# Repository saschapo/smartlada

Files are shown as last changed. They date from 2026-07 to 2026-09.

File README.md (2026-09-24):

# SmartLada — smart VAZ-2106 tail light

Firmware and custom hardware for a "smart" VAZ-2106 tail light: PWM dimming of the four
lamps (turn / brake / marker / reverse) with a local OLED menu, animation effects, and
**Zigbee control from a Yandex Station (Alice)**. Runs on a custom board that drops into
the light housing and is powered over **USB-C PD**.

Project page: **[smartlada.saschapo.me](https://smartlada.saschapo.me)** (source in [`site/`](site/)).

The current, primary firmware is **[`SmartLadaRevC/`](SmartLadaRevC/)** — it targets the
Rev C product board and is what the project ships. Everything else in the tree is either
the hardware design or earlier development stages (see [Lineage](#lineage)).

## Main firmware — SmartLadaRevC

ESP32-C6-WROOM-1 firmware for the Rev C board. Four PWM lamp channels (low-side MOSFET,
gamma + soft-start), an OLED menu with four buttons, pluggable effects, and a Zigbee end
device exposing five endpoints to Alice (four individual lamps + a "Fara" master/effects
device). Local control and Zigbee share one state (`config::s`, last-writer-wins).

Full details: **[`SmartLadaRevC/README.md`](SmartLadaRevC/README.md)**.

### Hardware (Rev C board)

<p align="center">
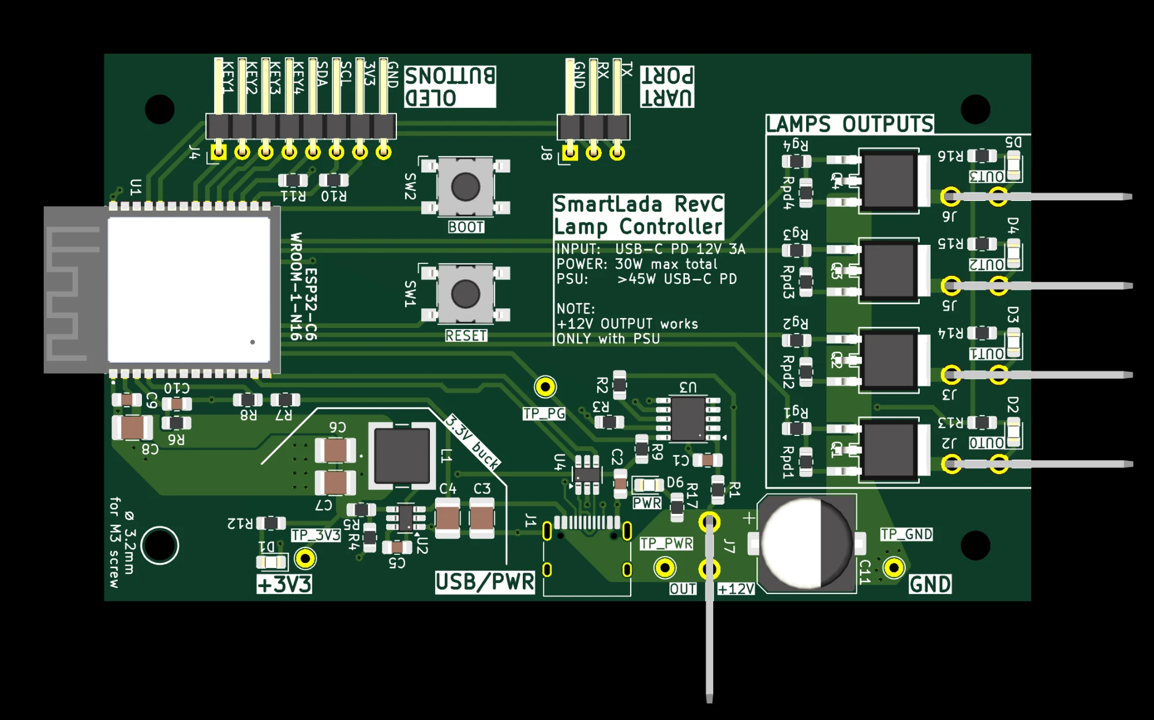
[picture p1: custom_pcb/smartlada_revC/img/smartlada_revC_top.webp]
SmartLada Rev C, top side
  
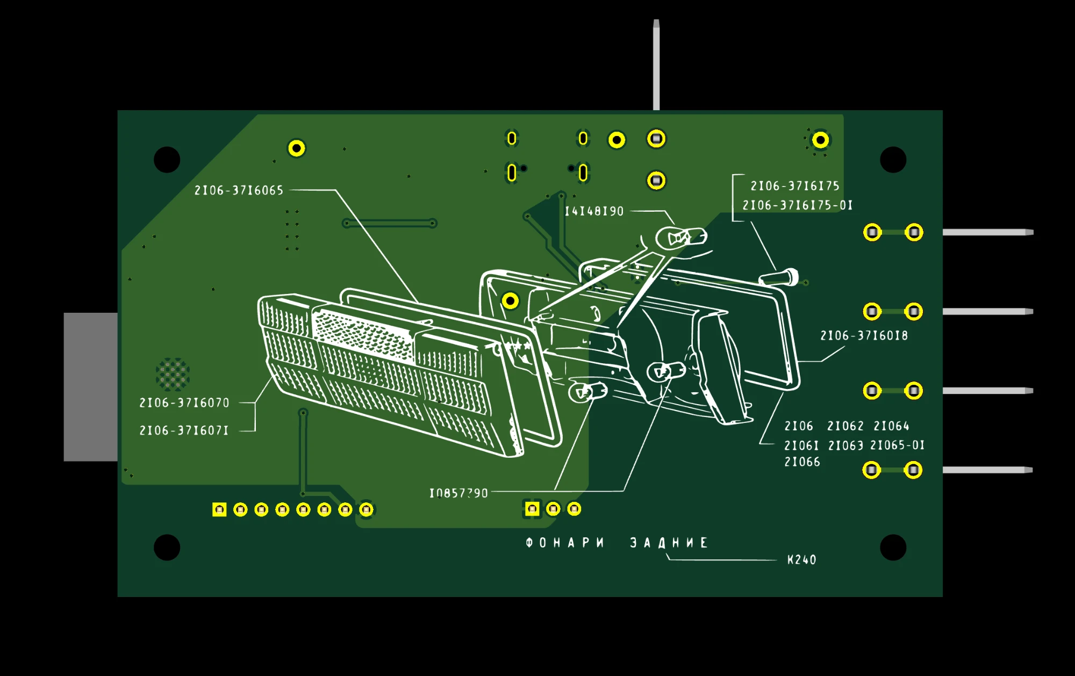
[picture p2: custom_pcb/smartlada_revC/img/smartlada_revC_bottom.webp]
SmartLada Rev C, bottom side
  
</p>
<p align="center"><sub>Rev C, KiCad render. Top: ESP32-C6 module, buck, PD trigger, four lamp MOSFETs with
Faston outputs. Bottom: the silkscreen carries the VAZ-2106 tail-light exploded view from the parts
catalogue ("ФОНАРИ ЗАДНИЕ").</sub></p>

- **MCU:** ESP32-C6-WROOM-1-N16 (integrated on the board).
- **Power in:** USB-C PD, **12 V / 3 A trigger** (CH224K). 12 V feeds the lamps directly;
  a **TPS54202 buck** makes 3.3 V for the MCU/OLED. No 12 V → holds 5 V (logic alive, lamps dark).
  Recommended PSU: **COMMO Core** (a model with a 12 V/3 A PDO).
- **Lamp switches:** 4× AOD4184 N-MOSFET (low-side, gate active-high), outputs on **6.3 mm
  Faston tabs** with a common +12 V. Lamps: 12 V incandescent (e.g. 10+10+10+5 W).
- **UI:** SSD1315 OLED (I²C) + 4 buttons on connector J4, cabled out of the housing.
- **Diagnostics:** 6× red 0805 LEDs (4 channels + 12 V + 3.3 V); PG (power-good) → GPIO.

Board design (KiCad, BOM, fabrication): **[`custom_pcb/smartlada_revC/`](custom_pcb/smartlada_revC/)**.

### Build & flash

Zigbee end-device build, Serial over native USB:

```sh
FQBN="esp32:esp32:esp32c6:ZigbeeMode=ed,PartitionScheme=zigbee_8MB,CDCOnBoot=cdc,FlashSize=16M"
arduino-cli compile -b "$FQBN" SmartLadaRevC
arduino-cli upload  -b "$FQBN" -p /dev/cu.usbmodemXXXX SmartLadaRevC
```

Bench variant with the 2.4" TFT + encoder module in place of the OLED + keys: build flag
`UI_TFT`, see [`SmartLadaRevC/README.md`](SmartLadaRevC/README.md#bench-variant-24-tft--encoder-ui_tft).

Plan and resume notes: [`SmartLadaRevC/DEV_PLAN.md`](SmartLadaRevC/DEV_PLAN.md),
[`SmartLadaRevC/SESSION_HANDOFF.md`](SmartLadaRevC/SESSION_HANDOFF.md).

## Lineage

The firmware grew through several stages; the earlier ones are kept for reference:

- [`sketches/SmartLada/`](sketches/SmartLada/) — first bring-up bench on an **ESP8266**
  (calibration, OLED). Its `channels/` and `config/` layers seeded the ESP32 port.
- [`SmartLadaC6/`](SmartLadaC6/) — **ESP32-C6 on a MuseLab nanoESP32-C6** dev board:
  LEDC PWM, Wi-Fi AP + web UI, test modes. First C6 firmware.
- [`SmartLadaRevB/`](SmartLadaRevB/) — display-based firmware (OLED menu + effects) on the
  Rev B board; direct **predecessor to Rev C** (Rev C forks its `src/` layers).
- **[`SmartLadaRevC/`](SmartLadaRevC/)** — current product firmware (this board + Zigbee).

Hardware history lives under [`custom_pcb/`](custom_pcb/) (Rev A → Rev B → Rev C);
research and architecture notes under [`research/`](research/); experimental sketches
under [`sketches/`](sketches/).

## Project context (Russian)

Historical planning/context documents, kept in Russian on purpose:

- [`PROJECT_2106_SMART_LIGHT.md`](PROJECT_2106_SMART_LIGHT.md) — decisions, hardware, architecture, plan.
- [`VAZ2106_Smart_Lamp_Context.md`](VAZ2106_Smart_Lamp_Context.md) — earlier context document.
- [`TASK_smartlada_bench_esp8266.md`](TASK_smartlada_bench_esp8266.md) — ESP8266 bench spec (done).
- [`schematic_2106_ESP32.md`](schematic_2106_ESP32.md) — early wiring schematic.

> Chat and `.md` documentation are in Russian; firmware code, comments, and identifiers are in English.

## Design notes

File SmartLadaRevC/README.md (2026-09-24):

# SmartLadaRevC

Firmware for the **SmartLada Rev C** board (ESP32-C6-WROOM-1) — the primary firmware of the
project. Controls four 12 V lamps of a VAZ-2106 tail light with PWM dimming, an OLED menu,
animation effects, and Zigbee control from a Yandex Station (Alice). Local (buttons/OLED)
and remote (Zigbee) control share one state, last-writer-wins.

Forked from `../SmartLadaRevB`; the `src/` layers are reused, plus a Zigbee layer.

## Features

- **4 PWM lamp channels** — LEDC, per-channel gamma + min/max window + soft-start slew.
- **OLED menu** (SSD1315, I²C) driven by 4 buttons: mode, brightness (per-channel + master),
  effect timings, lamp calibration (gamma/soft-start/levels/PWM freq), display, factory reset.
- **Effects**: Breathe, Turn (turn-signal-only blink, 1.5 Hz), Chase, Fade, Drive (a random
  but logical driving-scenario FSM: cruise/brake/stop/turn/reverse/hazard/parked).
  **Chase** runs on a trigger clock: every `Step` a lamp is lit and runs its own
  `Fade In -> On -> Fade Out` envelope, which may outlive later triggers — that overlap is
  what makes lamps dissolve into each other. `Random` picks the next lamp instead of walking
  in order (never the one just lit), turning the same envelope into scattered flicker.
- **Zigbee end device** — five endpoints to Alice:
  - `EP10..13` — the four lamps by function: **Turn / Marker / Reverse / Stop** (`ZigbeeDimmableLight`).
  - `EP14` "Fara" (`ZigbeeColorDimmableLight`) — the **effect layer and nothing else**:
    **color = effect selector**, **level = effect brightness**; **off and white both mean
    "no effect"**. EP14 never touches per-lamp levels.
- **Radio is a choice, not a pair.** The C6 has one 2.4 GHz radio. The libraries are built
  with software coexistence and both stacks do link together, but in practice a phone could
  not join the access point while the Zigbee stack was up. So exactly one protocol owns the
  band per boot, the choice is persisted, and switching reboots (Settings -> WiFi or
  Settings -> Zigbee on the device; one-way from the web page).
- **Wi-Fi + web UI** (Zigbee is the default): access-point first, because a car has no network
  to join -- the lamp hosts `fara_NNNN` (password `smartlada`, both editable from the page),
  with a join QR on the OLED that swaps to the address QR once a phone has associated. Station
  credentials are still honoured if stored, for bench use. The page is served from flash, so a
  firmware update carries it along and there is no filesystem image to upload. The browser is
  just another writer of the same state as the menu and Zigbee, and mirrors every setting.
- **Event log on flash** (`/log`, `/log.1`, `/clearlog`) and **firmware upload over Wi-Fi**
  (`POST /firmware`), so a bench session needs neither a cable nor a serial monitor.
- Settings + effect timings persisted in NVS, and **restored on power-on**: any change —
  local or remote — is written once it has stopped moving for 4 s.

## Architecture

Thin `.ino` wiring; logic in `src/*` layers. **`config::s` is the single source of truth**;
the menu and the Zigbee callbacks both write it (last-writer-wins), and the loop composits it:

```
setup(): channels::begin -> display -> config::load -> fx::loadParams
         -> setFreq/Calib/SoftMs -> buttons -> menu -> zb::begin (non-blocking join)
loop():  buttons::poll -> menu::update -> zb::update -> [zb::consumeDirty -> menu redraw]
         fx::compute(mode, now, master, lampOn, staticBri, out[4])           // compositor
         channels::write(now, out)                                            // slew -> gamma -> LEDC
         menu::render()                                                       // redraws only on change
```

| Layer | Role |
|---|---|
| `src/channels` | LEDC PWM (10-bit), soft-start slew on duty, gamma + min/max remap |
| `src/fx` | effects + the compositor (`compute`) |
| `src/input` | 4 buttons, debounce + accelerating repeat (EC11 encoder with `UI_TFT`) |
| `src/display`  | SSD1315 over Adafruit_SSD1306 (ST7789 TFT with `UI_TFT`) |
| `src/ui` | OLED menu state machine |
| `src/config` | NVS-backed `Settings` (`config::s`) |
| `src/net` | Zigbee endpoints + callbacks -> `config::s` |

### Compositor / control model

The `mode` alone picks the layer; EP14 (Fara) is the effect layer, EP10-13 (lamps/group) the
static picture:

- **Effect (mode ≠ 0)** → animation frame × `master` (effect brightness), across all 4 channels.
  Min Level remaps the **master**, not each frame value: `duty = frame^γ × remap(master)`, so at
  master 1% the effect peaks at Min Level and keeps its shape (Breathe still dips to dark).
- **Brightness remap** (Lamp Setup Min/Max Level + gamma): 0% = off, 1% = Min Level,
  100% = Max Level. In static every lit lamp at master > 0 stays at or above Min Level.
- **Static (mode 0)** → per-channel `staticBri`, gated by `lampOn`, then scaled by `master`.
  The master is a **ceiling**, in the spirit of Lamp Setup's Max Level: at 100% nothing is held
  back, and lowering it pulls the whole picture down while the lamps keep their relative
  balance. It is the same master that sets effect brightness, so one fader means one thing in
  both layers. Alice's group dimmer writes `staticBri`, so group and master do compound --
  which is what a ceiling is for.
- **EP14 (Fara)**: off **and** white → no effect (mode 0); color → effect (hue selects it).
  Its level is **always** the effect brightness and never fans out to `staticBri`. Fara never
  turns lamps off. A second group dimmer used to live here (white fanned its level out to
  every lamp); it duplicated EP10-13, flattened per-channel levels on every color change and
  read as a half-finished effect, so it was removed. Group brightness and "set the turn signal
  to 50%" both belong to EP10-13, which already handle group fan-out and per-lamp addressing.
- **Timing**: one time constant shapes everything — Lamp Setup's soft start (`softMs`) is the
  channel slew for both static dimming and effect edges, which is what gives Turn its ramp.
  The slew runs on the output duty (after the remap), so a fade to 0 drops through Min Level
  in ~tau instead of parking there. Effect brightness **from Zigbee** additionally eases on its
  own constant (`MASTER_SMOOTH_MS` in the .ino), because the app delivers level in bursts of
  ~10 commands and then holds for about a second. Local edits (buttons, web) and any target of
  0 bypass that easing, so the OLED DOWN 1% -> 0% takes exactly the soft start.
- **EP10-13 (lamps/group)**: on/off → `lampOn`, level → `staticBri`. Lamp commands never change
  the mode (a level does not force the lamp on, so an Alice group dim leaves off lamps dark).
- The local menu writes `mode` / `staticBri` directly, so it is authoritative (last-writer-wins).

### Yandex color preset compatibility

EP14 receives hue/saturation unchanged, but suppresses automatic reports of those two
attributes before processing color commands. It continues to report brightness/on-off;
EP10–13 reporting is unaffected. Local effect changes do not update the app's color selector.
This is a compatibility workaround, not a correction to the color values.

Hardware investigation on 2026-09-06 (Arduino-ESP32 **3.3.10**) found that even a single
combined H/S report, identical to the received command, could replace a Yandex preset with
an unnamed color. With color reports disabled, white/color transitions, reopening the
device card and changing brightness preserved the preset. Sending one unchanged white
report reproduced the replacement. The precise station/app conversion causing this remains
unknown; no saturation scaling or preset-specific offsets are applied.

Implementation: `onApsIndication()` in `src/net/zigbee.cpp`, chained to Arduino's existing
APS handler so binding-list processing continues. Incoming color attributes remain readable.

Known limits, all still open:

- The hook chains `zb_apsde_data_indication_handler()`, an **internal symbol of Arduino-ESP32
  3.3.10** — not public API. A rename breaks the build loudly; a change in *when* the core
  calls the APS handler would break the workaround silently. Recheck after any core upgrade.
- Installation can fail quietly: if the Zigbee lock is not acquired at start-up the firmware
  logs one line and runs **without** the workaround.
- Reporting is stopped on an incoming Color Control command, so a `Configure Reporting` from
  the coordinator (re-pairing, re-initialisation) re-arms it until the next such command.
- Re-pairing and other controllers are unvalidated. A cross-check on zigbee2mqtt or ZHA would
  say whether this is Yandex-specific interpretation or genuine attribute incoherence
  (`ColorMode` 0x0008 vs `EnhancedColorMode` 0x4001 vs the unmaintained `CurrentX/Y`).

## Pin map (ground truth, from the PCB netlist)

```
Lamp channels:  turn=IO0  marker=IO1  reverse=IO2  stop=IO3   (low-side AOD4184, gate active-HIGH)
                (ch index = function; those GPIOs land on Fastons OUT1/OUT0/OUT2/OUT3)
Buttons (J4):   KEY1=IO23 KEY2=IO22 KEY3=IO21 KEY4=IO20  (active-LOW, INPUT_PULLUP)
I2C (OLED):     SCL=IO18  SDA=IO19   addr 0x3C
Native USB:     D-=IO12   D+=IO13    (CDCOnBoot=cdc)
UART debug J8:  TX=IO16   RX=IO17
PD power-good:  IO10  (open-drain, active-LOW: LOW = 12 V present)
VBUS sense:     IO4   (ADC; divider R7=100k/R8=33k)
Strapping:      BOOT=IO9 (SW2)   RESET=EN (SW1)
```

Note: each MOSFET gate has a **100 k pulldown** (Rpd1..4) + 100 R series (Rg1..4) in
hardware; `channels::begin()` also runs first in `setup()` to force the outputs low at boot.
The USB-C **VBUS pins are the +12 V net** — it feeds both the buck (→3.3 V for the ESP) and
the lamp common (J7) + indicator LEDs, so a cold-boot lamp inrush can brown out the ESP.

## Build & flash

```sh
FQBN="esp32:esp32:esp32c6:ZigbeeMode=ed,PartitionScheme=zigbee_8MB,CDCOnBoot=cdc,FlashSize=16M"
arduino-cli compile -b "$FQBN" SmartLadaRevC          # always compile before uploading
arduino-cli upload  -b "$FQBN" -p /dev/cu.usbmodemXXXX SmartLadaRevC
```

- **`ZigbeeMode=ed` + the `zigbee_8MB` partition are required** (the firmware includes the
  Zigbee stack). `CDCOnBoot=cdc` routes `Serial` to native USB.
- **LEDC on the C6 clocks from 40 MHz**, so `RES_BITS = 10` (max PWM ≈ 40e6/2^10 ≈ 39 kHz;
  the 20 kHz default and the whole menu range fit). Higher resolution would cap below 20 kHz.
- Zigbee bonding lives in the `zb_storage` partition and survives reflash — **no need to
  re-pair**. Bumping `config::MAGIC` resets settings once on the next boot.
- Zigbee-stack logs go to **UART0 (J8)**, not USB-CDC; on USB you only see the firmware's own
  `Serial.printf` (`ZB Fara/lamp ...`). Headless capture: `stdbuf -oL cat /dev/cu.usbmodemXXXX > log`.
- **Opening the USB serial port resets the board** (it shows up as `rst USB` on the next boot
  line), even with DTR/RTS cleared beforehand. So starting a capture reboots the device, and
  the serial log cannot be watched during a BLE session at all -- the port open would kick the
  board out of OTA mode.

### Firmware over BLE

No USB needed: **Settings -> System -> Update Over BLE -> Yes** reboots into a dedicated OTA
mode (Zigbee is not started, so the radio is free) and advertises as `SmartLada`. Then

```sh
uv run --with bleak python3 tools/ble_ota.py path/to/SmartLadaRevC.ino.bin
```

- **Run this with the board on PD 12 V.** Powered from USB 5 V the transfer degrades to
  ~6.5 KB/s and stalls partway through (`stalled (no ack)` -- the link stays up but the board
  stops acknowledging blocks). On 12 V the same image goes through at 19-23 KB/s.
- Any button leaves OTA mode. The exit only arms once every key has been released, so the
  button held from the confirm screen does not immediately cancel.
- A link lost *after* `FINISH` does not cancel the update: the image is complete by then and
  only an explicit ABORT stops the commit. `--drop-after-finish` exercises exactly that.

## Bench variant: 2.4" TFT + encoder (`UI_TFT`)

A build flag swaps the OLED + 4 keys for the 2.4" ST7789 (240x320) + EC11 module from
[`sketches/Ec11Tft24Test`](../sketches/Ec11Tft24Test/README.md). Default builds are unchanged.

```sh
arduino-cli compile -b "$FQBN" --build-property "compiler.cpp.extra_flags=-DUI_TFT=1" SmartLadaRevC
```

```
header        module      GPIO        header        module   GPIO
J4-8          GND         -           J4-3          A        IO21
J4-7          VCC (3V3)   -           J4-2          B        IO22
J4-6 (SCL)    SCL = SCLK  IO18        J4-1          PUSH     IO23
J4-5 (SDA)    SDA = MOSI  IO19        J8-2 (RX)     CS       IO17
J4-4          DC          IO20        J8-3 (TX)     RES      IO16
BLK, K0: not connected
```

- The panel needs real CS and RES, and J4 has only six signals, so both come from the J8 debug
  UART. **This build has no UART0 console**, including the Zigbee-stack logs that normally go there.
- The menu code is untouched: it still draws into the 128x64 SSD1306 buffer, which `display()`
  shows pixel-exact at the largest integer scale that fits (portrait, 240 wide: x1, centred;
  a landscape rotation would give x2) and streams only the rectangle that changed since the last
  frame, at 40 MHz. The module has no TE line, so full-screen motion (the menu carousel) can
  still tear.
- Encoder: CW = UP, so values rise; `menu::update` swaps its list navigation under `UI_TFT` so
  CW also steps lists forward. Short PUSH (on release) = SEL, hold 0.6 s = BACK. A detent within
  250 ms of the previous one counts as "held", so step acceleration ramps and the deferred NVS
  save waits until the knob stops.
- BLK is not driven, so the display-brightness setting does nothing; only the dim-on-timeout
  state greys the picture (~25%).
- Bring-up tools: [`sketches/RevCTftEnc`](../sketches/RevCTftEnc/RevCTftEnc.ino) (panel +
  encoder, soft-reset check) and [`sketches/RevCTftDiag`](../sketches/RevCTftDiag/RevCTftDiag.ino)
  (colour cycle, IO_MUX / GPIO-matrix dump, pad drive A/B).
- CS->GND + RES->3V3 (to stay on J4 alone) left the panel white, but that test ran on a board
  with a badly soldered U1, so it proves nothing either way. It would be fragile regardless:
  with CS tied low one spurious SCLK edge misaligns the stream until a power cycle.

## Screen capture (`SCREEN_DUMP`)

Menu screenshots come straight from the firmware's frame buffer, so they cannot drift from the
code. A capture build (either display variant) prints every changed frame on USB serial as
`SCR <millis> <2048 hex>` (the raw 128x64 page buffer) and takes keys as single chars
(`U`/`D`/`S`/`B`, `+` = hello with the UI variant). [`tools/screens.py`](../tools/screens.py)
walks the menu and renders the result:

```sh
arduino-cli compile -b "$FQBN" --build-property "compiler.cpp.extra_flags=-DUI_TFT=1 -DSCREEN_DUMP=1" SmartLadaRevC
uv run tools/screens.py capture --force-out     # -> site/screens/ (frames.json, png/, anim/, contact.png)
uv run tools/screens.py render --scale 6 --fg f2f2f2   # re-render the saved frames, no board
```

- Opening the port resets the board, so every capture starts from a fresh boot (splash, idle,
  all cursors at 0). The walk only enters and leaves screens: no `ok` inside Zigbee / WiFi,
  confirm screens are left while they say No, and it stops if a key gets no reaction.
- `--force-out` enables Force Out after boot (it is RAM-only), so idle shows the main screen on
  USB power instead of "NO 12V". It drives the lamp FETs from USB 5 V: **disconnect the lamps.**
- Dumping is on from boot so the splash is caught. With the port open but unread the serial
  writes can stall the loop, so flash a normal build afterwards.
- `uv run tools/screens.py shell` drives the menu by hand and saves screens by name (e.g. an
  effect's Timings page, which the default walk only sees in Static mode).

## Status & roadmap

Hardware fully brought up; Zigbee integrated and paired to a Yandex Station (5 devices,
effects by color, local menu in parallel). Open items (see [`DEV_PLAN.md`](DEV_PLAN.md) and
[`SESSION_HANDOFF.md`](SESSION_HANDOFF.md)):

1. **Report-back board→Alice** — reflect state changes (mode/brightness) back to the app.
2. **PD-gating** on PG (IO10) + a debug bypass to drive outputs at 5 V without lamps.
3. Effect set curation for the hue→effect map.
4. **Wi-Fi / web UI** (cineink-style: QR provisioning, `smartlada.local`) with a Wi-Fi↔Zigbee toggle.

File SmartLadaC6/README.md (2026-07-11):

# SmartLada C6 — PWM bring-up bench (ESP32-C6)

Port of the [SmartLada (ESP8266)](../sketches/SmartLada/) bench to the ESP32-C6 N16. The goal of
this stage is to verify 4 channels on **hardware PWM (LEDC)** without a Zigbee
coordinator. Control is temporarily via Wi-Fi AP + web UI (the same as on ESP8266). The
final target is Zigbee on the C6.

> **Status: fw 0.7.0-c6, flashed and working (2026-07-11).** Verified on live lamps:
> 4 channels, master, 5 dynamics test modes + DRIVE (driving-simulation state machine),
> NeoPixel indication, BOOT button (mode switching + smooth master-brightness dimmer),
> web-editable mode timings. Calibration baked into defaults. Next — Zigbee.

## What was ported, what was rewritten

| Layer | Status on C6 |
|---|---|
| `src/channels/` | ported **unchanged** (pure C++: gamma, min/max, cap, soft-start) |
| `src/config/` | ported; GPIO 0..3, defaults = captured calibration, PWM range 10–30000 Hz |
| `src/platform_pwm/` | **rewritten** from ESP8266 `analogWrite` to **LEDC** (10 bit, `ledcAttach/ledcWrite`) |
| `src/anim/` | **new** — mode engine: 4 PWM tests with web timings (CHASE/SEQ/PULSE/ALT) + TURN + DRIVE (driving-simulation state machine) |
| `src/web/` | `WebServer`/`WiFi` (arduino-esp32); UI rewritten (dark theme, master, modes, version) |
| `src/status/` | **new** — NeoPixel: network status in MANUAL, active-mode color in animations |
| `src/button/` | **new** — BOOT button: mode switch + master-brightness dimmer |
| `src/version.h` | `FW_VERSION` — Serial at startup, `/status`, UI header |

## Channel map (ESP32-C6)

| Idx | Key | Name | Power  | GPIO |
|-----|---|---|---|---|
| CH0 | `stop` | Stop | 10 W | GPIO0  |
| CH1 | `reverse` | Reverse | 10 W | GPIO1  |
| CH2 | `turn` | Turn | 10 W | GPIO2  |
| CH3 | `marker`  | Marker  | 10 W | GPIO3  |

Lamps — **R10W 12V BA15S** on all channels. 40 W / 3.33 A total at 12 V.

**Why these pins.** The C6 strapping pins — `GPIO4, 5, 8, 9, 15` — are off-limits for
channels. Also taken: `GPIO8` = onboard NeoPixel, `GPIO12/13` = native USB, `GPIO24..30`
= SPI flash. `GPIO0..3` — not strapping, ADC1, can do LEDC; at boot they are inputs with
no pull, so the D4184 module's gate pulldown holds the low-side channel off. Pins are set
in `src/config/config.cpp` (`CHANNEL_DEFS`); the `gpio` field from imported JSON is
ignored (live re-pinning on a power bench is dangerous).

Board and full GPIO map (strapping, USB, flash) — [docs/board_nanoESP32-C6.md](docs/board_nanoESP32-C6.md).

## Indication (onboard NeoPixel, GPIO8)

`neopixelWrite` is built into the arduino-esp32 core (RMT), no external library needed.

In **MANUAL** — network status; in animations — the mode's signature color.

| State | Color |
|---|---|
| MANUAL, AP client present | steady green |
| MANUAL, AP with no clients | slow blue "breathing" |
| TURN | amber, blinking |
| CHASE | cyan, blinking |
| SEQ | green, blinking |
| PULSE | violet, "breathing" |
| ALT | red, blinking |
| DRIVE | in sync with the lamp: turn→yellow, reverse→white, stop→red, driving with marker→steady dim white |

## Build and flash (arduino-cli)

Core `esp32:esp32` 3.3.x. Everything is in the stock core (LEDC, WebServer, NeoPixel) —
no extra libraries.

```sh
FQBN="esp32:esp32:esp32c6:FlashSize=16M,CDCOnBoot=cdc,PartitionScheme=app3M_fat9M_16MB"
arduino-cli compile -b "$FQBN" SmartLadaC6
arduino-cli upload  -b "$FQBN" -p /dev/cu.usbmodemXXXX SmartLadaC6
arduino-cli monitor -p /dev/cu.usbmodemXXXX -c baudrate=115200
```

`CDCOnBoot=cdc` routes `Serial` to the native USB (monitor on the same port).

## Usage

1. After startup all 4 channels = 0% (cap removed by default: `max_duty_cap = 100%`).
2. Connect to the Wi-Fi AP **SmartLada** (password `smartlada`), open **http://192.168.4.1**.
3. **MASTER** — a shared slider + ON 100%/OFF for all channels.
4. **MODE** — MANUAL + 5 PWM dynamics test modes (CHASE/SEQ/PULSE/ALT timings are
   editable in the "MODE TIMINGS" section, 100–10000 ms) + **DRIVE** (driving-simulation
   scenario, see [docs/TZ_drive_mode.md](docs/TZ_drive_mode.md)). Switching is instant;
   manual sliders are locked during an animation.
5. **CHANNELS** — per-channel sliders.
6. **GLOBAL** — `pwm_freq_hz` (10–30000), `soft_start_ms` (0–5000), cap,
   mode timings. **CONFIG JSON** — Export/Import.

### BOOT button (local control, GPIO9)

The onboard BOOT button acts as a local remote (`src/button/` layer):

| Gesture | Action |
|---|---|
| Short press | next mode, wrapping (MANUAL → … → DRIVE → MANUAL) |
| Hold (≥0.5 s) | smooth master-brightness dimmer, 0↔100% over 5 s |

**Master brightness** is a global multiplier on the final duty (`channels::setMasterPct`),
active **in all modes** including animations: holding during an animation smoothly
dims/brightens the whole scene. In **MANUAL** all lamps turn on at 100% base, so the
master dims them together (MANUAL is fully part of the mode ring). The dimmer direction
**alternates** from hold to hold; at a limit (0/100%) it is forced back into range.
Startup level is 100% (so animations are visible immediately), the first hold goes down.
Off/on is just dimming down to 0 / up from 0.

The level is visualized on the onboard NeoPixel: **0% — bright red**, **100% — full
green**, in between — white with **gamma correction** (b ∝ level^2.2), so brightness
changes evenly to the eye across the whole range (a linear scale was barely
distinguishable in the top third).

> GPIO9 is strapping only at boot (do not hold the button while powering up — it enters
> download mode); at runtime it is read as a regular input.

HTTP API: `GET /`, `GET /config.json`, `POST /config`, `POST /set?ch=N&pct=P`,
`POST /all?pct=P` (master), `POST /mode?id=N` (0=MANUAL..6=DRIVE), `GET /status`
(fw, ssid, clients, heap, freq, cap, mode, pct[]).

Animation modes (`src/anim/`): any manual action (`/set`, `/all`) resets the mode to
MANUAL. Brightness mapping (logic in `channels/`, shared with ESP8266):
`slider% → gamma → [min_duty..max_duty] → min(duty, cap) → soft-start ramp → LEDC`.

## ⚠️ When connecting power hardware

Power switch schematic (D4184, low-side) — [docs/mosfet_switch_D4184.md](docs/mosfet_switch_D4184.md).

Lamp source — **Ecola B2L080ESB**: regulated DC 12 V, 80 W, max 6.6 A, short-circuit /
overload protection. It is a DC block (not an electronic transformer), so low-side PWM on
the D4184 is correct. The 40 W / 3.33 A load is ~50% of the PSU, fine even with the cap
removed.

- **Common ground** C6 ↔ PSU GND is mandatory (PWM reference).
- **Fuse** on the 12 V output — **T4A slow-blow** (rated 3.33 A, below the PSU's 6.6 A
  ceiling, tolerates the soft-started inrush). The former T6.3–8 A was for 68 W — too much now.
- **Inrush.** A cold R10W filament is ≈ 1–1.5 Ω → ~8–10 A/lamp inrush. Absorbed by the
  soft-start ramp; **do not set `soft_start_ms=0` with these lamps**, especially when
  channels turn on simultaneously, or the PSU may trip (hiccup).
- The gate pulldown on each D4184 is mandatory; pins `GPIO0..3` are boot-safe, but that
  does not replace it. On first power-up verify "duty 0 = lamp off".

## Next stage

Zigbee firmware on the C6 (`ZigbeeDimmableLight`, 4 dimmable endpoints). The core already
has `PartitionScheme=zigbee*` options. The `channels/` layer and the calibration numbers
carry over unchanged; `web/` and `status/` (the AP part) are replaced by Zigbee logic.

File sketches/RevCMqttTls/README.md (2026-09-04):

# RevCMqttTls — Фаза 2.1: ESP32-C6 фонарь по MQTT/mTLS

Устройство-половина облачного пути: коннектится к mosquitto (`mqtt.saschapo.me:8883`) по
**клиентскому сертификату (mTLS)**, рулит 4 каналами из `cmd`, публикует применённое состояние
(retained) в `state`. Без Zigbee — чистый Wi-Fi + TLS.

Гейт 2.1: ESP32 подключается по cert, получает `cmd`, двигает канал, публикует `state`.
(Go-backend тут ещё не нужен — «бэкенд» имитируем `mosquitto_pub/sub` с сервера.)

Стенд: RevA плата + nanoESP32-C6, пины каналов Rev C `{1,0,2,3}`, NeoPixel GPIO8.
Контракт топиков — [`../../smarthome_backend/deploy/mqtt/README.md`](../../smarthome_backend/deploy/mqtt/README.md).

## 1. secrets.h (не коммитится)
```bash
cd "/Users/saschapo/Documents/Claude/Projects/VAZ smart light/sketches/RevCMqttTls" && cp secrets.example.h secrets.h
```
Открой `secrets.h`, впиши Wi-Fi SSID/пароль и вставь три PEM из `smarthome_backend/deploy/mqtt/out/`:
- `CA_CERT` ← `out/ca.crt`
- `CLIENT_CERT` ← `out/esp32-smartlada-01.crt`
- `CLIENT_KEY` ← `out/esp32-smartlada-01.key`

Распечатать содержимое для копипаста:
```bash
for f in ca.crt esp32-smartlada-01.crt esp32-smartlada-01.key; do echo "===== $f ====="; cat "../../smarthome_backend/deploy/mqtt/out/$f"; done
```
Сохраняй строки `-----BEGIN...`/`-----END...` целиком (raw-литерал `R"EOF(...)EOF"` держит переводы строк).

## 2. Сборка и заливка
```bash
arduino-cli compile -b "esp32:esp32:esp32c6:CDCOnBoot=cdc,FlashSize=16M,PartitionScheme=huge_app" sketches/RevCMqttTls
```
```bash
arduino-cli upload -b "esp32:esp32:esp32c6:CDCOnBoot=cdc,FlashSize=16M,PartitionScheme=huge_app" -p /dev/cu.usbmodem2101 sketches/RevCMqttTls
```
`huge_app` — с запасом по флешу (TLS+WiFi+MQTT тяжёлые; на дефолтном разделе ~84%). Монитор:
```bash
arduino-cli monitor -p /dev/cu.usbmodem2101 -c baudrate=115200
```

## 3. Проверка (гейт 2.1) — «бэкенд» имитируем вручную

После заливки в мониторе увидишь: `WiFi ok` → `MQTT connected` → `pub state seq=1` (NeoPixel зелёный).

**A. Смотрим публикуемое состояние** (как backend, на сервере; подставь пароль backend):
```bash
ssh -t root@178.217.99.181 "mosquitto_sub -h 127.0.0.1 -p 1883 -u backend -P 'ПАРОЛЬ_BACKEND' -t smartlada/smartlada-01/state -v"
```
Должно сразу прийти retained-состояние (ESP32 публикует его при подключении).

**B. Шлём команду** (как backend), лампа turn -> ON 50%:
```bash
ssh -t root@178.217.99.181 "mosquitto_pub -h 127.0.0.1 -p 1883 -u backend -P 'ПАРОЛЬ_BACKEND' -t smartlada/smartlada-01/cmd -m '{\"command_id\":\"t1\",\"set\":{\"turn\":{\"on\":true,\"brightness\":50}}}'"
```
✅ В мониторе ESP32: `cmd on ...` → `ch0 turn ON bri=50 -> duty=...` → `pub state ... command_id t1`.
В окне A прилетит новое состояние с `"command_id":"t1"`. Если к OUT0 подключена лампа — загорится ~50%.

**C. Выключение / другой канал:**
```bash
ssh -t root@178.217.99.181 "mosquitto_pub -h 127.0.0.1 -p 1883 -u backend -P 'ПАРОЛЬ_BACKEND' -t smartlada/smartlada-01/cmd -m '{\"command_id\":\"t2\",\"set\":{\"brake\":{\"on\":true,\"brightness\":100},\"turn\":{\"on\":false,\"brightness\":50}}}'"
```
Проверь, что оба канала отработали и в state оба обновились.

**D. Тест офлайна (LWT):** выдерни питание ESP32 → через ~keepalive backend-подписка в окне A
получит retained `{"online":false}` (LWT). Это то, по чему Фаза 2.2 отдаст Яндексу `DEVICE_UNREACHABLE`.

## Что дальше (Фаза 2.2)
Go-backend: `store.go` mock -> MQTT-клиент. `action` шлёт `cmd` с `command_id`, ждёт совпадающий
`state` (<=1.5с) -> `DONE`/`DEVICE_UNREACHABLE`; `query` читает кэш последнего `state`; LWT
`online:false` -> `DEVICE_UNREACHABLE`. Один mutex/seq на фонарь против гонок при групповых командах.

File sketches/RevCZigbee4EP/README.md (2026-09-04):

# RevCZigbee4EP — 4× DimmableLight на одном ESP32-C6 node

**Цель (gating-эксперимент).** Проверить, покажет ли «Дом с Алисой» **один** ESP32-C6 node
с **четырьмя** стандартными endpoint DimmableLight (EP10..13) как **четыре** независимые
лампы — каждая со своим вкл/выкл и своим диммером. Это вариант A против варианта B из
[`research/smartlada_alice_zigbee_multi_endpoint_summary.md`](../../research/smartlada_alice_zigbee_multi_endpoint_summary.md).
От результата зависит, жизнеспособен ли прямой Zigbee-путь до переноса в продуктовую
прошивку `SmartLadaRevC`.

Результаты фиксируем в живом чеклисте:
[`research/zigbee_alice_test_results.md`](../../research/zigbee_alice_test_results.md).

## Стенд

Плата **RevA** + девборда **MuseLab nanoESP32-C6** (wuxx, N16 = 16 МБ флеш).
Пины каналов взяты по **Rev C** — чтобы маппинг совпадал с продуктом.

| Что | Пин | Примечание |
|-----|-----|---|
| Канал OUT0 | GPIO1 | EP10, low-side D4184, active-high (больше duty = ярче) |
| Канал OUT1 | GPIO0 | EP11 (OUT0/OUT1 перекрещены относительно Rev A) |
| Канал OUT2 | GPIO2 | EP12 |
| Канал OUT3 | GPIO3 | EP13 |
| NeoPixel-статус | GPIO8 | onboard WS2812 девборды |
| Кнопка BOOT | GPIO9 | active-low; удержание 3 c = factory reset + rejoin |
| USB | GPIO12/13 | native USB-Serial-JTAG, лог 115200, `CDCOnBoot=cdc` |

Индикация NeoPixel: **синий мигает** — ищет сеть; **зелёный** — присоединился;
**белый мигает** — identify («Алиса ищет устройство»); **красный** — factory reset.

Маппинг endpoint → лампа (назначается проводкой + именем в приложении):
`EP10 поворотник · EP11 стоп · EP12 габарит · EP13 задний ход`.

> **[CRITICAL]** С подключёнными лампами и 12 В: общая земля плата ↔ БП, предохранитель
> на месте. Каналы принудительно OUTPUT+LOW до любой инициализации.

## Сборка и заливка

Девборда N16, поэтому `FlashSize=16M`; готового `zigbee_16MB` в ядре нет — используем
`zigbee_8MB` (app-раздел 3.4 МБ, скетч занимает ~18 %).

Компиляция (проверено, собирается чисто):

```bash
arduino-cli compile -b "esp32:esp32:esp32c6:ZigbeeMode=ed,PartitionScheme=zigbee_8MB,CDCOnBoot=cdc,FlashSize=16M" sketches/RevCZigbee4EP
```

Заливка (порт из `arduino-cli board list`, обычно `/dev/cu.usbmodemXXXX`):

```bash
arduino-cli upload -b "esp32:esp32:esp32c6:ZigbeeMode=ed,PartitionScheme=zigbee_8MB,CDCOnBoot=cdc,FlashSize=16M" -p /dev/cu.usbmodemXXXX sketches/RevCZigbee4EP
```

Лог:

```bash
arduino-cli monitor -p /dev/cu.usbmodemXXXX -c baudrate=115200
```

В Arduino IDE эквивалент: Tools → Zigbee mode = **Zigbee ED (end device)**,
Partition Scheme = **Zigbee 8MB with spiffs**, USB CDC On Boot = **Enabled**,
Flash Size = **16MB**.

## Порядок спаривания

1. Залить скетч, открыть монитор порта — увидеть `Joining network...` (синее мигание).
2. «Дом с Алисой» → добавить устройство → Зигби-устройство (открыть сопряжение на Midi).
3. NeoPixel станет зелёным, в логе — `Joined Zigbee network`.
4. Пройти чеклист T1.1..T1.7 из
   [`research/zigbee_alice_test_results.md`](../../research/zigbee_alice_test_results.md):
   сколько появилось карточек, независимые ли имена / on-off / яркость, что понимает голос,
   переживает ли reboot/rejoin.

## Логи: что мы вытаскиваем (reverse engineering)

Опросить NLP Алисы по Zigbee нельзя. Но можно логировать **всё, что Алиса шлёт нам** —
и по этому восстановить, как она мапит фразы на ZCL. Два уровня:

**Уровень 1 — декодированный ZCL (всегда включён).** На каждую команду хаба две строки:

```text
[12345] EP11 SET Level(0x0008) attr=0x0000 type=0x20 size=1 val=76 raw=4c
[12345] EP11 ch1 APPLY ON level=76 -> duty=...
```

- `[12345]` — millis()-таймстамп, чтобы **соотнести с произнесённой фразой** (говоришь —
  смотришь время в логе).
- `EP11` — на какой endpoint пришло (ключ к вопросу multi-endpoint: адресует ли Алиса
  каналы раздельно).
- `SET Level(0x0008) attr=0x0000` — кластер и атрибут (тут — CurrentLevel).
- `type/size/val/raw` — ZCL-тип, размер, декодированное значение и сырые байты.

Так видно: какой шкалой Алиса шлёт яркость (0..254 vs 0..100), в каком порядке идут
On/Off и Level, шлёт ли transition, что делает при «включи» без яркости и т.п. Логируются
и кластеры, которые обычная лампа игнорит (Groups/Scenes/Identify) — полезно для группы «Фара».

**Уровень 2 — сырой APSDE-фаерхоз (по требованию, отдельная сборка).** `setDebugMode(true)`
уже в коде, но APSDE-логи (пофреймовые src/dst endpoint, cluster, profile, LQI) печатаются
только при сборке с core-debug. Собрать «capture»-версию:

```bash
arduino-cli compile -b "esp32:esp32:esp32c6:ZigbeeMode=ed,PartitionScheme=zigbee_8MB,CDCOnBoot=cdc,FlashSize=16M,DebugLevel=verbose" sketches/RevCZigbee4EP
```

Даёт полный стек-трейс Zigbee (каждый фрейм, ZDO-сигналы, bind/unbind). Шумно —
включать только на сессию захвата непонятного поведения.

### Что прислать мне

Скинь из Arduino IDE лог со **штатной сборки** (Уровень 1), и рядом припиши **что говорил и
когда** («сказал „яркость поворотника 30“ на ~12.3s»). По таймстампам сопоставлю фразы с ZCL.
Если что-то ведёт себя странно (не адресует endpoint, игнорит команду) — тогда сними
Уровень 2 (verbose) на этот сценарий.

При старте после join печатается контекст сети:

```text
[..] NET short=0x1a2b pan=0x1234 channel=15
[NET] ieee (little-endian) = ...
```

## Переменная теста: DISTINCT_MODEL

Если Алиса **схлопнула** четыре endpoint в одну карточку (вариант B), это может быть из-за
одинакового `ModelIdentifier`. В `RevCZigbee4EP.ino` поставить `#define DISTINCT_MODEL 1`
(даст каждому endpoint своё имя модели `RevC-Lamp10..13`), перезалить, сделать factory
reset (BOOT 3 c) и спарить заново. Результат обеих попыток занести в чеклист (T1.1).

## Честные оговорки

- Zigbee-хаб Яндекса исторически придирчив к нестандартным устройствам. Профиль
  DimmableLight стандартный, шанс хороший, но multi-endpoint → отдельные entities —
  **эмпирический** вопрос, ровно ради него этот тест.
- Если не присоединяется вовсе — снять лог с `ZigbeeMode=ed_debug` + `DebugLevel=verbose`.
- Следующая фаза (цвет = селектор эффекта, ColorControl/HSV) — отдельным скетчем после
  того, как закрыт вопрос multi-endpoint.

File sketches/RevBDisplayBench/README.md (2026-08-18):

# RevBDisplayBench

Стенд для сравнения настроек обновления OLED (SmartLada Rev B). Несколько
пресетов «частота кадра панели (0xD5) + скорость шины I2C», живые метрики и
двигающийся квадрат для оценки плавности — по глазу и на камеру.

## Управление

| Кнопка | Действие |
|---|---|
| K1 (^) | следующий пресет (по кругу) |
| K2 (v) | режим заливки FULL ↔ PARTIAL |
| K3 (#) | скорость квадрата − |
| K4 (*) | скорость квадрата + |

Квадрат 15×15, движется влево-вправо бесконечно. Скорость 0…10: `0` — стоп,
`10` — полный цикл (туда-обратно) за 5 с.

## FULL vs PARTIAL (tearing)

У SSD1306/SSD1315 по I2C нет линии TE (frame-sync), поэтому настоящий vsync
невозможен: панель сканирует память на стекло асинхронно с нашей заливкой, и
движущийся квадрат «срезает» на 1–2 px (tearing). Рычаги — только уменьшать окно
заливки:

- **FULL** — заливается весь кадр (1 КБ, ~14–28 мс). Окно tearing большое.
- **PARTIAL** — заливаются только 2 страницы полосы квадрата в диапазоне столбцов
  старого+нового положения (~40 байт, <1 мс). Окно tearing схлопывается почти в
  ноль. В этом режиме экранная статистика замирает (обновляется по нажатию),
  живые `flush`/`fps` идут в Serial, чтобы не добавлять периодический полный
  перелив.

Сравнивай FULL/PARTIAL на камеру на одной скорости — разница по tearing должна
быть наглядной. Дополнительно 800k-пресеты (P3/P4) укорачивают окно и в FULL.

## Пресеты

| # | Имя | 0xD5 | I2C |
|---|-----|---|-----|
| 1 | DEFAULT | 0x80 | 400k |
| 2 | FASTCLK | 0xF0 (макс. частота кадра) | 400k |
| 3 | I2C 800 | 0x80 | 800k |
| 4 | MAXBOTH | 0xF0 | 800k |
| 5 | SLOWCLK | 0x00 (мин. частота кадра) | 400k |

На экране: индекс/имя пресета, `d5`, частота I2C, `flush` (время заливки кадра,
мкс) и `fps` (реальная частота перерисовки). Цикл перерисовывается максимально
быстро, поэтому `fps ~= 1 / flush`, и эффект скорости шины виден напрямую.

`0xD5`: старший ниблл — частота осциллятора (кадр панели), младший — делитель.
Выше частота → мельче/незаметнее полосы rolling shutter и меньше мерцание, ценой
чуть большего тока. `0x00` намеренно даёт низкую частоту кадра для сравнения.

## Сборка/заливка

```
arduino-cli compile --fqbn esp32:esp32:esp32c6:CDCOnBoot=cdc sketches/RevBDisplayBench
arduino-cli upload  --fqbn esp32:esp32:esp32c6:CDCOnBoot=cdc -p <PORT> sketches/RevBDisplayBench
```

Библиотеки: `Adafruit SSD1306`, `Adafruit GFX`.

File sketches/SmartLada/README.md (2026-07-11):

# SmartLada — PWM calibration bench (ESP8266)

Hardware bring-up for the smart light built from a VAZ-2106 tail light: 4× 12 V
incandescent lamps through 4 D4184 modules (N-MOSFET, low-side PWM). **This is NOT the
final firmware** — it's a bench for capturing calibration numbers while the ESP32-C6 is
in transit. The final target is Zigbee on the C6.

> **Status: prototype working (2026-07-06).** The wiring below is verified on real tail
> light lamps: 4 channels dim independently, no flicker.
> The captured calibration is in [calibration/](calibration/).

## ⚠️ Power bench — read before powering up

- **[CRITICAL] Common signal ground.** The ESP8266 GND (USB-powered) and the 12 V PSU
  GND must be tied together — otherwise PWM has no reference and switching is
  unpredictable. Note: "common ground" applies to the ESP and PSU, but NOT to the lamp
  negatives — the switched lamp terminals must be separate (see the schematic).
- **[CRITICAL] Fuse.** Slow-blow **T6.3–8 A** at the 12 V PSU output. 68 W total plus
  the cold-filament inrush — this is not a desktop toy.
- **[CRITICAL] The tail-light board is live.** In the verified wiring the common
  tail-light board is the +12 V bus (always "hot"). Do not let it touch anything tied to
  GND: the fuse will catch a short, but better without surprises.
- **D4184 polarity.** On first power-up, verify duty 0 = lamp OFF (no inversion). After a
  flash/reboot all lamps must be off.

## Wiring (verified on hardware)

A quirk of the 2106 tail light: the socket board structurally ties together the
"negatives" of all lamps (in the car the positive is switched, the negative is the
body). For low-side switching the switched terminals must be separate, so the wiring is
**re-polarized** — an incandescent lamp doesn't care about polarity. Only the side we do
NOT switch can be common:

```
12 V PSU (+) ──[fuse T6.3–8 A]──┬── common tail-light board (common POSITIVE of all lamps)
                                │        │ each lamp's filament
                                │   individual socket contact CHx
                                │        │
                                │   OUT− of its D4184 module (drain) — SEPARATE
                                │
                                └── VIN+ of the D4184 modules
12 V PSU GND ── VIN− of the D4184 modules ── ESP8266 GND   (common signal ground)
ESP8266 GPIO4/5/15/13 ── PWM inputs of the D4184 modules
ESP8266 power — separate, via USB
```

If the lamp negatives are joined before the switches (as they are stock in the tail
light), any open switch shorts the loop of all lamps at once — they all light and dim
together. Verified.

## Channel map: section → GPIO

| Idx | Key | Name | Power  | GPIO | Board label |
|-----|---|---|---|---|---|
| CH0 | `stop` | Stop | 21 W | GPIO4  | D2 |
| CH1 | `reverse` | Reverse | 21 W | GPIO5  | D1 |
| CH2 | `turn` | Turn | 21 W | GPIO15 | D8 |
| CH3 | `marker`  | Marker  | 5 W | GPIO13 | D7 |

Bench board — **HW-364A** (ESP8266 + onboard OLED). GPIO12/GPIO14 are taken by the
display's I2C, so CH2 sits on GPIO15 (D8) rather than GPIO12 from the spec.

**GPIO15 catch:** it is a strapping pin that must be LOW at boot (the board already has a
pulldown) — which is a plus for a low-side switch: the channel is guaranteed off at
startup. But nothing external must pull GPIO15 high at power-up, or the ESP won't boot.
The D4184 module's gate pulldown satisfies this; don't add external pullups on that line.

Selection criteria for the other pins: not strapping (GPIO0/2), not GPIO16 (no PWM);
channel off at boot (module gate pulldown, or add an external one). Pins are set in
`src/config/config.cpp` (`CHANNEL_DEFS`); on JSON import the `gpio` field is ignored —
live re-pinning on a power bench is dangerous.

## OLED display and FLASH button (HW-364A board)

Onboard SSD1306 128x64, I2C `0x3C`: **SDA = GPIO14 (D6), SCL = GPIO12 (D5)** — pinout
verified against [peff74/esp8266_OLED_HW-364A](https://github.com/peff74/esp8266_OLED_HW-364A).
The **FLASH = GPIO0** button switches pages (don't hold it on reset — that enters the
bootloader). Screen refresh — 2×/s; ASCII font, channel labels in Latin.

| Page | Contents |
|---|---|
| 1/3 Status | IP, MAC, AP clients, heap, PWM frequency, cap state, loop/s |
| 2/3 Channels | per channel: GPIO, % slider, current duty (soft-start visible) |
| 3/3 Calibration | per channel: gamma, min..max duty, soft_start_ms |

`loop/s` — the main-loop rate: dips show up during HTTP requests and display redraws,
useful for judging softPWM jitter. If the display is not found, the bench runs without
indication (`OLED not found` in Serial).

## Build and flash

Arduino IDE + ESP8266 core. Libraries: **Adafruit SSD1306** (+ Adafruit GFX, Adafruit
BusIO deps) — for the OLED only; PWM and web use the stock core. Open `SmartLada.ino`,
board NodeMCU 1.0 (HW-364A compatible), flash.

## Usage

1. After startup all 4 channels = 0%, cap `max_duty_cap = 60%` active.
2. Connect to the Wi-Fi AP **SmartLada** (password `smartlada`), open **http://192.168.4.1**.
   The page is fully self-contained (no internet/CDN).
3. 4 sliders — independent channel brightness; 0% = guaranteed physical off.
4. Per-channel calibration fields: `gamma` (1.8–2.6), `min_duty`/`max_duty` (0–1023),
   `soft_start_ms` (0–1000) — the "Apply" button.
5. Global: `pwm_freq_hz` (100–1000, default 150 — to find the softPWM ceiling) and the cap.
   "Remove cap" — a separate button with confirmation; the transition to full brightness
   goes through soft-start.
6. **Export JSON** — capture the current config for porting to the ESP32-C6.
   **Import JSON** — paste and apply a saved config.

Brightness mapping (order fixed):
`slider% → gamma → [min_duty..max_duty] → min(duty, cap) → soft-start ramp → PWM`.

**Config is not saved to flash** (intentional: force-safe start with defaults).
Save captured calibration numbers via Export JSON.

## Note on softPWM jitter

PWM on the ESP8266 is software-based. With active HTTP requests (slider movement, status
polling) brightness jitter is possible — that was an expected thing to check.

**Run result (2026-07-06):** no jitter observed by eye; the difference between 100 and
1000 Hz is indistinguishable — the thermal inertia of the filaments smooths everything.
100 Hz was chosen. Side observation: the switching PSU "sings" at the PWM frequency
(magnetostriction under pulsed load) — normal; higher frequency = higher and quieter tone.

## Architecture (layers)

```
SmartLada.ino        thin glue: force-safe start, setup/loop
src/channels/        [PORTED to C6]  pure duty math: gamma, min/max, cap, soft-start.
                     No Arduino/ESP8266/Wi-Fi includes at all.
src/config/          [PORTED to C6]  settings struct + JSON (pure C++).
src/platform_pwm/    [DISCARDED]     ESP8266 analogWrite*; on C6 → LEDC.
src/web/             [DISCARDED]     AP + HTTP + UI; on C6 → Zigbee.
src/display/         [DISCARDED]     OLED SSD1306 + FLASH button (HW-364A).
```

HTTP API: `GET /` (UI), `GET /config.json`, `POST /config` (same JSON),
`POST /set?ch=N&pct=P`, `GET /status` (MAC, heap, frequency, cap, percents).

## Next stage (outside this bench)

Zigbee firmware on the ESP32-C6 (`ZigbeeDimmableLight` / `HA_dimmable_light`),
4 dimmable endpoints, paired with a Yandex Station Midi. The `channels` layer and the
numbers from `config.json` carry over unchanged.

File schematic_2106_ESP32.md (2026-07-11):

# Схема: фонарь ВАЗ-2106 + ESP32-C6 (версия на лампах накаливания)

> **Вариант проекта:** аутентичный, на штатных лампах накаливания. Выбран осознанно;
> тепловой риск закрытого пластикового корпуса принят и решается мерами из раздела
> «Управление теплом». Альтернатива на LED описана в `PROJECT_2106_SMART_LIGHT.md`.

## Проект

Светильник на базе оригинального заднего фонаря ВАЗ-2106. Четыре штатные лампы
управляются через **ESP32-C6** и **4× MOSFET-модуля D4184** (по одному на лампу).
Яркость каждой лампы регулируется независимо через PWM.

Радио: **Zigbee**, ESP32-C6 как end-device, привязка напрямую к **Яндекс Станции Миди**.
Каждая лампа — отдельный **dimmable-light** эндпоинт (вкл/выкл + яркость голосом).

---

## Нагрузка

| Лампа | Мощность | Ток @12 В |
|---|---|---|
| Стоп | 21 Вт | ~1.75 А |
| Задний ход | 21 Вт | ~1.75 А |
| Поворот | 21 Вт | ~1.75 А |
| Габарит | 5 Вт | ~0.42 А |
| **Итого** | **68 Вт** | **~5.7 А** |

**Пусковой ток:** холодная спираль имеет сопротивление в ~10–15 раз ниже горячей →
бросок при включении кратковременно (единицы мс) превышает номинал в 8–12 раз.
Это влияет на выбор предохранителя, ключей и делает soft-start обязательным.

---

## Источник питания

- Вход: **220 В AC**
- Выход: **12 В DC**
- Мощность: **100–120 Вт** (запас на пусковой бросок сверх 68 Вт)
- Ток: **≥10 А**
- Тип: закрытый промышленный БП (напр. MeanWell LRS-100-12 / LRS-150-12).

**Предохранитель:**
- Тип **slow-blow (T)**, номинал **6.3–8 А**, максимально близко к выходу БП.
- Обоснование: номинал нагрузки 5.7 А, поэтому 10 А почти не защищает проводку;
  6.3–8 А защищает трассу, а slow-blow переживает пусковой бросок без ложных
  срабатываний. При реализованном soft-start можно брать нижнюю границу (T6.3 А).
- Защищает **проводку между БП и платами** от КЗ (собственная защита БП — не замена).

---

## ESP32-C6

- Питается **отдельно** (временно — через USB-C; в финале — 12→5 В buck от общего БП).
- Силовая линия ламп полностью отделена от питания C6.
- **Объединение только по земле (звезда, см. ниже).**

### GPIO (ESP32-C6, боот-безопасные)

Нельзя использовать под PWM (заняты / strapping / влияют на загрузку):
- **Strapping:** GPIO4, GPIO5, GPIO8, GPIO9, GPIO15
- **USB-JTAG:** GPIO12, GPIO13
- **SPI-flash:** GPIO24–GPIO30
- На DevKitC-1: **GPIO8** = встроенный RGB-LED; **GPIO16/17** = UART0 (порт программирования).

Безопасные под 4 канала PWM (LEDC): **GPIO0, 1, 2, 3, 14, 20, 21, 22, 23.**

| Лампа | GPIO (реком.) |
|---|---|
| 1 — Стоп | GPIO2 |
| 2 — Задний ход | GPIO3 |
| 3 — Поворот | GPIO22 |
| 4 — Габарит | GPIO23 |

Условие: у платы D4184 должен быть pulldown на затворе, чтобы при высокоимпедансном
состоянии GPIO во время boot лампа была ВЫКЛючена (иначе 21-ваттная нить может
моргнуть при включении). Выбранные пины не strapping → при загрузке не уходят в HIGH.

---

## MOSFET (4× D4184, по одному на лампу)

D4184 (AOD4184) — N-канальный logic-level MOSFET (~40 В, открывается от 3.3 В GPIO),
запас по току для 1.75 А огромный. Коммутация **низкой стороны** (по «минусу» лампы).

Подключение каждого модуля:
- `+ Power` → +12 В
- `− Power` → общая земля
- `PWM` → GPIO ESP32-C6
- `GND` → общая земля (GND ESP32)
- `LOAD+` / `LOAD−` → к своей лампе

Частота PWM платы — до ~30 кГц, но вести **~200–1000 Гц** (для накаливания оптимум,
тепловая инерция нити сглаживает импульсы; выше частота бессмысленна и лишь нагружает
раскачку затвора).

---

## PWM и soft-start

- Частота: **200–1000 Гц** (реком. ~500 Гц).
- **Soft-start обязателен** (не «желательно»): плавный рост duty за **200–500 мс** при
  включении. Снижает пусковой бросок → бережёт ключ, предохранитель и БП.
- В Zigbee-модели яркость приходит через кластер Level Control → маппится в duty LEDC
  с **гамма-коррекцией (~2.2)**. Плавный ramp яркости одновременно служит soft-start’ом.

---

## Общая земля (ЗВЕЗДА — не через корпус!)

Корпус фонаря 2106 **пластиковый и НЕ является проводником** — использовать его как
GND-шину нельзя. Все земли сводятся **проводом в одну общую точку** (звезда):

- GND БП 12 В
- GND ESP32-C6 (и его отдельного питания)
- `− Power` и `GND` всех 4 плат D4184

Общая земля обязательна: без единой опоры PWM-сигнал C6 не откроет ключи корректно.

---

## Лампы: изоляция от корпуса

Каждая лампа подключается **только к своему MOSFET**, шелл/возврат каждого патрона
**изолирован** от корпуса и от других ламп (не общая масса через отражатель).

Схема одной лампы (low-side):
```
+12 В ──► контакт лампы (+)
          лампа (нить)
          контакт лампы (−) ──► LOAD+
                                D4184
                                LOAD− ──► − Power / GND (общая земля)
```

Преимущества: независимость от штатной массы фонаря, нет паразитных токов через
корпус, простая диагностика, вся силовая коммутация — внутри MOSFET.

**Патроны:** для накаливания штатные патроны фонаря **сохраняются** (металл, рассчитаны
на жар ламп). Изолировать нужно только их «массовый» контакт от корпуса, разведя каждый
на свой MOSFET.

---

## Управление теплом (ключевой раздел для накальной версии)

Три-четыре лампы накаливания в закрытом пластиковом корпусе — источник тепла
100–250 °C на колбе; PETG размягчается ~80 °C, PLA ~55–60 °C. Меры:

1. **Термопредохранитель (thermal cutoff), 90–100 °C** в разрыв линии +12 В, закреплён
   у самой горячей внутренней точки. Единственный надёжный аварийный обрыв при перегреве.
   Дёшево и обязательно для закрытого накального корпуса.
2. **Зазор колба ↔ пластик:** нить/колба не касаются рассеивателя и стенок; воздушный
   промежуток. Все стойки/держатели рядом с лампами — **металл**, не пластик.
3. **Вентиляция:** отверстия снизу и сверху (конвекция, эффект дымохода). Компромисс с
   пылью — для светильника допустимо.
4. **NTC-термистор на ADC-пин C6:** прошивка мониторит температуру и снижает/срезает
   яркость при перегреве (используем то, что MCU уже внутри). Программный тепловой предел.
5. **Снижение тепловой нагрузки:** держать лампы преимущественно на пониженной яркости
   (PWM), либо рассмотреть лампы меньшей мощности (5–10 Вт) там, где не нужен полный накал.
6. **Отражатель** оставить металлическим — помогает распределять/излучать тепло.
7. **НЕ герметизировать** корпус полностью — оставить конвекционный путь.

---

## Конденсаторы (рекомендуется, не опционально для накала)

Пусковые броски и просадки на включении вероятны, поэтому:
- **1000 мкФ / 25 В** электролит на линии +12 В у кластера плат (ближе к БП/трассе).
- **100 нФ** керамика по месту (шунт ВЧ-шума).
- Небольшой конденсатор по питанию C6 (стабильность при переключении нагрузки).

Симптомы, если мало ёмкости: перезагрузки C6, шумы, нестабильность БП на старте.

---

## Итоговая схема (звезда по земле)

```
220 В AC
   │
┌──────────────────┐
│ БП 12 В / ≥10 А   │
└──────────────────┘
   │ +12V            │ GND
   ├── [T6.3–8A] ── [thermal cutoff 90–100°C] ──► шина +12 В
   │                                              │
   │                          ┌──────┬──────┬──────┴──────┐
   │                       Лампа1  Лампа2  Лампа3      Лампа4
   │                          │      │      │            │
   │                       LOAD+  LOAD+  LOAD+        LOAD+
   │                       D4184  D4184  D4184        D4184
   │                       LOAD−  LOAD−  LOAD−        LOAD−
   │                          │      │      │            │
   └──────────────────────────┴──────┴──────┴────────────┴──► ЗВЕЗДА GND ◄─┐
                                                                            │
   ESP32-C6:  PWM→GPIO2/3/22/23,  GND ──────────────────────────────────────┘
   (питание C6 — отдельно, USB-C временно / 12→5В buck в финале; GND в ту же звезду)

Общая точка «звезда GND»: GND БП + GND всех D4184 + GND C6 + GND его питания.
Корпус фонаря НЕ участвует в цепи земли (пластик).
```

---

## Практические рекомендации

- Провода питания: трасса +12 В и общая земля — **≥0.75–1.0 мм² (18–17 AWG)** (5.7 А);
  ветка на лампу — **≥0.5 мм² (20 AWG)** (1.75 А).
- Силовые соединения — обжим или пайка; предохранитель — у выхода БП.
- После сборки: **проверить температуру всех контактов и внутренних точек после
  10–15 мин на максимальной яркости**; убедиться, что термопредохранитель и NTC работают.
- Реализовать soft-start (200–500 мс) — обязательно при одновременном включении ламп.

---

## План следующего этапа

1. Bring-up на макетке: C6 + 1× D4184 + 1 лампа + БП 12 В (земли в звезду).
2. Поднять Zigbee dimmable-light, привязать к Станции Миди, проверить управление
   яркостью из Алисы (главный непроверенный риск).
3. Финализировать распиновку GPIO под конкретную плату C6.
4. Развести питание/землю по физике размещения внутри фонаря + тепловые меры.
5. Принципиальная + монтажная схема, сборка.
```

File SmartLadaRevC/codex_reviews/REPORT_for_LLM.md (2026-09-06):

# SmartLadaRevC — compact review handoff

Reviewed 2026-09-06: **1.0.6-revC**, working tree including uncommitted changes; Arduino-ESP32 **3.3.10**. Findings are review evidence, not instructions to implement every suggestion. Original scope: report only; no firmware edits or flashing. Follow the user's current task. Revalidate affected code before editing; line numbers describe this snapshot. Read targeted functions first; historical docs contain obsolete requirements.

**Evidence:** HOST = reproduced using actual project C++ with simulated hardware/time/Preferences; STATIC = source/library analysis, not device reproduction. No hardware/radio/electrical tests performed. P1 = prioritize; P2 = functional/reliability issue; P3 = minor. Hardware consequences remain unmeasured.

**Paths:** relative to `SmartLadaRevC/` (parent of this review directory). `INO=SmartLadaRevC.ino`, `M=src/ui/menu.cpp`, `Z=src/net/zigbee.cpp`, `B=src/net/bleota.cpp`, `C=src/channels/channels.cpp`, `F=src/fx/effects.cpp`, `K=src/input/buttons.cpp`, `CFG=src/config/config.cpp`.

## Preserve this control model

- Indoor decorative lamp, not automotive safety firmware. ESP32-C6-WROOM-1-N16, USB-C PD 12 V, incandescent loads and MCU buck share VBUS. Prior cold-start brownouts documented.
- Channels/GPIO: turn=0, marker=1, reverse=2, stop=3. PCB Fastons OUT0/OUT1 cross GPIO1/GPIO0; do not revert the function-based GPIO map.
- `config::s`: shared mutable state; menu runs in loop, Zigbee callbacks in another task. Intended last-writer-wins is not sufficient synchronization.
- `mode`: 0 Static; 1 Breathe; 2 Turn; 3 Chase; 4 Fade; 5 Drive.
- Static: `out[i] = lampOn[i] ? staticBri[i] : 0`; **no master multiplier**. Effects render all channels using `master`, intentionally ignoring static `lampOn/staticBri`.
- EP10–13 change static levels/on-mask, never mode; Level alone must not enable an off channel.
- EP14 Fara: off → Static; on+white (`sat<40`) → Static + level fan-out; on+color → hue-selected effect + effect brightness. Fara off does not turn all lamps off. Local static master enables all lamps and fans out brightness.
- Output: exponential smoothing → shared gamma/min/max LUT → 10-bit LEDC. `softMs` is τ, not ramp completion time. Static uses configured τ; effects use 20 ms; boot uses 1500 ms temporarily.
- Power gate: ADC GPIO4, divider 100k/33k, hysteresis off<7 V/on>8 V; PG GPIO10 diagnostic. Force Out bypass resets on reboot.
- BLE starts only in dedicated OTA boot mode; Zigbee does not start there. RTC request flag selects mode. Two OTA app partitions exist.

## Findings / acceptance targets

### R1 — P1 / HOST: remote effect change invalidates Timings editor

`M:650–668 SC_TIMINGS; M:822 notifyExternalChange`.
Repro: Chase → Timings → edit Fade (`cursor=1, editing=true`); change mode remotely to Drive or Turn. Redraw notification preserves editor state. Drive has `params=nullptr`; Turn has one param but `cursor=1` passes `cursor<nItems` because nItems includes Reset. `e.params[cursor]` reads invalid memory even before the next adjustment; adjustment can write it.
HOST: Drive → UBSan null reference + SEGV; Turn → ASan global-buffer-overflow.
Target: end/revalidate editing when mode changes; coherent mode snapshot; enforce `params!=nullptr && cursor<nparams` at access. Test remote changes during editing, including effects with zero/fewer params. Reset row is never a Param.

### R2 — P1 / HOST: boot smoothing includes pre-ramp initialization time

`C:40–69 begin/write; INO:65–86 setup`.
`s_lastMs` is set in channels::begin, before OLED/NVS/Zigbee initialization. Setting boot τ does not reset this clock. First write uses the entire initialization delay. Zigbee.begin can wait for stack startup; network joining later continues in background.
HOST counterexample: 2000 ms delay, target=255, τ=1500, default calibration → first write logical=187.78, PWM=578/1023 (56.5%), from previously zero output. **2 s is injected, not measured startup latency.** Brownout recurrence is a risk, not reproduced.
Target: initialize ramp time/state at actual ramp start; verify first PWM after short/long initialization. Also test 12 V arriving after setup: boot ramp is not restarted then. Document τ correctly: one τ reaches ~63% of logical target, not 100%.

### R3 — P2 / HOST: power inhibit is smoothed rather than immediate

`INO:115–118; C:64–69`.
Power gate zeroes target only; s_actual retains output. HOST: starting at full output with allowed τ=3000 ms, one second after inhibit PWM=549/1023 (53.7%). This is duty, not lamp power at the changed voltage.
Target: inhibit immediately zeroes PWM and smoothing state, independent of user τ; define safe ramp on power restoration. Test loss/return of supply and disabling Force Out while supply is low.

### R4 — P2 / HOST: held confirmation key exits OTA after reboot

`M:774–780; K:22–40; INO:94–101`.
Confirm OTA Yes and hold SEL through reboot. buttons::begin assumes released keys; held SEL becomes a fresh pressed edge after debounce. OTA loop interprets it as exit/reboot. HOST confirms edge at 26 ms after first held sample. **Possible explanation of handoff's failed menu entry, not proven cause of that incident.**
Target: arm OTA exit only after all keys are released; subsequently require a new press. Test held SEL through entry and ordinary exit afterward.

### R5 — P2 / STATIC: global echo guard discards genuine Zigbee commands

`Z:75–76 onFaraHsv; Z:132–157 doReport`.
Interleaving: loop sets s_reporting=true, waits for SDK lock in a setter; Zigbee task handles a remote command, calls onFaraHsv, which returns because of that same flag. Endpoint internal state changes but config::s does not. Device occurrence rate unknown.
Target: distinguish local setter callbacks from inbound commands; serialize application state updates or queue commands to one owner. Avoid lock-order deadlocks. `volatile`/atomic byte loads do not make multi-field updates or lampOn read-modify-write safe. **SDK setClusterAttribute already acquires Zigbee lock**; do not report all setters as unlocked. Test inbound commands during reporting.

### R6 — P2 / STATIC: OTA cancellation/restart races flash writer

`B:45–64 writerTask; B:76–81 disconnect; B:91–111 START/ABORT`.
Writer uses s_handle while disconnect/ABORT calls esp_ota_abort on it without waiting. s_receiving=false does not cancel an in-flight write. START accepts an already active session and replaces shared state/handle. OTA abort frees session resources: [Espressif API](https://docs.espressif.com/projects/esp-idf/en/latest/esp32c6/api-reference/system/ota.html).
Target: one owner executes begin/write/end/abort; callbacks enqueue requests; acknowledge cancellation after writer stops; reject concurrent START. Test disconnect/ABORT during write/finalization, then retry.
Related: xStreamBufferSend return ignored; declared total used only for progress, no exact byte-count check before FINISH. Validate these. **esp_ota_end does validate image; do not claim arbitrary truncated images are accepted or active firmware necessarily corrupted.** Writes target inactive slot.

### R7 — P2 / STATIC + HOST: remote state lacks persistence

`Z:43–57,75–90 callbacks; M:814–822; CFG:26–41`.
Remote callbacks change config and dirty redraw flag, never pendingSave. Repro: save local lamps-on, remote off, reboot → saved on-state returns. A subsequent unrelated local display edit persists entire config, including remote state. HOST reproduces persistence behavior with simulated Preferences; source confirms missing remote save path.
**Known roadmap gap, not necessarily new regression.** Target: explicit restart policy + common debounced persistence independent of writer; no NVS write per incoming dimming step. Verify remote-only changes/reboot and unrelated local edits.

### R8 — P2 / STATIC: local Static leaves stale effect state in EP14

`Z:150–155 doReport; Z:75–85 onFaraHsv`.
Effect report sets Fara on+color. Local Static report changes level only, preserving on+color. A subsequent changed EP14 Level invokes library callback with stale on/hue/sat and reactivates the old effect. Derived from installed library setters/callbacks; Alice tile behavior not measured.
White reporting was intentionally avoided due to documented Alice glitch; do not blindly remove workaround. Target: define coherent EP14 representation of local Static and next Level command; test effect → local Static → remote Level, off/on, and white fan-out. An effect-endpoint off representation is an option, not an approved replacement for white-master semantics.

### R9 — P3 / STATIC: Chase Fade UI accepts ineffective values

`F:44–55; M:120–123 fmtParam`.
Step=400 ms, Fade=4000 ms is accepted/displayed/saved; renderer clamps fade to Step/2=200 ms. All Fade values 200–4000 then have identical effect. Target: constrain dependent parameter or display effective limit. Time formatting also hides 50 ms steps by printing only tenths of a second.

## Documentation corrections / avoid false findings

- DEV_PLAN: obsolete Static×master/Fara-power model; preserve v2 above. README roadmap wrongly lists implemented PD gate/report-back as future. SESSION_HANDOFF “fully tested/complete” exceeds evidence; test journal mixes stale TODO/FAIL with newer OK results.
- Stale comments: INO GPIO order/PD not implemented; bleota.h and ../tools/ble_ota.py claim simultaneous Zigbee+BLE; config.h claims global static master and unimplemented effect persistence. Calibration is shared, despite README's “per-channel gamma”.
- Drive matches ../SmartLadaC6/docs/TZ_drive_mode.md tables. REVERSE only entered from STOP is true; STOP only after braking is false (initial STOP, HAZARD/REVERSE→STOP). No self-edges does not mean nonrepeating timeline; cycles exist. REVERSE→CRUISE without STOP and steady brake during reverse are documented artistic choices, not implementation regressions.
- 7/8 V gate does not verify exactly 12 V. Old hardware-spec USB-host inhibit/overvoltage requirements are absent; clarify their current status before expanding scope. No external lamp-temperature sensor is intentional; die-temperature diagnostics are not lamp protection.
- Static compositor: 16,384 channel assertions passed across 256 master values × 16 masks × 4 channels; no double master, off-mask respected. Turn channel isolation passed. Effects ignoring static mask is intentional. GPIO map matches PCB verification; dual OTA slots confirmed. Successful build is not proof of runtime/radio/electrical safety.

## Reuse validation

Build from the directory containing `SmartLadaRevC/`:
```sh
arduino-cli compile --fqbn esp32:esp32:esp32c6:ZigbeeMode=ed,PartitionScheme=zigbee_8MB,CDCOnBoot=cdc,FlashSize=16M --build-path /tmp/smartlada-revc-review-build SmartLadaRevC
```
Passed: app=1,111,526 bytes (32%); globals=40,416 bytes (12%, not peak runtime RAM).
Optional temporary evidence, may expire: `/tmp/smartlada-review/{input-manifest.txt,harness.cpp,stubs/,harness}`. Harness includes actual CFG/F/C/K/M with peripheral stubs. Cases: `timing-drive`, `timing-shrink` (expected sanitizer failures); `boot`, `gate`, `held-ota`, `persist` (counterexample outputs); `compositor` (pass). Do not require the long report or /tmp artifacts to understand findings. Rebuild host tests after source changes; compiled harness is a snapshot.

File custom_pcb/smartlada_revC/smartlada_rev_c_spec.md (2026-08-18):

# SmartLada Rev C — плата под установку в фонарь ВАЗ (питание USB-C PD)

Продуктовая ветка от [revB](../smartlada_revB/smartlada_rev_b_spec.md). Rev B — учебная 4-слойка с дисплеем
на плате, меню, RGB. **Rev C — плата под физическую установку в фонарь**: свой формфактор
под крепёжную пластину, автомобильные ножевые клеммы, LED-индикация, и **питание от USB-C
PD (12 В-триггер)** вместо барела. Дисплей с кнопками **вынесен за плату кабелем** —
настройка на месте без Wi-Fi/Zigbee (автономность). RGB убран.

Ядро — как revB: интегрированный **ESP32-C6-WROOM-1**, buck 12V->3.3V, 4x low-side MOSFET.

- **Нагрузка: 2×10 Вт + 2×5 Вт = 30 Вт** ламп (под бюджет PD).
- **Питание: USB-C PD, профиль 12 В/3 А (36 Вт).** Рекомендованный БП — **COMMO Core
  45–140 Вт** (у линейки есть 12 В/3 А), указывается в инструкции. Лампы 12 В питаются
  **напрямую** от 12 В PD, без понижайки.

**Статус: спека. Схема и плата не нарисованы.**

---

## 1. Что делает Rev C и чем отличается

| Блок | Rev B | Rev C | Почему |
|---|:-----:|:-----:|---|
| MCU | WROOM-1 на плате | **WROOM-1 на плате** | ядро переносим 1:1 |
| Дисплей + 4 кнопки | 8-pin гребёнка на плате | **угловой 2.54 pin header 1×8 (папа), модуль ВЫНЕСЕН за плату** | автономная настройка |
| RGB WS2812 | есть | **нет** | эффекты не нужны в продукте |
| Питание 3V3 | buck TPS54202 | **тот же buck** (от 12 В PD) | доказан на revB |
| **Вход питания** | клеммник/Type-B | **USB-C PD, 12 В-триггер (CH224K, ESSOP-10)** | 12 В напрямую в лампы, современный разъём |
| Переполюсовка | 1x AOD4185 | **нет** | USB-C конструктивно не путает VBUS/GND |
| Предохранитель | T4A | **нет** | PD-источник сам лимитирует ток и складывается при КЗ |
| TVS | — / SMBJ15A | **нет** | PD-источник регулируемый, без транзиентов; без fuse TVS вреден |
| Выключатель | — | **нет** | «выключить = выдернуть кабель» (решение Саши) |
| Выходы ламп | клеммник | **ножевые клеммы 6.3 мм tab «папа»**, common +12В | как на фонаре ВАЗ |
| Индикация | RGB | **6x красных LED 0805** (4 канала + 12В + 3.3В) | простая диагностика |
| Формфактор | 92x80 | **100x59 под крепёжную пластину** | посадка в фонарь |
| Слои | 4 | **2 (попытка), откат на 4** — §11.1 | RF+buck хотят землю |

**Сознательно НЕ добавляем:** барел, предохранитель, TVS, переполюсовку, выключатель,
понижайку для ламп (12 В PD напрямую), питание от data-USB, RGB, токовые шунты, NTC,
USB-UART мост, рельс 5 В/LDO, снабберы на стоки. **Вход максимально разгружен — вся защита
входа делегирована PD-источнику** (регулируемый, токоограниченный, правильная полярность).

---

## 2. Архитектура питания

```text
USB-C (питание+данные) --VBUS--+---[C_bulk 470-1000мкФ]---+-- 12V rail --+-- LAMP_COM (Faston, общий +12В)
      |                        |                          |              |
     CC1/CC2 -> CH224K (ESSOP-10, CFG-резисторы на 12В) -> PG -> GPIO ESP |    лампы через Q1..Q4 (low-side)
      |                        |                          +-- buck TPS54202 12->3.3 -> +3V3 -> WROOM, дисплей, LED
      |                        +--[R 100k]--+--[R 33k]-- GND
      |                                     +-- ADC GPIO ESP  (диагностика: реальный VBUS)
     D+/D- -> ESP32-C6 (GPIO13/12) + ESD-массив
```

- **PD-триггер CH224K (ESSOP-10)** сидит на CC-линиях, CFG-резисторами запрашивает
  **фиксированные 12 В**. При 12 В PDO -> VBUS=12 В; если 12 В нет (обычный PC-порт) -> держит
  **5 В**, buck тянет логику от 5 В (TPS54202 от 4.5 В), ESP+дисплей живы, лампы тёмные.
  Выбран **по доступности** (CH221K нет на Platan/ChipDip; CH224K — ходовой). QC/AFC/PPS его
  возможности не используем. Пайка ESSOP-10: **тепловой пад через 2 via, залить припоем с
  обратной стороны** (пад = GND/тепловой, ток не несёт). Требует зазор платы над пластиной
  (см. §8).
- **PG (power-good) CH224K -> GPIO ESP** — штатный сигнал «12 В есть», гейт каналов (§2.3).
  **PG open-drain, active LOW** -> подтяжка 10k на +3V3; firmware: **PG=НИЗКИЙ = 12В ок**.
- **DP/DM CH224K -> NC (не подключать к D+/D-).** Даташит: для чистого PD (наш случай) DP/DM
  отключить от Type-C, иначе CH224K мешает USB-данным ESP (QC-детект). VDD(1): R 1k от VBUS +
  1uF; VBUS(8): последовательный R к шине (по даташиту, раздел 6.1).
- **VBUS-делитель 100k/33k -> ADC-пин ESP** — диагностика: firmware видит реальное напряжение
  rail (12/5 В, просадка). Ценно для теста инраша §2.2 (видно, складывается ли PD) и как
  второй контроль OVP (§11.2). Можно урезать при желании — тогда гейт по одному PG.
- **Отдельный load-switch НЕ ставим** — explicit load enable уже есть: 4 low-side MOSFET +
  firmware-дефолт OFF (см. §2.3).
- **12 В идут в лампы напрямую** — понижайка не нужна (суть гарантированного 12 В PDO).
- **Bulk-конденсатор на 12 В rail** — сглаживает пусковой ток ламп (см. §2.2).

### 2.3 Детект «зарядка vs компьютер» (защита от 30 Вт из ноутбука)
CH224K фиксированный — запросит 12 В у любого источника, который их отдаёт (в т.ч. у
ноутбука, если тот рекламирует 12 В PDO). Настоящая забота — **чтобы 30 Вт ламп не жрались
из компьютера**. Решается в firmware по фундаментальному признаку: **зарядка = питание без
data-хоста; компьютер = USB-хост (энумерация).** D+/D- заведены на ESP, значит хост виден.

> **Каналы ламп включаются ТОЛЬКО при: PG активен (12 В есть) И USB-хост НЕ обнаружен.
> Дефолт при старте — каналы OFF; включаются лишь после «зарядка подтверждена».**
> (VBUS-ADC — второй, диагностический контроль: подтверждает ~12 В и ловит >12 В.)

- Зарядка: 12 В есть, хоста нет -> лампы работают.
- Ноутбук (даже если отдаёт 12 В): 12 В есть, но энумерация хоста -> **лампы OFF**, крутится
  только логика ~0.5 Вт (30 Вт из ноутбука не уходит) -> это и есть debug-режим.
- Ноутбук на 5 В: 12 В нет и хост есть -> лампы OFF.

(Вариант с I2C PD-sink AP33772, чтобы плата даже не ЗАПРАШИВАЛА 12 В у компьютера, —
рассмотрен и отклонён в пользу простоты CH224K + firmware-гейтинг.)

### 2.1 PD-источник и бюджет
- Рекомендуемый: **COMMO Core 45–140 Вт**, профиль **12 В/3 А = 36 Вт** ≥ 30 Вт нагрузки. ✓
- **ВАЖНО в инструкцию:** у 45-Вт модели при занятых ДВУХ портах наш порт падает до
  **12 В/1.67 А = 20 Вт < 30 Вт**. Правило для пользователя: **подключать в один порт, второй
  не занимать** (или брать модель ≥65 Вт). На плату не влияет.
- PPS не используем (нужен фиксированный 12 В).

### 2.2 Пусковой ток ламп vs лимит PD (валидируем эмпирически)
Холодная нить лампы -> кратковременный пусковой ток (10-Вт ~7 А, 5-Вт ~4 А), суммарно
десятки ампер на 30-100 мс. PD жёстко лимитирует ~3 А и может сложиться (foldback).
- **30 кГц PWM НЕ даёт пофазного инраша** (нить не остывает за цикл 33 мкс). Инраш — только
  на макро-фронтах вкл/выкл (эффекты, старт). При мигании тёплой нити инраш низкий.
- **План (согласовано):** плата несёт **bulk-кон** (демпфирует инраш из ёмкости, а не из PD)
  и firmware-хуки PWM-soft-start; но **сначала собираем и тестируем БЕЗ soft-start** —
  держит ли COMMO пусковой ток. Стаггер/софт-рамп в прошивке добавляем **только если PD
  реально складывается.** Так эффекты с миганием не зажимаем заранее.

---

## 3. Выходы ламп — ножевые клеммы Faston 6.3 мм
- **На плате — tab «папа» 6.3 мм (тип 250)**, PCB-mount, впаиваемые, держат 10-20 А.
- Состав: **4x CH (стоки Q1..Q4)** + **1x LAMP_COM (общий +12В на ВСЕ лампы)** — на фонаре
  общий контакт на все лампы. Common несёт ~2.5 А (6.3 мм с запасом).
- **На проводе — female «мама» 6.3 мм под обжим** (заказать на провода к лампам).

---

## 4. Дисплей + кнопки — угловой 2.54 pin header 1×8
Модуль SSD1315 + 4 кнопки **вынесен за плату** (на обратную сторону крепёжной площадки),
кабелем. На плате — **угловой 2.54 pin header 1×8 «папа»**; кабель — **BLS-8 мама-мама**
(Platan PN 10660, гнездо 1x8 2.54 с контактами 130A-S08). Дёшево, удобно для отладки.
**Интерфейс = revB 1:1** ([revB pinout](../smartlada_revB/smartlada_rev_b_pinout.md)): I2C SDA/SCL + 4 кнопки
+ 3V3 + GND = 8. I2C **возвращается** (нужен OLED) — свои подтяжки SDA/SCL.

---

## 5. LED-индикация (6x красных 0805)

Vf ~1.8-2.0 В, ток 1-2 мА.

| LED | Подключение | R 0805 | Поведение |
|-----|---|:---:|---|
| CH1..CH4 | анод +12V, через R на сток Q1..Q4 | **4.7k** | горит при открытом канале; **следует за PWM** |
| +12V rail | 12V rail -> R -> LED -> GND | **4.7k** | «12 В PD есть» (на 5 В-порту тускло) |
| +3.3V rail | +3V3 -> R -> LED -> GND | **1k** | «3.3 В есть» |

Итого: **5x 4.7k + 1x 1k**.

---

## 6. USB-C

**Порт питания J1 (power+data, рекомендую один порт на всё):** VBUS -> CH224K (12 В) ->
12 В rail; **D+/D- -> ESP32-C6 (GPIO13/12) + ESD-массив** (напр. USBLC6-2SC6). Тогда:
- Зарядка COMMO -> 12 В -> лампы+логика работают.
- **PC -> 5 В (нет 12 В PDO) -> CH224K держит 5 В -> buck питает логику -> ESP шьётся по тем
  же D+/D-.** Прошивка **одним кабелем от PC, без внешнего 12 В.** Лампы тёмные (PG=0).

Full-Speed 12 Мбит, «low speed data» трактуем как «пара D+/D- USB 2.0, без SS-пар».
CC — на CH224K (он же терминирует sink). **Порт один** (power+data).

### 6.1 UART debug header (3 пина: TX / RX / GND)
Раз порт один — консоль во время реальной 12 В-работы даёт **UART-хедер + дешёвый USB-UART
донгл** (CH340 и т.п.): serial-логи, пока плата пашет на 12 В от зарядки. Прошивка через
него тоже возможна (manual BOOT/RESET — кнопки есть). Пятаки копеечные, дешевле второго
USB-C. Плюс каналы отладки установленного в фонарь устройства: **WiFi-логи** (C6, переиспользуем
cineink log/web view) и **статус на OLED**.

---

## 7. Сервис: кнопки, тест-точки, шелкография
- **BOOT + RESET** на плате (нативный USB, обвес WROOM-1 как revB).
- **UART debug header 3-pin** (TX/RX/GND) — §6.1.
- **Тест-точки**: GND, +12V, +3V3.
- **Шелкография**: подписи CH1..CH4 и их мощность (10/5 Вт), полярность LED, назначение
  USB-портов.

---

## 8. Механика и формфактор
Плата садится на **крепёжную пластину** (`mechanical/smartlada_revC_drawings.pdf`
+ STEP), крепится на закрутку рассеивателя. Дисплей — на обратной стороне площадки, кабелем.
- **Габарит: 100 x 59 мм** (X x Y).
- **4x отверстия, прямоугольник 88 (X) x 47 (Y)**, центр, отступ **6 мм** до края.
- **В плате Ø3.2 мм (клиренс M3).** В пластине пилот Ø2.4 x 4 мм под M3-саморез 4 мм.
- **Keepout под бобышку НЕ нужен** (fillet 2 мм не налезает на периметр).
- **ЗАЗОР платы над пластиной: 2 мм (РЕШЕНО).** На обратной стороне — THT-выводы (pin-header,
  USB-C, Faston) и залитые припоем via пада CH224K; впритык плата лежать не может. Заложенные
  2 мм достаточны (THT-пропай после обрезки <1.5 мм, via-fill меньше). Фолбэк, если не хватит:
  бобышки повыше или проставочные шайбы.
- Предусмотреть край/окно под вывод кабеля дисплея на сторону пластины.
- **RF keepout под антенной WROOM-1** — по datasheet модуля (антенна к краю платы, без меди).

---

## 9. Пинаут / GPIO
Модуль тот же -> **пинаут revB** ([smartlada_rev_b_pinout.md](../smartlada_revB/smartlada_rev_b_pinout.md)):
каналы LAMP0..3, USB D+/D- на GPIO13/12, I2C дисплея, 4 кнопки, BOOT/RESET. **Добавить:
CH224K PG -> GPIO** + **VBUS-делитель -> ADC-GPIO** (реюз освобождённого от RGB GPIO, если
ADC-capable; иначе любой ADC1-пин C6) + **UART0 TX/RX на debug-хедер**. Гейт каналов в
firmware — по «PG И нет USB-хоста» (§2.3), дефолт OFF. Профиль каналов в firmware:
**CH0/CH1 = 10 Вт, CH2/CH3 = 5 Вт** (уточнить назначение). RGB убран, GPIO свободен.
Маппинг каналов может поехать при разводке — фиксируем по факту, правим firmware (как revB).

---

## 10. Дельта BOM относительно revB

> Полный BOM с проверкой по Платану — [smartlada_rev_c_bom.md](smartlada_rev_c_bom.md).

**Правило BOM/футпринтов (весь проект):** минимальный SMD-пассив — **0805**, футпринты
**hand-soldering** (KiCad `*_HandSolder`). ИС/разъёмы — паяемые вручную корпуса (SOIC/SOT/
SOP/DPAK, не QFN/DFN/BGA). Точки внимания revC:
- **CH224K** — **ESSOP-10 с тепловым падом**. Выбран по доступности (CH221K/SOT-23-6 нет на
  Platan/ChipDip). Пайка: перим. 0.5мм — паяльник+флюс+drag или фен; **пад — через 2 via,
  залить припоем с обратной стороны** (пад = GND/тепловой). Требует зазор платы над пластиной
  (§8). Взять hand-solder футпринт ESSOP-10 с удлинёнными падами.
- **USB-C разъём** — брать hand-assembly/THT-исполнение (мелкий SMD-шаг паять неудобно).
- Пассивы (все R/C/LED) — только 0805 `*_HandSolder`.

**Добавить:**
- **J1** USB-C разъём (power+data) + **CH224K** PD-триггер (ESSOP-10) + CFG-резисторы на 12 В + PG->GPIO
- **VBUS-делитель** 100k/33k (0805) -> ADC-GPIO ESP (диагностика rail, §2)
- **C_bulk** 470-1000 мкФ на 12 В rail (демпфер инраша)
- **ESD-массив** на D+/D- (USBLC6-2SC6)
- **5x Faston 6.3 мм tab «папа»** (4 CH + 1 COM) + (заказ) female «мама» под обжим
- **6x LED** красный 0805 + **5x 4.7k + 1x 1k**
- **J_disp** угловой 2.54 pin header 1×8 «папа» (кабель BLS-8, Platan 10660)
- **J_uart** 3-pin хедер (TX/RX/GND) для USB-UART донгла

**Из revB переносим 1:1:** WROOM-1 + обвес (EN/RC, страпы, антенна keepout), buck TPS54202,
4x AOD4184A + gate-сети, USB D+/D-, BOOT/RESET, I2C-подтяжки, OLED-модуль + 4 кнопки (на кабеле).

**Убираем относительно revB:** WS2812 RGB, сервисную гребёнку датчиков. **Относительно
прошлых итераций revC убраны:** барел, F1, TVS, Q5 (reverse), Q6 (switch), SW1 — вся тяжёлая
входная цепь заменена на USB-C + CH224K + PG + VBUS-делитель.

---

## 11. Открытые решения

### 11.1 Слои: 2 или 4
Дисплей вынесен -> плотности не добавляет. Драйверы слоёв — **RF (2.4 ГГц) + buck**.
**Рекомендация: 4 слоя** ради RF/EMI со сплошной землёй; попытку 2-слойки поддерживаю
(откат дёшев, топология та же). Критерии провала 2-слойки: не удержать GND-полигон;
не закрыть трассировку; длинная петля buck.

### 11.2 OVP-бэкстоп
Решено **довериться детерминизму CH224K** (без OVP). Остаточный риск: триггер отдаст >12 В
-> лампы сгорят. Вероятность низкая; при желании позже добавить OVP-кламп. Плюс VBUS-ADC
(§2) даёт firmware второй контроль: при VBUS заметно >12 В держать каналы OFF.

### 11.3 USB: один порт (РЕШЕНО)
**Один порт J1 (power+data)** + UART debug header (§6.1). Отдельный порт прошивки не делаем.

### 11.4 Инраш
Валидировать эмпирически без soft-start (§2.2). Если COMMO складывается — добавить
стаггер/софт-рамп в firmware.

### 11.5 CH224K — сверить даташит (перед BOM)
**Наличие подтверждено:** Platan PN **2016569523**, WCH CH224K, ESSOP-10, ~36.49 ₽, склад 0
но привоз 3-4 раб.дня, MOQ 10. Даташит (общий CH224D/K/221K):
`https://www.platan.ru/pdf/datasheets/wch/CH224D-K-221K.pdf`.
Сверить по нему перед BOM: (1) страп CFG под 12 В (комбинация/номиналы); (2) подключение PG
(open-drain? подтяжка); (3) обвязка CC/VBUS/VDD, кон. по питанию; (4) hand-solder футпринт
ESSOP-10. После — финализировать номиналы входа.

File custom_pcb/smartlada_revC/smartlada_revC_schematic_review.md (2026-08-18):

# SmartLada Rev C — проверка схемы и финальный список правок

Проверено: 2026-08-13 (перепроверка по актуальному нетлисту `smartlada_revC.kicad_sch`).
Метод: экспорт нетлиста/футпринтов kicad-cli + сверка с даташитом CH224K и спекой/BOM.

**Статус: ERC 0/0. До PCB закрыть P0 (3 правки: DP/DM, USBLC6, C_bulk + косметика). P1 — до финализации.**

---

## ✅ Уже корректно (проверено по нетлисту)

- **PG и VBUS-измерение РАЗДЕЛЕНЫ** (это был спорный пункт прежнего ревью — уже сделано):
  - `PG_SENS`: U3.10 (PG) → ESP **IO5**, подтяжка **R22 10k → +3V3**.
  - VBUS-делитель: `+12V → R16 100k → IO4 → R17 33k → GND` (ADC1_CH4). Отдельная сеть.
- **GND ESP — все 11 пинов** (1, 28, 29_1..29_9) на GND. ✓
- **Buck FB** R2 100k / R3 22k → 3.30 В. ✓
- **CFG1 = 24k → GND** (=12 В), **CFG2/CFG3 = NC** — по даташиту CH224K. ✓
- **VDD/VBUS CH224K** — по эталону (раздел 6.1): VDD(1) через R19 1k + C11 1uF; VBUS(8) через
  R21 10k (даташит требует последовательный резистор к обоим). ✓
- **USB D+/D-**: IO13=D+, IO12=D-, A/B-стороны разъёма сшиты (реверсивность). ✓
- **Каналы**: CH0..3_IN → Rg 100R → Q1..4 (AOD4184A) → LAMP0..3; Rpd 100k на PGND. ✓
- **LED**: 6 шт (D2-D7) — 4 канала + 12В (D7) + 3.3В (D6); 5×4k7 + 1×1k. ✓
- **Все футпринты R/C/LED — 0805/1210 hand-solder** (в т.ч. **C5 уже 0805** — исправлено). ✓
- **Faston** J2/J3/J5/J6/J7 (LAMP0-3 + 12V), **CFG/CC/GND** — ок.
- **J1 SBU1/SBU2 = NC** (флаги стоят, ERC чист). ✓
- **U1 полностью N16**: value, MP (партномер), footprint `XCVR_...N16`, 3D `...N16.step` —
  все N8-ссылки убраны. ✓

---

## P0 — исправить до PCB

### 1. DP/DM CH224K: отвязать от D+/D- и закоротить между собой  ⟵ по даташиту
- [ ] Убрать провод от **U3.DP(4)** и **U3.DM(5)** к `USB_D+`/`USB_D-`.
- [ ] **Закоротить U3.4 ↔ U3.5 между собой** (изолированная терминация DP/DM).
- [ ] **VBUS(8) НЕ трогать** — остаётся через R21. («VBUS можно NC» — это раздел 6.3 male/E-Mark,
  а у нас 6.1 female-порт + резисторная конфигурация.)
- [ ] После этого `USB_D+/-` = только разъём J1 ↔ USBLC6 ↔ ESP.

Почему: даташит — при отказе от QC-протоколов (наш чистый PD) DP/DM CH224K отвязывают от
Type-C; для PD-only даташит показывает DP↔DM **закороченными на стороне чипа**. Иначе CH224K
дёргает пару под детект и мешает USB-данным ESP. Не 0Ω-джамперы — просто отвязать + шорт.

### 2. Добавить ESD USBLC6 (U4)
- [ ] Поставить **U4 USBLC6-2SC6** (SOT-23-6) у J1, на линии `USB_D+/-`.
- [ ] **⚠️ VBUS/опорный пин U4 — на `+3V3`, НЕ на шину 12В.** USBLC6 — 5-вольтовая деталь;
  её клампинг-пин при 12 В сгорит. Через неё идут только D+/D- (домен 3.3 В).
- [ ] GND U4 — на сплошную землю кратчайшим путём.
- [ ] На PCB: U4 ближе к разъёму, чем ESP/CH224K.

Почему: заявлен в спеке/BOM, на схеме отсутствует.

### 3. Добавить bulk-конденсатор шины +12 В
- [ ] `C_bulk` **470 µF / 25 В** SMD электролит (BOM: EEEFK1E471P, Platan 696157719) между
  `+12V` и GND.
- [ ] На PCB — у входа/ветвления к лампам, короткий токовый контур.

Почему: часть плана проверки пускового тока ламп (§2.2). C3/C4 10µF его не заменяют.

### 4. (косметика) Переименовать сеть PG
- [ ] `PG_SENS` → `CH224_PG` — чтобы имя не намекало на аналоговое напряжение.

(SBU1/2 NC и U1→N16 — **уже сделано**, см. «уже корректно».)

---

## P1 — добавить до финализации схемы

### 6. UART debug header
- [ ] `J_UART` 1×3, 2.54: **GND / TXD0 (GPIO16) / RXD0 (GPIO17)**.
- [ ] Шелкография порядка: `GND | TX(board) | RX(board)`.
- [ ] Убедиться, что `UART_TX/RX` не остались только метками без разъёма.

### 7. Тест-точки
- [ ] `TP_GND`, `TP_12V`, `TP_3V3` (требует спека).
- [ ] Рекомендуется `TP_PG`, `TP_VBUS_SENSE` — почти бесплатно, сильно упрощают отладку PD/прошивки.

---

## После сборки (валидация на железе, до тиража)

- [ ] **PD-сценарий:** COMMO 12В/3А → CH224K запрашивает 12 В (PG=LOW, VBUS-ADC≈12В), ESP
  стартует, каналы включаются, USB-линии не мешают PD.
- [ ] **PC-сценарий:** плата держится на 5 В, ESP стабильно перечисляется и шьётся по
  USB Serial/JTAG, лампы OFF (детект хоста).
- [ ] Проверить **оба положения** штекера USB-C.
- [ ] Пусковой ток ламп: держит ли PD (§2.2), нужен ли firmware soft-start/стаггер.

---

## Firmware-заметки (следствия схемы)

- **PG active-LOW**: «12 В согласовано» = `CH224_PG == 0`. Напряжение — отдельно по ADC (IO4).
- **Гейт каналов**: включать только при `PG==0` **И** нет USB-хоста (§2.3); дефолт OFF.
- **Маппинг каналов** (revB-remap): IO0=CH1, IO1=CH0, IO2=CH3, IO3=CH2.
- **VBUS-ADC** (IO4): делитель 100k/33k → при 12 В ≈ 2.98 В; использовать для контроля rail и
  теста инраша.

---

## Финальный чек-лист перед PCB

- [ ] P0 (1-5) закрыты, повторный **ERC 0/0**.
- [ ] Футпринты всех R/C/LED — 0805+ hand-solder (проверено: да; следить при добавлении U4/C_bulk/J_UART).
- [ ] C3/C4 — рабочее напряжение **≥25 В** (подтвердить у выбранного 10µF 1210).
- [ ] U3: CFG1=24k→GND, CFG2/3=NC; DP/DM отвязаны от D+/D- и закорочены DP↔DM; VBUS через R21; PG-подтяжка к 3V3 отдельно от ADC.
- [ ] U4 ESD у J1, VBUS-пин на +3V3; D+/D- как пара с непрерывной землёй под ними.
- [ ] RF keepout под антенной WROOM — по даташиту модуля.
- [ ] C_bulk и силовые дорожки под ток ламп (2.5 А): широкие +12V и GND-return.
- [ ] Faston: посадка **TE_1217754-1** совпадает с заказываемым **63951-1** (Ø/шаг выводов),
  не только лезвие.
- [ ] Номера пинов разъёмов = шелкография = реальный кабель дисплея (BLS-8).
- [ ] Габарит 100×59, отверстия Ø3.2 @ 88×47, зазор 2 мм над пластиной (back-side пропай).

---

## Ссылки
- [Спека Rev C](smartlada_rev_c_spec.md) · [BOM](smartlada_rev_c_bom.md) · [Схема](smartlada_revC.kicad_sch)
- CH224K datasheet (WCH, авторитетно): `https://www.platan.ru/pdf/datasheets/wch/CH224D-K-221K.pdf`
- [TPS54202 datasheet](https://www.ti.com/lit/ds/symlink/tps54202.pdf)
- [Espressif ESP32-C6 schematic checklist](https://docs.espressif.com/projects/esp-hardware-design-guidelines/en/latest/esp32c6/schematic-checklist.html)

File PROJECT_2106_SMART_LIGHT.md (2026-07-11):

# Умный светильник из заднего фонаря ВАЗ-2106 — контекст проекта

> Handoff-документ для будущих сессий. Фиксирует принятые решения, железо, архитектуру,
> открытые вопросы и план прототипирования. Тон обсуждения — red-team / peer-review:
> факты, выводы и гипотезы разделяются.

> **ОБНОВЛЕНИЕ 2026-07-06:** калибровочный стенд SmartLada (ESP8266, см.
> `TASK_smartlada_bench_esp8266.md`) выполнен, **прототип электрики рабочий**:
> 4 канала D4184 low-side PWM независимо диммируют реальные лампы накаливания
> фонаря. Схема подключения исправна и проверена — см. раздел 5.5. Калибровка
> снята: https://github.com/saschapo/smartlada → `calibration/2026-07-06_bench.json`.

## 1. Цель

Переделать штатный задний фонарь ВАЗ-2106 в **домашний умный светильник**:
управление голосом через **Яндекс Алису (Станция Миди)**, регулировка яркости
секций. В кадре светильник не снимается (камера-фликер не важен, но мерцание для
глаза нежелательно).

Мейкер-контекст: есть опыт embedded (ESP32, Arduino IDE), паяльные/CAD-навыки,
3D-принтер.

## 2. Исходный фонарь

- Деталь: **фонарь в сборе 2106-3716011** (левый) / корпус **2106-3716041**.
  Применяется также на ВАЗ-2121 (Нива).
- Корпус пластиковый, разделён на **5 секций**; рассеиватель цветной, тоже 5 частей:
  1. указатель поворота — жёлтый/оранжевый (крайняя наружная секция)
  2. габарит — красный
  3. фонарь заднего хода — прозрачный/белый
  4. стоп-сигнал — красный (крайняя внутренняя секция)
  5. подсветка номера — в чёрном внутреннем выступе
  - средняя верхняя секция лампы не имеет (заглушка).
- **Используем только 4 секции**: поворот, габарит, задний ход, стоп. Подсветку
  номера НЕ задействуем (детали нет).
- Штатно **задняя часть открыта** (фонарь вставлялся в кузов, лампы менялись из
  багажника через плату патронов). => нужна изготавливаемая задняя панель-крышка.
- **Патроны выламываются**, диоды закладываются напрямую в секции (даёт свободу по
  напряжению и оптике).
- Поправка к ранней гипотезе: в 2106 габарит и стоп — РАЗНЫЕ секции с отдельными
  однонитевыми лампами, а не двухнитевая P21/5W. Двухнитевой лампы здесь нет.

## 3. Итоговые архитектурные решения

| Узел | Решение | Статус |
|---|---|---|
| Радио/интеграция | **Zigbee**, прямая привязка к Станции Миди | зафиксировано |
| МК | **ESP32-C6** (есть в наличии) | зафиксировано |
| Модель устройства | несколько **dimmable-light** эндпоинтов (по 1 на секцию) | зафиксировано |
| Каналы | **4** (поворот, габарит, задний ход, стоп) | зафиксировано |
| Ключи | **4× плата на D4184** (1 канал каждая = 4) | зафиксировано |
| PWM | аппаратный **LEDC** ESP32-C6, ~1–2 кГц, гамма-коррекция | зафиксировано |
| Напряжение диодов | **12 В** | зафиксировано |
| Источник питания | 12 В (простой адаптер ИЛИ USB-C PD 20V→buck→12V) + 12→5 В buck на C6 | выбрать |
| Свет | high-CRI белый под задний ход; цветные диоды под остальные | к закупке |
| Корпус | печатная **PETG** задняя панель-носитель | к проектированию |

## 4. Радио: почему Zigbee → Миди

**[Факт]** ESP32-C6 имеет радио 802.15.4 → умеет Zigbee. Классический ESP32 и
ESP8266 — НЕ умеют (нет 802.15.4).

**[Факт]** Станция Миди — Zigbee-координатор. DIY-устройства на C6 реально к ней
встают; тип «лампа» (light, On/Off + Level Control) — самый поддерживаемый.
Приём: поднять несколько light-эндпоинтов на одном C6 — станция увидит несколько
«лампочек», каждая управляется отдельно голосом.

**[Ограничения]** У ламп в УДЯ нет RGB/сцен (нам не нужно — цвет даёт физический
рассеиватель). Кастомные сенсорные кластеры при прямой привязке к станции часто
висят «Ожидание данных» — нас не касается (у нас light).

**[Главный риск]** Примет ли Миди самодельный Zigbee-light — проверить ПЕРВЫМ, на
макетке, до любой механики.

**[Отвергнуто]**
- Wi-Fi + Home Assistant + навык Алисы — требует сервер 24/7 (нет HA).
- Matter over Wi-Fi — рабочая альтернатива (Миди поддерживает как коммиссионер),
  но требует живой Wi-Fi-роутер + риск с device attestation (тестовый DAC),
  и esp-matter тяжелее. Zigbee-to-Midi проще (работает даже без роутера).
- Собственное облако / эмуляция Tuya — лишняя инфраструктура.

## 5. Электрика

### 5.1 Один канал (low-side, через плату D4184)
```
ESP32-C6 GPIO (PWM) ──► PWM-вход платы D4184
ESP32-C6 GND       ──► GND платы   (ОБЩАЯ земля обязательна)
+12 В              ──► Power+ платы
Нагрузка (LED-секция) ──► клеммы OUT платы (in/out нагрузки)
```
- Флайбек-диод не нужен (нагрузка не индуктивная).
- D4184 = logic-level MOSFET, открывается от 3.3 В GPIO. Для токов LED (<~1 А/канал)
  с запасом.

### 5.2 Плата D4184 — конфигурация и проверки
- **1 канал на плату, 4 платы** (по одной на секцию). Каждая — свой PWM-вход с своего GPIO C6.
- Частоту вести **~1–2 кГц**, НЕ 30 кГц (30 кГц — потолок платы; на большом заряде
  затвора и 3.3 В-раскачке выше частота = лишние потери на переключение).
- **Boot-safe GPIO** на C6 (не strapping-пины), иначе секция моргнёт при загрузке.

### 5.3 Диоды (12 В)
- Строки по **3 диода последовательно** (~10 В) + ограничение тока — ложатся на 12 В.
- **Тип света:**
  - задний ход (прозрачная секция) — **high-CRI белый 2700–3000K**; единственный
    «полезный» белый свет. CRI важен только здесь.
  - стоп/габарит (красный), поворот (жёлтый) — **цветные диоды под цвет секции**.
    За цветным фильтром CRI не считается, а белый high-CRI за фильтром теряет ~½ потока.
- **Ток:** для старта брать модули со встроенным ограничением тока (PWM-ить прямо
  MOSFET-ом). Для сырых мощных LED без ограничения — нужен CC-драйвер на канал
  (PWM подавать на его enable/PWM-вход), резистор на 1–2 А неэффективен и греется.
- Тепло: даже LED в закрытом пластиковом корпусе греются — заложить минимальный
  теплоотвод (алюминиевая подложка), особенно под задний ход на полной яркости.

### 5.4 Питание
- **12 В в USB-PD — опциональный и негарантированный** профиль (стандартные: 5/9/15/20 В).
- **Текущая (временная) схема:** barrel 12 В → линия LED; USB-C → отдельно ESP32-C6.
  - **КРИТИЧНО: земли обоих источников свести в общую точку** (GND barrel = GND USB/C6 =
    GND плат D4184). Без общей земли PWM с C6 не имеет опоры относительно силовой стороны →
    ключи не откроются / поведение непредсказуемо.
- Варианты для финальной (единой) схемы, по простоте:
  1. Простой 12 В адаптер (barrel) на всё + **12→5 В buck** на C6.
  2. USB-C: PD-триггер **20 В → buck → 12 В** (надёжно). Либо 12 В-триггер +
     зарядка с подтверждённым 12 В PDO (хрупко).
- Предохранитель на линии 12 В.

### 5.5 Проверено стендом SmartLada (2026-07-06) — схема исправна

**[Факт, критично для low-side]** Плата патронов фонаря 2106 конструктивно
объединяет «минусы» всех ламп (в машине — общий кузов, коммутируется плюс).
Low-side коммутация с таким общим минусом не работает: любой открытый ключ
замыкает петлю всех ламп сразу (наблюдалось на стенде — все лампы диммировались
вместе).

**[Решение — переполюсовка, проверено]** Лампе накаливания полярность безразлична:
- общая плата фонаря → общий **+12 В** (через предохранитель); плата постоянно
  «горячая» — не допускать её контакта с GND;
- индивидуальный контакт каждого патрона → **OUT− (сток)** своего D4184 —
  раздельные коммутируемые выводы;
- общая земля нужна только сигнальная: GND ESP = GND БП = VIN− плат D4184.

Правило: общей может быть только та сторона, которую не коммутируем.

**[Факты со стенда]**
- Мерцание PWM 100–1000 Гц глазом неразличимо (тепловая инерция нитей). Выбрано 100 Гц.
- Джиттер softPWM ESP8266 при активном AP+HTTP не наблюдался.
- Импульсный БП 100 Вт (от LED-ленты) «поёт» на частоте PWM — норма
  (магнитострикция при импульсной нагрузке).
- Пусковой бросок: БП и предохранитель переваривают старт без длинного soft-start
  (проверено с ramp 30 мс и без капа). Уточнение к разделу 8: бросок опасен не
  лампе и не ключу, а источнику (срабатывание защиты) и предохранителю; при
  батарейно-подобном источнике soft-start не обязателен.
- Калибровка: gamma 2.0 (21 Вт) / 2.2 (5 Вт), min_duty 50 (21 Вт) / 100 (5 Вт),
  soft_start 30 мс — перенос в слой `channels` на C6 без изменений.

## 6. Прошивка (план)

- Framework: Arduino-ESP32 (есть примеры `ZigbeeDimmableLight`) ИЛИ ESP-IDF + esp-zigbee-sdk.
  Zigbee end-device mode.
- N эндпоинтов dimmable-light (по 1 на секцию), каждый привязан к своему LEDC-каналу.
- Яркость Алисы 0–100% → PWM duty с **гамма-коррекцией (~2.2)** (иначе 50% выглядит
  почти как максимум).
- PWM: LEDC, ~1–2 кГц.

## 7. Отвергнутые варианты (чтобы не возвращаться)

- **PCA9685 (I2C серво/PWM-плата):** для 4 каналов избыточна; это генератор сигнала,
  не силовой ключ; потолок частоты ~1.5 кГц; LEDC C6 делает то же напрямую.
- **Оптопарный 4-канальный MOSFET-модуль:** изоляция не нужна (низковольтная система,
  общая земля), опто-модули часто режут частоту. D4184-плата проще.
- **Дешёвые IRF520-модули:** IRF520 НЕ logic-level, от 3.3 В не открывается полностью,
  греется. Не брать.
- **Питание 6 В:** не стандартный фиксированный PD-профиль (только через PPS) → сужает
  совместимость. (9 В рассматривалось для снижения тока, но выбрано 12 В.)
- **ESP8266 HW-365A:** только Wi-Fi, нет Zigbee. Для этого проекта не подходит.
- **Аккумулятор в корпусе:** конфликт «автономность ↔ мгновенный отклик» + просадка
  напряжения + BMS/заряд/пожаробезопасность. Для дома — питание от сети.
- **Лампы накаливания:** перегрев пластикового корпуса (пожароопасно), большой БП,
  мощные ключи. Выбран LED.
- **Автомобильные LED-ретрофиты (в цоколях):** низкий CRI + внутренний драйвер мешает
  внешнему PWM. Берём сырые high-CRI модули.

## 8. Опция (маловероятная): аутентичность на накаливании

Рассматривалась как эффектный, но маловероятный вариант. Ключи D4184 нагрузку тянут
(68 Вт: 3×21 + 1×5 Вт; ~1.75 А на нить — с запасом), накаливание отлично диммируется
PWM. Но против:
- **[Стоп-фактор] Тепло в пластиковом корпусе.** Колба 21 Вт = 100–250 °C; PETG Tg ~80 °C.
  3–4 лампы в закрытом печатном боксе → деформация рассеивателя + пожароопасность.
- **Пусковой ток:** холодная нить ~1/10–1/15 сопротивления → бросок в десятки ампер на мс.
  БП брать не 68, а **120–150 Вт (10 А)** с запасом на бросок. На низком duty нить может
  не прогреваться и молотить бросковым током.
- **Крупный горячий внешний БП** — рушит компактность и USB-C.
- **Аутентичность видна в основном на прозрачной секции (задний ход);** за красными/жёлтым
  фильтрами накал vs LED почти не читается.

Если возвращаться к идее — предпочтительны компромиссы, а не полный накал:
1. **Гибрид:** накаливание только в секции заднего хода (1 лампа, скромный БП, локальное
   тепло с вентиляцией/подложкой), остальные 3 секции — LED.
2. **Эмуляция накала на LED:** тёплый 2200–2700K high-CRI + программная кривая плавного
   розжига/гашения (медленный ramp duty) — читается как разгорающаяся нить, без рисков.

## 9. Корпус (3D-печать)

- Задача — закрыть открытую заднюю полость по периметру (не повторять внешний обвод).
- Материал: **PETG** (тепло + прочность).
- Задняя панель = плата-носитель: стойки под ESP32-C6, buck, платы D4184; ввод кабеля
  питания; периметральная губа + уплотнитель к кромке корпуса.
- Обмер неровной кромки — заложить допуск/уплотнитель, не press-fit по месту.
- **Антенна:** корпус пластиковый (RF проходит) — хорошо. Металл/фольгу теплоотвода
  разносить с антенной C6, иначе падает дальность. Для компактной версии рассмотреть
  Seeed XIAO ESP32-C6 (внешняя антенна u.FL).

## 9. Риски и открытые вопросы

- [РИСК] Примет ли Станция Миди самодельный Zigbee dimmable-light. → проверить макеткой ПЕРВЫМ.
- [ ] У платы D4184 — раздельный PWM на каждый канал? (подтвердить по фото)
- [ ] Источник 12 В: простой адаптер или USB-C (20V PD + buck)?
- [ ] Мощность/тип белого под задний ход → хватит ли токоограниченного модуля или нужен CC-драйвер.
- [ ] Финальный чип: остаёмся на C6-DevKit или компактный XIAO C6 в корпусе.
- [ ] Выбор конкретных LED-модулей (12 В, high-CRI белый + цветные).

## 10. План bring-up (прототип)

1. **ESP32-C6 + одна плата D4184 + один LED-модуль + 12 В (лаб. БП удобнее PD на старте).**
2. Поднять Zigbee dimmable-light, перевести в режим сопряжения.
3. Привязать к Станции Миди («Алиса, найди устройство»).
4. Проверить: включение/выключение и **яркость реально управляются из Алисы**.
5. Только после этого — масштабировать на 4 канала, LED-секции, питание, корпус.

## 11. Список покупок (стартовый)

- ESP32-C6-DevKitC-1 (8 МБ flash) — для отладки *(в наличии C6)*
- 2× плата MOSFET на D4184 (2 канала каждая)
- LED-модули 12 В: high-CRI белый 2700–3000K (задний ход) + красные/жёлтый (стоп/габарит/поворот)
- Buck 12→5 В (mini-360 / MP1584)
- Источник 12 В: адаптер barrel ЛИБО USB-C PD-триггер 20 В + buck→12 В
- Предохранитель + держатель на линию 12 В
- Провода, клеммы, термоскотч/алюминиевая подложка под диоды
- (для финальной компактной версии) Seeed XIAO ESP32-C6

## 12. Справочные факты

- Штатные лампы 2106 (для справки, заменяются на LED): поворот A12-21-3 (21 Вт, оранжевая),
  стоп ~21 Вт, габарит ~5 Вт, задний ход ~21 Вт. 12 В.
- USB-PD фиксированные профили: 5/9/15/20 В (12 В — опционально, часто отсутствует).
- D4184 (AOD4184): N-канальный, ~40 В, logic-level (Vgs(th) ≈ 1.35–2.35 В), низкий Rds(on).
- Белый LED: Vf ≈ 2.8–3.4 В.
- Zigbee end-device привязывается только к ОДНОМУ координатору (Миди ИЛИ HA, не оба сразу).

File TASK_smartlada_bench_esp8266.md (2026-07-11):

# ТЗ для Claude Code — стенд «SmartLada» (bring-up PWM, ESP8266)

> **СТАТУС: ВЫПОЛНЕНО 2026-07-06.** Прототип рабочий, все пункты Definition of Done
> закрыты, схема подключения проверена на реальных лампах фонаря.
> Код и калибровка: https://github.com/saschapo/smartlada (`calibration/2026-07-06_bench.json`).
> Отклонения от ТЗ, выявленные железом:
> - Плата стенда — HW-364A (не HW-365A): бортовой OLED занимает GPIO12/14,
>   поэтому CH2 `turn` перенесён на GPIO15; добавлен слой `display` (вне ТЗ, выбрасывается).
> - Фонарь 2106 конструктивно объединяет минусы патронов — для low-side коммутации
>   схема переполюсована: общая плата фонаря = общий **+12 В**, индивидуальные
>   контакты патронов = раздельные коммутируемые выводы на стоки D4184.
> - Джиттер softPWM не наблюдался; мерцание 100–1000 Гц глазом неразличимо
>   (тепловая инерция нитей). Выбрано 100 Гц.

> Самодостаточная постановка задачи. Не требует истории чата.
> Связанные документы проекта (в этой же папке): `PROJECT_2106_SMART_LIGHT.md` (общий контекст),
> `schematic_2106_ESP32.md` (силовая схема, версия на лампах накаливания).

## 0. Контекст проекта (кратко)

Умный светильник из заднего фонаря ВАЗ-2106. 4 автомобильные лампы накаливания 12 В
управляются через 4 модуля **D4184** (N-канальный MOSFET, low-side PWM, logic-level,
открывается от 3.3 В). Финальная прошивка будет на **ESP32-C6** (Zigbee, привязка к
Яндекс Станции Миди, 4 dimmable-light эндпоинта). **Этот документ — НЕ финальная прошивка,
а калибровочный стенд на ESP8266**, пока C6 в доставке.

## 1. Назначение и границы

**[Цель]** Проверить «железную» часть управления 4 лампами через D4184 (PWM, low-side)
и снять числа калибровки.

**[Переносится на ESP32-C6]** слои `channels` и `config` + числа калибровки (JSON).
**[Выбрасывается на C6]** слои `web` (AP+HTTP+UI) и `platform_pwm` (ESP8266) — на C6
управление идёт через Zigbee от Алисы, PWM через LEDC.

**[ВНЕ скоупа — НЕ добавлять]** Wi-Fi-провижининг, MAC-в-SSID, QR, Zigbee, realtime/WebSocket,
аутентификация, OTA, внешние PWM-библиотеки, внешние CDN.

## 2. Карта каналов (подписать в коде и UI именно так)

| Idx | Секция (key) | Название | Мощность | Рассеиватель | Группа дефолтов |
|----|---|---|---|---|---|
| CH0 | `stop` | Стоп | 21 Вт | красный | A (21 Вт) |
| CH1 | `reverse` | Задний ход | 21 Вт | прозрачный | A (21 Вт) |
| CH2 | `turn` | Поворот | 21 Вт | жёлтый | A (21 Вт) |
| CH3 | `marker` | Габарит | 5 Вт | красный | B (5 Вт) |

**[Важно]** **4 независимых канала** (массив из 4 полных наборов калибровки). Группы A/B —
ТОЛЬКО начальные дефолты, не ограничение: каждый канал редактируется отдельно. Совпадение
CH0–CH2 после калибровки — возможный результат, а не предпосылка.

Подписи в UI и JSON — по `key`/названию секции, НЕ по голым номерам (чтобы не путать при калибровке).
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

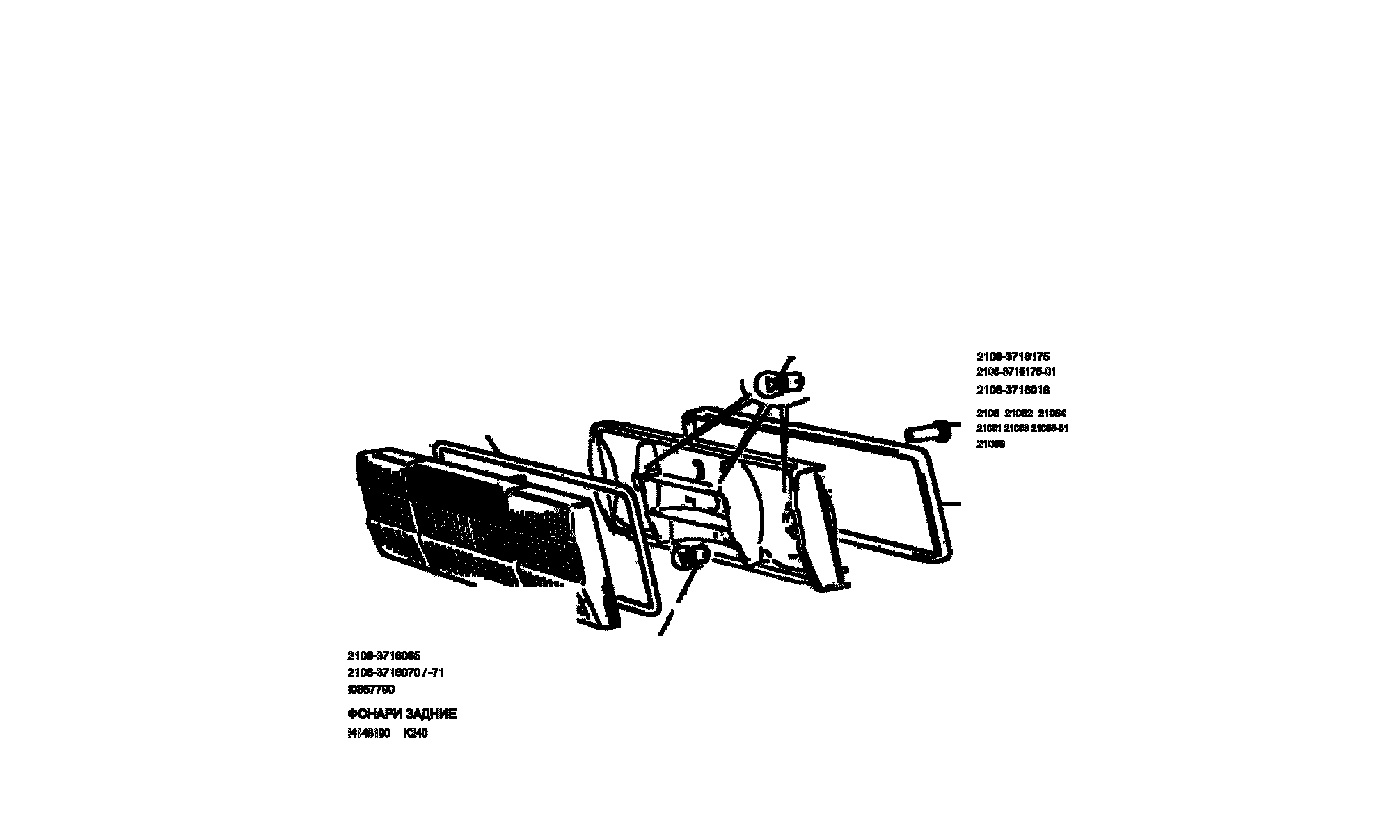
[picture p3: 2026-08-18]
custom_pcb/smartlada_revC/silkscreen/2106_lamp_schematic_back_silkscreen_100x59mm.png

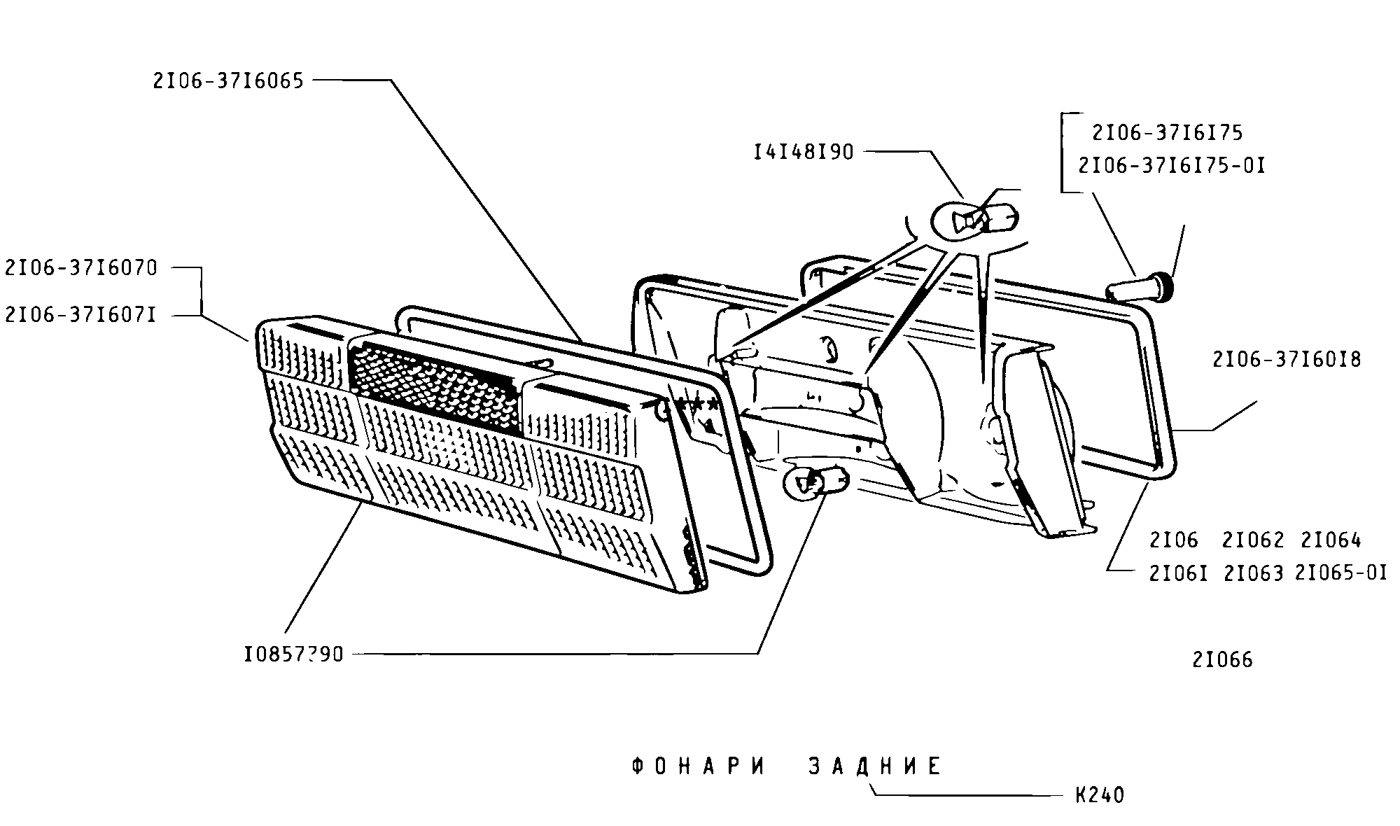
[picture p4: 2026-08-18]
custom_pcb/smartlada_revC/silkscreen/2106_lamp_schematic_back_silkscreen_approved_v2_100x59mm.png

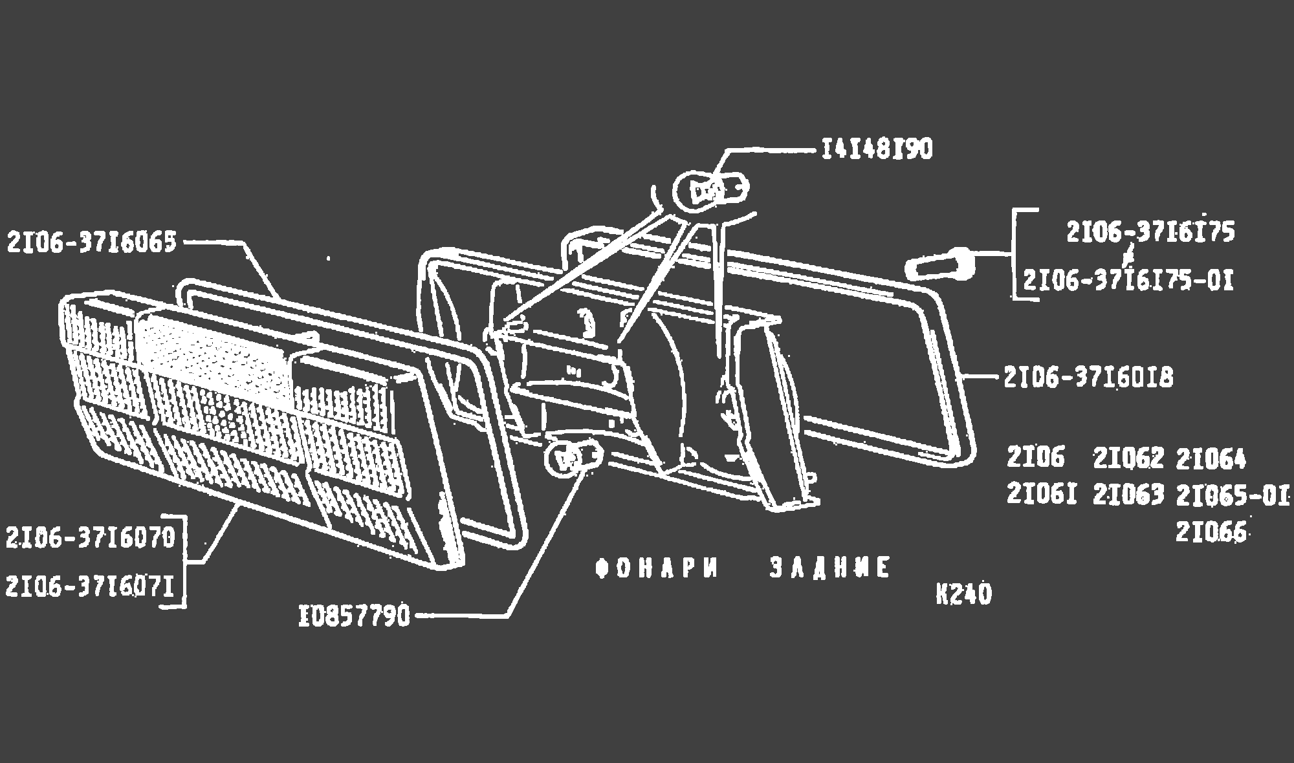
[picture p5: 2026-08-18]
custom_pcb/smartlada_revC/silkscreen/2106_lamp_schematic_white_ink_preview_100x59mm.png

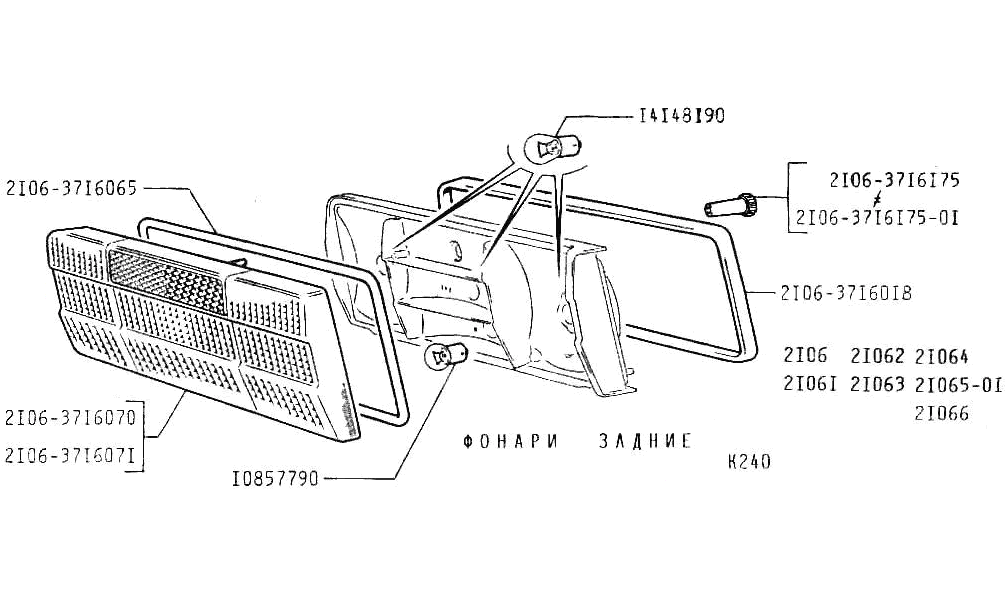
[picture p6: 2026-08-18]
custom_pcb/smartlada_revC/silkscreen/2106_lamp_schematic.png

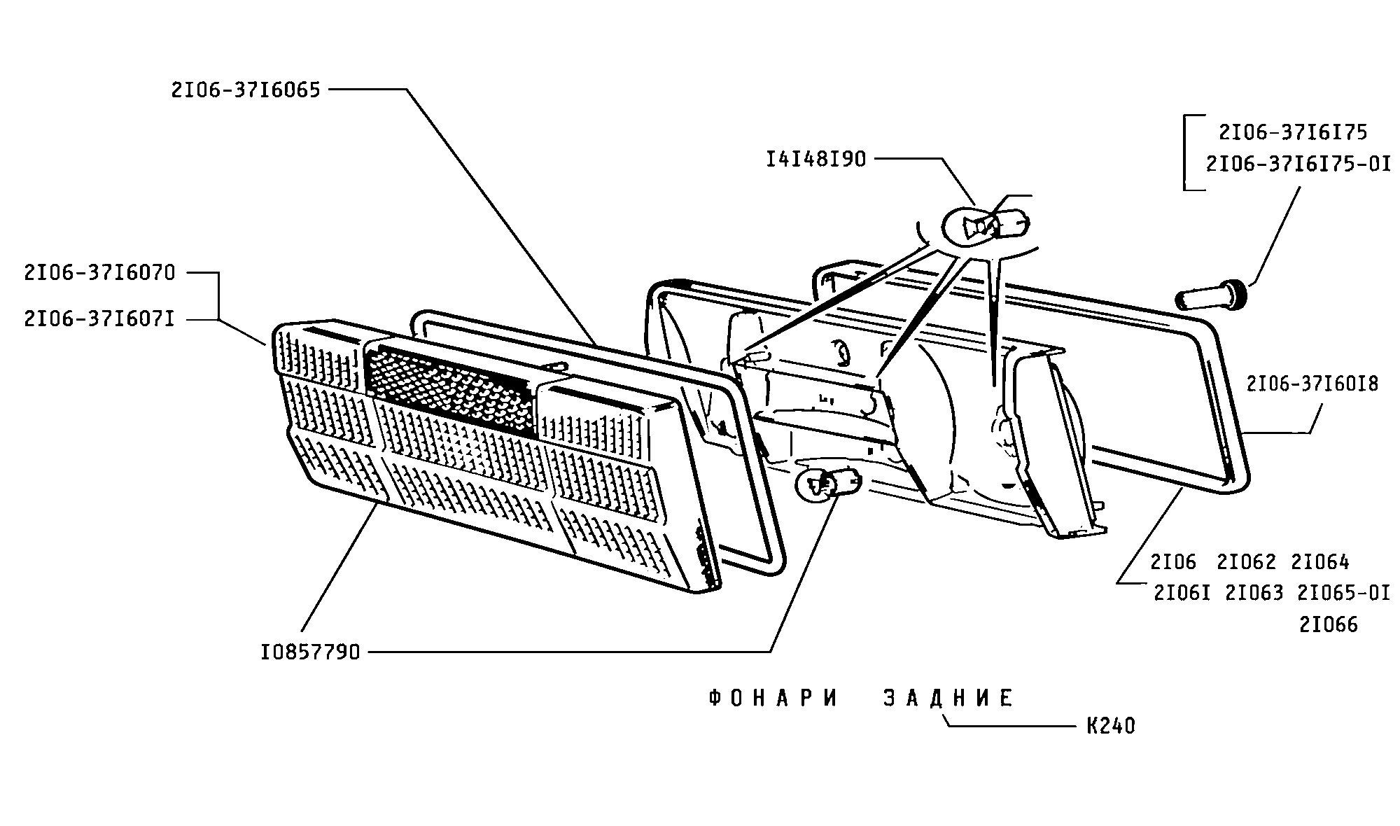
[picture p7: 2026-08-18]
custom_pcb/smartlada_revC/silkscreen/2106_lamp_schematic_back_silkscreen_approved_100x59mm.png

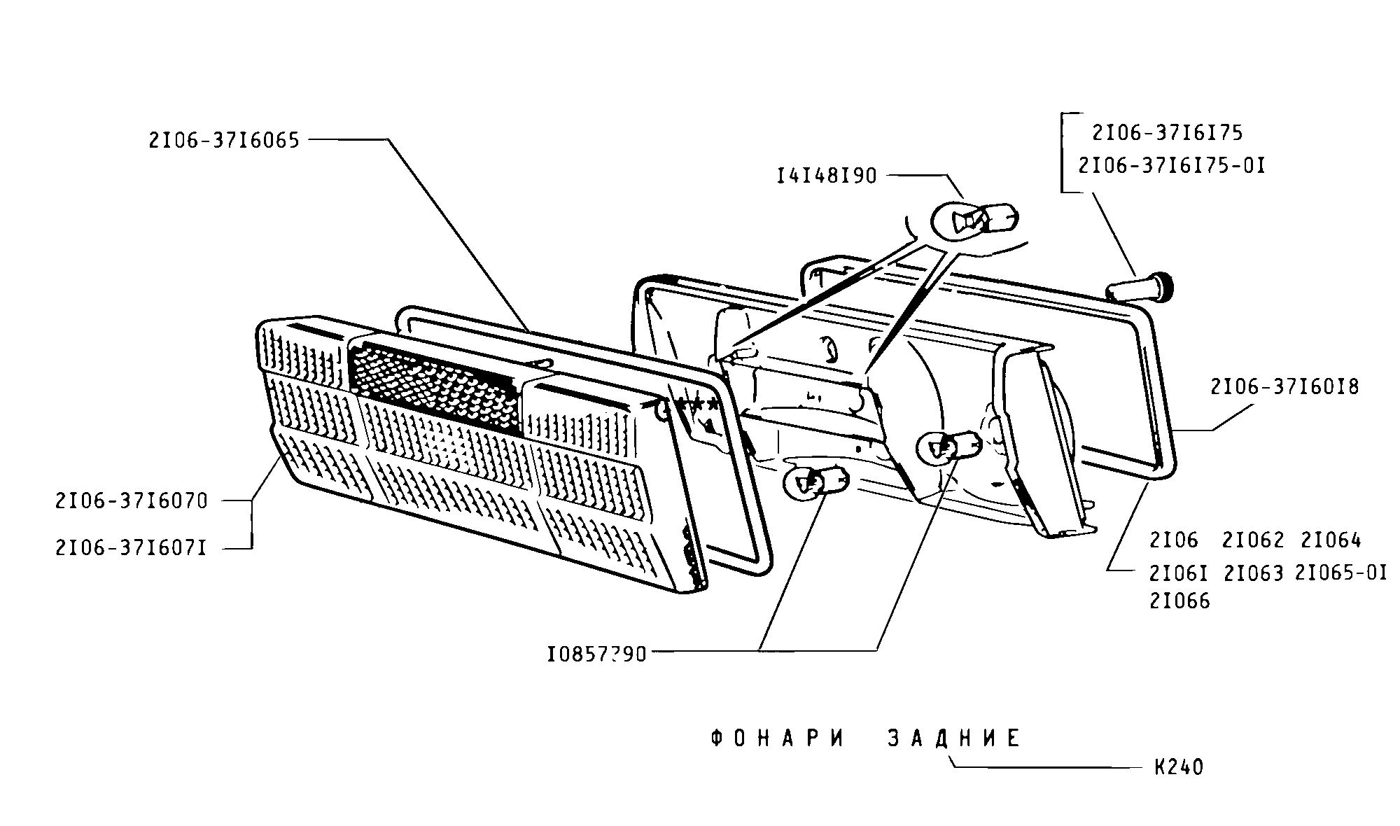
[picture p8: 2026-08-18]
custom_pcb/smartlada_revC/silkscreen/2106_lamp_schematic_back_silkscreen_approved_v3_100x59mm.png

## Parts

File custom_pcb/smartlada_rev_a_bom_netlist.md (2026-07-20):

# SmartLada Rev A — carrier board for nanoESP32-C6

Minimal DIY carrier that replaces the **4x D4184 module + loose wiring**. The
**MuseLab nanoESP32-C6 devboard is kept as-is** and connects through an 8-pin header
(J3) on flying leads.

Two decisions, taken deliberately and for different reasons:

- **Not integrating the ESP32-C6-WROOM-1 module.** The devboard is already proven (3 h
  continuous 30 kHz run, 2026-07-11), and keeping it removes the RF keepout, USB-C,
  EN/RC, BOOT/RESET and module decoupling from this board entirely.
- **Not socketing the devboard either, yet.** Its physical pin order is unconfirmed and
  the board on order differs from the one the available drawings describe. J3 lets the
  power stage be laid out and built now, with the pin mapping deferred to wiring time.

Both are Rev B topics, to revisit once the power stage has been driven and the real
devboard is in hand.

Supply: **Ecola B2L080ESB**, 12 V DC regulated, 80 W / 6.6 A (indoor, not a vehicle
bus). Load: 4x R10W 12 V BA15S, 0.83 A/channel, 3.33 A / 40 W total.

Firmware: **no changes required.** Pins stay `GPIO0..3` (PWM), `GPIO8` (WS2812, on the
devboard), `GPIO9` (button, on the devboard).

---

## 1. What the carrier does and does not contain

| Block | In Rev A | Why |
|---|:---:|-----|
| 4x low-side MOSFET + gate network | yes | the actual point of the board |
| 12 V input, fuse, reverse polarity | yes | one wiring mistake must not kill the devboard |
| 12 V -> 5 V buck | yes | feeds the devboard's onboard AMS1117 |
| J3 header for the devboard | yes | flying leads; sockets deferred to Rev B |
| Lamp + supply screw terminals | yes | — |
| I2C header (J4) | **no** | dropped from Rev A — see 3.4. J3.8 reserved for its 3V3 |
| USB, ESD, EN/RC, BOOT/RESET, WS2812 | **no** | all present on the devboard |
| TVS on 12 V | **no** | regulated indoor PSU, resistive load, no transient source |
| Drain-source snubbers | **no** | incandescent lamps are resistive; add in Rev B only if EMI shows up |
| ADS1115, NTC, 12 V sense | **no** | firmware does not use them, and the 3 h thermal run showed no heating |

---

## 2. Power architecture — the one non-obvious decision

From the devboard schematic (`hardware/nanoESP32C6.pdf`, sheet `nanoESP32-C6 v1.0`):

```text
J4 VBUS (CH343 USB-C) --+
                        +-- F1 --+-- 5V (header pin) --+-- U3 AMS1117-3.3 --> 3V3
J5 VBUS (native USB-C) -+                              |
                                                       +-- (nothing else)
```

Note: `J4`, `J5`, `F1` and `U3` above are **the devboard's own designators**, from its
schematic. They are unrelated to this carrier's `J1..J3` and `F1`.

**The header's `5V` pin is tied straight to both USB VBUS rails through F1, with no
blocking diode.** So driving that pin from our buck would put our output in direct
contention with a laptop's USB VBUS whenever someone plugs USB in to flash or watch
logs — which is exactly what you will do, constantly.

Fix: **buck set to 5.0 V, feeding the `5V` pin through a series Schottky D1 (SS14).**

```text
12V --> U2 buck (5.0 V) --> D1 SS14 --> ~4.65 V --> header 5V pin --> AMS1117 --> 3V3
```

Why this works in all three cases:

| Situation | Result |
|---|---|
| 12 V only | 4.65 V into AMS1117. Dropout ~1.1 V at our current -> 3.3 V holds |
| USB only | D1 reverse-biased, buck isolated. Devboard runs from VBUS as it always did |
| Both | 5.0 V VBUS beats 4.65 V, so USB silently wins. No back-feed into the laptop, no contention |

Do **not** feed the `3V3` pin instead — that back-drives the AMS1117 output, which LDOs
tolerate poorly, and creates the same contention one rail lower.

`3V3` on the header is an **output** here; use it only for the I2C pull-ups.

---

## 3. BOM

Passives 0805 unless noted, X7R or better, 1% on the feedback divider.

### 3.1 12 V input

| Ref | Qty | Value / PN | Package | Notes |
|-----|-----|---|---|---|
| J1 | 1 | screw terminal 2-pos, 5.08 mm | THT | 12 V IN |
| F1 | 1 | T4A slow-blow 5x20 mm + clips | THT | slow-blow is mandatory: cold-filament inrush ~8-10 A per lamp |
| Q5 | 1 | **AOD4185** | TO-252 (DPAK) | P-channel reverse-polarity FET in the +12 V line |
| R1 | 1 | 100 k | 0805 | Q5 gate pull-down to GND |
| C1 | 1 | 100 uF / 25 V | THT electrolytic | 12 V bulk; buffers the 30 kHz switching of 3.33 A |
| C2 | 1 | 100 nF / 50 V | 0805 | HF bypass |

No TVS and no gate zener: with no clamping device on the bus, Q5 sees Vgs = 12 V,
comfortably inside its +/-20 V rating.

### 3.2 12 V -> 5 V buck

| Ref | Qty | Value / PN | Package | Notes |
|-----|-----|---|---|---|
| U2 | 1 | **TPS54202DDCR** | SOT-23-6 | 4.5-28 V in, 2 A, synchronous, 500 kHz. Pins: 1 GND, 2 SW, 3 VIN, 4 FB, 5 EN, 6 BOOT |
| L1 | 1 | 10 uH, >=2 A sat, shielded | 6x6 mm | CDRH6D28NP-100NC. See note below |
| C3, C4 | 2 | 10 uF / 50 V X5R | 1210 | Vin, immediately adjacent to U2. Datasheet asks for >10 uF ceramic |
| C5 | 1 | 100 nF | 0603 | bootstrap, SW to BOOT — mandatory |
| C6, C7 | 2 | 22 uF / 16 V | 0805 | Vout, before D1 |
| R2 | 1 | 100 k 1% | 0805 | FB upper |
| R3 | 1 | 13.7 k 1% | 0805 | FB lower. Vref 0.596 V -> Vout = 4.95 V. **Trim on first board** |
| D1 | 1 | **SS14** | SMA | series Schottky into the devboard 5 V pin. See section 2 |

**EN is left floating** — SLVSD26C, table 4-1: "Float the EN pin to enable." An internal
pull-up current source enables the device. Place a no-connect flag so ERC stays quiet.

**On the inductor value.** TI's own design example lands on 15 uH, but that is for
VIN(max) = 28 V and IOUT = 2 A. At our 12 V in / 5 V out / ~0.4 A, 10 uH gives ripple
`dIL = (12-5) x 0.4167 / (10u x 500k) = 0.58 A` p-p, peak coil current ~0.7 A against a
2.5 A (min) internal limit, and output ripple `~0.58/(8 x 500k x 25u) = 6 mV`. 10 uH is
fine here; the converter will pulse-skip at light load, which is a documented mode.

Load: C6 RF peak ~350 mA + WS2812 ~60 mA. 2 A is generous; the AMS1117 dissipates
~0.55 W at 4.65 V in / 3.3 V out / 400 mA, which its SOT-223 handles.

### 3.3 Power switches — 4 identical channels (n = 0..3)

| Ref | Qty | Value / PN | Package | Notes |
|-----|-----|---|---|---|
| Q1..Q4 | 4 | **AOD4184A** | TO-252 (DPAK) | N-ch, 40 V, logic-level. Same die family as the proven D4184 module |
| Rg1..Rg4 | 4 | 100 R | 0805 | gate series, same value as the module. 3.3 V / 100 R = 33 mA, under the 40 mA GPIO limit |
| Rpd1..Rpd4 | 4 | 100 k | 0805 | **gate pull-down — critical, do not omit** |
| TP_G0..3 | 4 | 1 mm test pad | copper only | gate probe, not a part |

One FET per channel is ample: the module used two in parallel to reach a 15 A rating,
not for a 0.83 A load. A single die also halves Qg, so switching loss at 30 kHz is
*lower* than the present setup.

### 3.4 Connectors

| Ref | Qty | Value | Notes |
|-----|-----|---|---|
| J2 | 1 | screw terminal 5-pos, 5.08 mm | COM +12 V, CH0-, CH1-, CH2-, CH3- |
| J3 | 1 | male header 2.54 mm, 8-pin single row | **MCU interface — flying leads to the devboard.** See section 4 |
| H1..H4 | 4 | M3 mounting hole, 3.2 mm | corners, 5 mm inset from the edges |
**J4 (I2C service header) is not fitted in Rev A.** It was the only consumer of the
devboard's 3.3 V, so `+3V3_DEV` is dropped with it and `J3.8` is left as a reserved,
unconnected pin (section 4.1). Nothing else on the board wanted that rail.

If I2C comes back in Rev B, note that **there are no pull-ups anywhere in this system.**
Verified against the devboard schematic: its only resistors are 10 k on `CHIP_PU` and
`GPIO9` (EN and BOOT), 22 R in series with the USB lines, and 5.1 k CC resistors on both
USB-C receptacles. `GPIO18` and `GPIO19` are plain unloaded pins. Most breakout modules
carry their own pull-ups; a bare sensor chip will not communicate without two 4.7 k to
3.3 V.
| TP1..TP4 | 4 | 1 mm test pads | 12V, 5V, 3V3, GND |

**Distinct part numbers: 13.** Total placements: ~28.

---

## 4. MCU interface — J3

Rev A does **not** socket the devboard. The devboard sits loose and is wired to J3 with
8 dupont leads.

Reason: the devboard's physical pin order is still unconfirmed (section 7), and the
board on order is not the one the available drawings describe. Committing socket
footprints now would gate the whole PCB on a fact we do not have. An 8-pin header does
not care about pin order — the mapping is decided at assembly time, with wires.
Socketing is a Rev B decision, once the actual board is in hand and measured.

### 4.1 J3 pinout

| Pin | Net | Dir | Wire to devboard |
|----:|-----|-----|---|
| 1 | +5V_DEV | **out** | `5V` pin |
| 2 | GND | out | any `G` pin |
| 3 | CH0_IN | in | `GPIO0` — stop |
| 4 | CH1_IN | in | `GPIO1` — reverse |
| 5 | CH2_IN | in | `GPIO2` — turn |
| 6 | CH3_IN | in | `GPIO3` — marker |
| 7 | GND | out | any `G` pin |
| 8 | *(reserved)* | — | **nothing — leave unwired** |

Seven flying leads, not eight. Pin 8 is a reserved pad: it carried the devboard's 3.3 V
solely to feed the J4 pull-ups, and J4 is not fitted in Rev A. The pad stays so that pin
numbering does not shift if I2C returns in Rev B. Give it a no-connect flag in the
schematic and mark it `NC` on the silkscreen so nobody lands a wire on it.

Silkscreen must mark pin 1 and its direction: pin 1 **sources** ~400 mA into the
devboard.

Two grounds, at pins 2 and 7, are deliberate: they flank the four signal lines so each
gate drive has a return path close by. Use a ribbon or twisted bundle, not four wires
strung separately across the bench.

### 4.2 Why flying leads are electrically acceptable here

The wires carry **logic signals, not the gate nodes**. `Rg` and `Rpd` stay on the
carrier next to their own MOSFET, so the gate loop is short regardless of lead length,
and `Rg` damps ringing between the lead inductance and Cgs.

The 3.3 V / 100 R gate drive is 33 mA peak at 30 kHz — slow edges, modest current,
tolerant of 10-15 cm of wire. Do not extend this to half a metre.

The lamp current never touches these wires: 3.33 A returns through the carrier's PGND
polygon to J1. Only gate drive and the devboard's own ~400 mA supply flow through J3.

One useful property falls out of `Rpd` living at the gate: **if a dupont lead falls off,
that channel turns OFF, not on.** The same pull-down that covers the boot window covers
a disconnected wire.

### 4.3 Devboard pin order — for wiring, not for the PCB

The table below is the best available reading, from the **vendor mechanical drawing**
(dimensioned, `Unit: mm`), whose signal set matches the `HEADER` block of
`nanoESP32C6.pdf`. Two single-row 2.54 mm headers, **16 positions each**, order
top-to-bottom with the two USB-C connectors at the bottom edge.

**Treat it as provisional.** It describes a board that is not the one on order, and it
conflicts with a community colour pinout (section 7). Verify against the silkscreen of
the actual board before landing a single wire. With J3 this is a wiring mistake to
correct, not a PCB respin — which is the point.

| # | LEFT row | Wire to | # | RIGHT row | Wire to |
|--:|---|---|--:|---|---|
| 1 | 3V3 | - *(Rev B: J3.8)* | 1 | G | **J3.2 or J3.7** |
| 2 | RST (CHIP_PU) | - | 2 | TX (GPIO16 / U0TXD) | - |
| 3 | GPIO4 | - strapping | 3 | RX (GPIO17 / U0RXD) | - |
| 4 | GPIO5 | - strapping | 4 | GPIO15 | - strapping |
| 5 | GPIO6 | - | 5 | GPIO23 | - |
| 6 | GPIO7 | - | 6 | GPIO22 | - |
| 7 | **GPIO0** | **J3.3 — CH0 stop** | 7 | GPIO21 | - |
| 8 | **GPIO1** | **J3.4 — CH1 reverse** | 8 | GPIO20 | - |
| 9 | GPIO8 | - RGB LED + strapping | 9 | GPIO19 | - *(Rev B: I2C SCL)* |
| 10 | GPIO10 | - | 10 | GPIO18 | - *(Rev B: I2C SDA)* |
| 11 | GPIO11 | - | 11 | GPIO9 | - BOOT button + strapping |
| 12 | **GPIO2** | **J3.5 — CH2 turn** | 12 | G | **J3.2 or J3.7** |
| 13 | **GPIO3** | **J3.6 — CH3 marker** | 13 | GPIO13 | - **USB D+** |
| 14 | **5V** | **J3.1** | 14 | GPIO12 | - **USB D-** |
| 15 | G | **J3.2 or J3.7** | 15 | G | **J3.2 or J3.7** |
| 16 | NC | - | 16 | NC | - |

**Never land a wire on these:**

- `GPIO12` / `GPIO13` — native USB D-/D+. A wire here breaks flashing and logging.
- `GPIO4`, `GPIO5`, `GPIO8`, `GPIO9`, `GPIO15` — strapping pins. `GPIO8` also drives the
  onboard WS2812 and `GPIO9` is the BOOT button; the firmware uses both as-is.
- `3V3` — output of the onboard AMS1117. It feeds J3.8; never drive it from the carrier.

### 4.4 Devboard mechanical envelope — informational, for Rev B

| Dimension | Value |
|---|---|
| Board outline | **25.40 x 51.80 mm** |
| Header row spacing | **22.86 mm (0.9")** |
| Header pitch | 2.54 mm, 16 positions per row |
| Module (MINI-ANT-TYPEB) width | 18.00 mm, 6.35 mm from the top edge |
| First header pin from top edge | 6.35 mm |
| Edge to header centre | 1.27 mm |

Not used in Rev A. **The reserve was considered and dropped:** a 26 x 52 mm clear
rectangle does not fit on the final 80 x 65 mm outline alongside the components, and
Rev A wires the devboard with flying leads anyway, so it sits beside the board. If Rev B
sockets the devboard the outline has to change regardless.

The numbers are kept here so they are not lost. If that path is taken, remember that
standard 2.54 mm sockets give about 8.5 mm of clearance — the 100 uF electrolytic C1 and
the fuse holder F1 are the tall parts and must stay outside the footprint, and the
devboard's bottom edge (both USB-C) has to face outward.

---

## 5. Draft schematic — net by net

### 5.1 Nets

```text
+12V_IN     J1.1 -> F1.1                      3.33 A
+12V_FUSED  F1.2 -> Q5.D                      3.33 A
+12V        Q5.S -> C1, C2, C3, C4, U2.VIN, J2.1 (LAMP_COM)   3.33 A
+5V_SW    U2 output -> D1 anode
+5V_DEV   D1 cathode -> J3.1
GND       logic ground; J3.2, J3.7
PGND      lamp return; joined to GND at ONE star point near J1
CH0..3_IN J3.3..J3.6 -> Rg -> GATE0..3
GATE0..3  Rg output, Rpd to PGND, Q gate, TP_G0..3
LAMP0..3  J2.2..J2.5 -> Q1..Q4 drain
```

### 5.2 Input stage

```text
 J1.1 --[F1 T4A]--+-- Q5.D                 Q5 = AOD4185, P-channel
                  |     |
                  |   Q5.G --[R1 100k]-- GND
                  |     |
                  |   Q5.S --+---- +12V bus --> U2.Vin
                  |          |               --> J2.1 LAMP_COM
                  |     [C1 100u] [C2 100n]
                  |          |        |
 J1.2 ------------+---------GND------GND
```

**Q5 orientation — get this right, it is the classic mistake.** The body diode of a
P-channel runs anode on drain, cathode on source, i.e. it conducts drain -> source. For
the protection to work the body diode must point **along** the normal current direction,
so that reverse polarity finds it blocking. Normal current goes input -> load, therefore:

**drain to the incoming +12 V, source to the board bus.**

| | Normal | Reverse polarity |
|---|---|---|
| Body diode | forward, pulls the bus up to ~11.4 V | drain at -12 V, source ~0 V -> **blocked** |
| Vgs | source ~12 V, gate 0 V -> -12 V -> **on**, shorting out the diode | 0 V -> **off** |

Wired the other way round (source to input) the board still works on the bench, and
still fails on reverse: Vgs goes to +12 V and the channel closes correctly, but the body
diode is then forward-biased and passes the reverse current straight through the load.
The failure only shows up on the one event the part exists for.

### 5.3 Per-channel switch (x4)

```text
      +12V ------------------> J2.1  LAMP_COM
                                 |
                            [ R10W lamp ]   (external)
                                 |
                            J2.(n+2)  LAMPn
                                 |
  J3.(n+3) CHn_IN --[Rg 100R]--+-- GATE n   |
                            |               |
                        [Rpd 100k]      Q(n) drain
                            |          +----+----+
                            |          | AOD4184A|
                            |          +----+----+
                            |            source
                           PGND ------------+
```

`Rpd` sits physically **at the gate**, not on the MCU side of `Rg`. This is what holds
the lamps off in the window between reset and `platform_pwm::forceAllLow()`, while
`GPIO0..3` are still floating inputs.

No flyback diode: incandescent lamps are resistive.

---

## 6. Layout rules that matter here

1. **Single-point ground join.** PGND carries up to 3.33 A with 30 kHz edges. Route it
   to the J1 return without passing under U2 or the devboard. Join PGND and GND at one
   point at J1.
2. **SW node small.** U2's SW copper is the only real radiator on this board. Follow the
   TPS54202 datasheet layout figure literally.
2a. **FB ground is a separate return.** SLVSD26C, pin 1 description: "Connect sensitive
   VFB to this GND at a single point." Route R3's ground to U2's GND pin directly rather
   than dropping it into the nearest pour.
3. **Gate loops short.** Rg and Rpd next to their own FET; gate return into local PGND.
   Put the four MOSFETs in a column with J3 on one side of it and the lamp terminal J2
   immediately outboard on the other, so `CHn_IN` runs J3 -> Rg -> gate with no detour.
   The 12 V input and the buck take the far side of the board.
7. **J3's ground is the reference for gate drive.** Tie J3.2 / J3.7 to the quiet logic
   ground near the buck output, **not** into the middle of the lamp return path. If the
   devboard's ground reference sits somewhere along the 3.33 A PGND run, the IR drop
   across that copper appears directly as gate-drive noise.
4. **Copper for 3.33 A — and that means all three input segments.** The fuse and Q5 each
   split the input rail, so the 3.33 A path is three separate nets: `+12V_IN` (J1 to F1),
   `+12V_FUSED` (F1 to Q5 drain) and `+12V` (Q5 source onward). A `+12V` copper pour
   covers only the last one — it cannot and must not bridge the other two, or it would
   short out the fuse and the reverse-polarity FET.

   All three need POWER-class width. At 1 oz and 10 C rise, IPC-2221 gives ~1.6 mm for
   3.33 A; the `POWER` netclass is set to 1.5 mm, which is ~11 C. For reference, the
   0.2 mm `Default` width at 3.33 A works out to roughly a 300 C rise — that trace is a
   fuse, not a conductor. **DRC does not check current**, so this is on you, not the tool.

   Netclass patterns must use leading wildcards (`*12V*`, `*LAMP*`): local labels on the
   root sheet become `/LAMP0`, `/+12V_IN` etc., while power symbols stay bare (`+12V`,
   `GND`). A pattern of `LAMP*` may miss `/LAMP0`.
5. **Thermal vias** under the Q1..Q5 DPAK tabs. Calculated dissipation is low, but they
   cost nothing and hedge the cold-filament inrush case.
6. Keep the buck away from the devboard's antenna end.

---

## 6a. As built

Board **80 x 65 mm**, 2 layers, 1 oz, 1.6 mm. ERC 0/0, DRC 0 violations / 0 unconnected /
0 footprint errors. All signals on F.Cu (323.5 mm); B.Cu carries only a 5.3 mm feedback
ground link, leaving the GND pour as one uninterrupted island covering 93% of the board.
8 vias, all GND. Silkscreen is functional and 0-based, matching the firmware:
`LAMP 0: STOP / 1: REV / 2: TURN / 3: MARKER` and `GPIO_0_stop .. GPIO_3_marker`.

Process notes, KiCad traps and the full list of errors caught in review are in
[KICAD_WORKFLOW.md](KICAD_WORKFLOW.md).

---

## 7. Open items

- [ ] **Devboard pin order — no longer blocks the PCB, still blocks wiring.** Three
      readings disagree: the vendor mechanical drawing in section 4.3 (16 pins/row,
      `GPIO2`/`GPIO3` on the left), a community colour pinout (15 pins/row,
      `GPIO2`/`GPIO3` on the right), and the board actually on order, which is neither.
      All carry the same signal *set*, so the schematic cannot arbitrate — only the
      board can. Read the silkscreen when it arrives. Getting it wrong swaps channels
      and can put a gate drive on the USB D+ line, so **verify before landing wires** —
      but with J3 that is a five-minute rewire, not a respin.
- [ ] **AOD4184A Rds(on) and Qg at Vgs = 3.3 V**, not the datasheet's 4.5 V / 10 V
      figures. Recompute the 30 kHz switching loss from
      [mosfet_switch_D4184.md](../SmartLadaC6/docs/mosfet_switch_D4184.md) for a single die.
- [ ] **AOD4184A SOA at inrush** (~8-10 A for tens of ms). Firmware soft-start limits
      this; confirm the FET survives `soft_start_ms = 0` being set by mistake.
- [ ] **The 5 V window is tight — measure and trim R3 on the first board.** Verified
      against SLVSD26C: Vref is 0.581 / 0.596 / 0.611 V (min/typ/max), so R2 = 100 k +
      R3 = 13.7 k gives 4.95 V typical but roughly **4.68-5.22 V** across the Vref spread
      plus 1% resistors. Minus the SS14 drop (~0.4 V) that is **4.3-4.8 V** at the
      devboard `5V` pin, against a required window of:
      - **>= ~4.4 V**, or the AMS1117 cannot hold 3.3 V at peak current;
      - **< USB VBUS**, or the board back-feeds the laptop instead of yielding to it.

      Worst-case corners fall outside on both ends. Not a redesign — R3 is one resistor
      — but do not assume it lands correctly. Measure the buck output on the first
      board and pick R3 to put the post-diode voltage near 4.6 V.
- [ ] **AMS1117 dropout** at ~4.6 V in and the devboard's real peak current, from the
      specific vendor's datasheet. This sets the lower edge of the window above.

---

## 8. Explicitly deferred

Per-channel current sense, NTC / thermal cutout, 12 V monitoring, WROOM-1 integration,
CAN/LIN, automotive front end. See sections 4 and 8 of
[smartlada_custom_pcb_kicad.md](smartlada_custom_pcb_kicad.md).

---

**Sources:** [wuxx/nanoESP32-C6](https://github.com/wuxx/nanoESP32-C6/) and its
[hardware/nanoESP32C6.pdf](https://github.com/wuxx/nanoESP32-C6/blob/master/hardware/nanoESP32C6.pdf)
schematic; project docs `board_nanoESP32-C6.md`, `mosfet_switch_D4184.md`.

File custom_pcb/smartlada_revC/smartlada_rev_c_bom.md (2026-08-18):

# SmartLada Rev C — BOM (в работе)

Проверка по Платану (`www.platan.ru` API). Правило: пассивы **0805 `*_HandSolder`**, ИС/разъёмы
паяемые вручную. Цены/наличие — на 2026-08-13, меняются. **QUANTY 0 + POSTAV «N дней» = на
главном складе 0, привоз за N дней** (не «нет в наличии»). **Следи за MINZAKAZ (MOQ)** — у части
позиций катушка.

Статус схемы: ядро нарисовано; **не добавлены**: USB-C+CH224K вход, VBUS-делитель, 6× LED,
UART-хедер. Их строки помечены `[добавить в схему]`.

## Активные / ИС

| Ref | Партномер | Корпус | Platan NOM_N | Цена | MOQ | Наличие | Note |
|-----|---|---|---|-----:|----:|---|---|
| U1 | ESP32-C6-WROOM-1-**N16** | модуль | нет на Платане | — | — | **есть (5 шт, Ali)** | закуплено |
| U2 | TPS54202DDCR | SOT-23-6 | **2015708243** | 33 | **1** | 1-2 дня | MOQ 1 — брать этот (не 2014755388 MOQ17) |
| U3 | CH224K | ESSOP-10 | **2016569523** | 36 | 10 | 3-4 дня | PD-триггер 12В; даташит CH224D/K/221K |
| Q1..Q4 | AOD4184A | DPAK | **2010030452** | 30 | 12 | 3-4 дня | ×4 |
| U4 | USBLC6-2SC6 | SOT-23-6 | **2015971466** | 16 | ⚠ | в наличии 2287 | ESD на D+/D- — **оставляем**. Саша видит MOQ 10 на сайте; мой API-снимок показывал 3000 — сверь при заказе |
| L1 | CDRH6D28NP-100NC 10µH | SMD | **2014962957** | 29 | **1** | 1-2 дня | Sumida, MOQ 1 |

## Ножевые клеммы Faston 6.3 мм «папа» (кандидаты, проверены)

| PN | Партномер | Цена | MOQ | Вердикт |
|----|---|-----:|----:|---|
| **2011346771** | **63951-1 (TE)** | 20 | **18** | ✅ **выбран**. Футпринт от **TE 1217754-1** (идентичен по даташиту) — сверить, что PCB-посадка (Ø/шаг выводов) та же, не только лезвие |
| 2010065590 | DJ617-6.3 (Китай) | 14 | 100 | ✅ классика PCB-faston, футпринты комьюнити |
| 2015804554 | L-KLS8-01130-PCF-250 (KLS) | 6 | **5000** | ⚠️ дёшево+в наличии, но MOQ 5000 (катушка) |

Нужно **5 шт** (4 CH + 1 COM) на J2. Ответная часть на провода — female «мама» 6.3 мм (обжим,
заказать отдельно).

## Разъёмы / электромеханика

| Ref | Что | Platan | Note |
|-----|-----|---|---|
| J1 | USB-C **16-pin** (USB 2.0 + PD) | Ali | VBUS/GND/CC1/CC2/D+/D-; брать THT-лапки экрана/гибрид (паять проще); НЕ 6-pin (нет данных), НЕ 24-pin (лишний SS) |
| J2 | 5× Faston tab | см. выше | 63951-1 ×5 |
| J4 | 2.54 pin header 1×8 угловой «папа» | [common] | + кабель BLS-8 мама-мама **10660** |
| J_uart | 3-pin header 2.54 (TX/RX/GND) | [common] | `[добавить в схему]` |
| SW1,SW2 | тактовые кнопки RESET/BOOT | [common] | SMD/THT |

## LED — 6× красный 0805 `[добавить в схему]`

| PN | Партномер | Цена | MOQ |
|----|---|-----:|----:|
| 2012634999 | LC170-SRCT (ParaLight) | 9 | 500 |
| 2011002064 | FYLS-0805URC (Foryard) | 7 | 1000 |

Нужно 6 шт (4 канала + 12В + 3.3В). MOQ высокий — либо катушка, либо ChipDip поштучно.

## Пассивы (проверены по Платану 2026-08-13)

Резисторы 0805 `*_HandSolder`:
| Номинал | Позиции | Platan PN | Допуск | Note |
|---|---|---|---|---|
| 100R | Rg1..4 | 2017101911 (RCT05100RFLF) | 1% | ✅ |
| 100k 1% | **все** (R2 FB, Rpd1..4, R_vbus_top) | **2011428029 (RC0805FR-07100KL)** | 1% | ✅ настоящий 1% (проверено); годится и для FB, и везде |
| 22k | R3 (FB низ) | 2014983933 (ERJ6ENF) | 1% | ✅ |
| 10k | R4, R8, R9 | 2017347591 (CR-05FL7) | 1% | ✅ |
| 33k | R_vbus_bot | 2014967654 (RC0805JR) | 5% | ✅ ADC-делитель |
| 4.7k | LED CH1-4 + 12В (5×) | 2011352451 (RC0805FR-074K7L) | 1% | MOQ 5000 |
| 1k | LED 3.3В | 2014969775 (RC0805FR-071KL) | 1% | ✅ |
| 24k | CH224K CFG1→GND | 2014969370 (RC0805FR-0724KL) | 1% | =12В; CFG2/3=NC |
| 10k | PG-подтяжка к 3V3 `[добавить]` | — | 5% | PG open-drain |

Конденсаторы (корпус ≥0805 hand-solder):
| Номинал | Позиции | Platan PN | Вольтаж/корпус | Note |
|---|---|---|---|---|
| 10µF | C3/C4 (вход buck) | 2014974049 (CL32B106K) | 1210 X7R, **уточнить ≥25В** | шина 12В |
| 22µF | C6/C7/C8 | 2015696919 (HLC1210..226K160N) | 1210 X7R 16В | ✅ 3.3В |
| 100nF | C5, C9 | 2014826976 (GRM21..104..25В) | **0805** X7R 25В | ⚠️ C5-футпринт в схеме 0603 — исправить на 0805 |
| 1µF | C10 | 579760124 (GRM21..105) | 0805 X7R 25В | MOQ 3000 |
| 470µF | C_bulk (шина 12В) | 696157719 (EEEFK1E471P) | SMD электролит **25В** | ✅ |

> Заказ: Платан или **ChipDip поштучно** (у части — MOQ-катушка: 4k7=5000, 1µF=3000, 22µF=1000).
> Правило: **не мельче 0805**.

## Источники (резюме)
- **Ali/дома:** ESP32-C6-WROOM-1-N16 (5 шт есть), LED 0805, пассивы R/C (≥0805), USB-C 16-pin.
- **Платан:** TPS54202DDCR, CH224K, AOD4184A ×4, USBLC6-2SC6, L1 Sumida, Faston 63951-1 ×5, BLS-8 (10660).
- **ChipDip:** пассивы поштучно (если MOQ-катушка на Платане мешает).

## Открытые вопросы — закрыты
1. USB-C J1 — **16-pin USB 2.0** (Ali). ✅
2. USBLC6 — **оставляем** (2015971466). ✅
3. ESP — **N16**, закуплен. ✅

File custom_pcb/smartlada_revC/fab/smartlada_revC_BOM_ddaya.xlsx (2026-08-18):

Name | Designator | Footprint | Supplier Part (LCSC)
1 µF 25V X7R 0805 | C1,C10 | C0805
100 nF 50V X7R 0805 | C2,C5,C9 | C0805
10 µF 25V X7R 1210 | C3,C4 | C1210
22 µF 16V X7R 1210 | C6,C7,C8 | C1210
470 µF 25V Alu SMD | C11 | Alu SMD 10x10.2
LED red 0805 | D1,D2,D3,D4,D5,D6 | LED0805
USB-C receptacle 16P (TYPE-C-31-M-12) THT | J1 | USB-C 16P
Faston 6.3 mm tab (63951-1) THT | J2,J3,J5,J6,J7 | Faston 6.3
Pin header 1x8 right-angle 2.54 mm THT | J4 | Header 1x8 RA
Pin header 1x3 right-angle 2.54 mm THT | J8 | Header 1x3 RA
CDRH6D28NP-100NC 10 µH | L1 | SMD 7x7mm
AOD4184A N-MOSFET 40V 50A | Q1,Q2,Q3,Q4 | TO-252 (DPAK)
1 kΩ ±5% 0805 | R1,R12 | R0805
10 kΩ ±1% 0805 | R2,R6,R9,R10,R11 | R0805
24 kΩ ±1% 0805 | R3 | R0805
22 kΩ ±1% 0805 | R4 | R0805
100 kΩ ±1% 0805 | R5,R7,Rpd1,Rpd2,Rpd3,Rpd4 | R0805
33 kΩ ±5% 0805 | R8 | R0805
4.7 kΩ ±1% 0805 | R13,R14,R15,R16,R17 | R0805
100 Ω ±5% 0805 | Rg1,Rg2,Rg3,Rg4 | R0805
Tactile switch 6x6 (B3FS1010P) SMD | SW1,SW2 | SW 6x6 SMD
ESP32-C6-WROOM-1-N16 module | U1 | WROOM module
TPS54202DDCR buck converter | U2 | SOT-23-6
CH224K USB-PD trigger | U3 | SSOP-10 (EP)
USBLC6-2SC6 USB ESD | U4 | SOT-23-6

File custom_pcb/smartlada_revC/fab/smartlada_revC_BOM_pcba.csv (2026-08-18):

Designator | Comment | Footprint | MPN | Manufacturer | Qty/board | Side | Populate | LCSC | Note
C1;C10 | 1uF X7R | 0805 | CC0805KFX7R8BB105 | Yageo | 2 | Top | Yes
C2;C5;C9 | 100nF 50V X7R | 0805 | TCC0805X7R104K500DT |  | 3 | Top | Yes |  | match by MPN
C3;C4 | 10uF 25V X7R | 1210 | CL32B106KAJNNNE | Samsung | 2 | Top | Yes
C6;C7;C8 | 22uF 16V X7R | 1210 | HLC1210X7R226K160N |  | 3 | Top | Yes |  | match by MPN
C11 | 470uF 25V | SMD Alu 10x10.2mm | EEEHA1E471P | Panasonic | 1 | Top | Yes |  | POLARIZED (+ mark)
D1;D2;D3;D4;D5;D6 | LED red | LED 0805 |  |  | 6 | Top | Yes |  | POLARIZED (cathode); any 0805 red
J1 | USB-C receptacle 16P | USB-C THT | TYPE-C-31-M-12 | HRO | 1 | Top | Yes |  | THROUGH-HOLE
J2;J3;J5;J6;J7 | Faston tab 6.3mm | Faston THT | 63951-1 | TE | 5 | Top | Yes |  | THROUGH-HOLE (OUT0-3 + common +12V)
J4 | Pin header 1x8 right-angle | 2.54mm 1x8 THT |  |  | 1 | Top | Yes |  | THROUGH-HOLE; generic; cut from strip
J8 | Pin header 1x3 right-angle | 2.54mm 1x3 THT |  |  | 1 | Top | Yes |  | THROUGH-HOLE; generic
L1 | 10uH inductor | SMD 7x7mm | CDRH6D28NP-100NC | Sumida | 1 | Top | Yes
Q1;Q2;Q3;Q4 | AOD4184A N-MOSFET | TO-252/DPAK | AOD4184A | AOS | 4 | Top | Yes |  | orient pin1
R1;R12 | 1k | 0805 | RC0805FR-071KL | Yageo | 2 | Top | Yes
R2;R6;R9;R10;R11 | 10k | 0805 | ERJ6ENF1002V | Panasonic | 5 | Top | Yes
R3 | 24k 1% | 0805 | RC0805FR-0724KL | Yageo | 1 | Top | Yes
R4 | 22k 1% | 0805 | ERJ6ENF2202V | Panasonic | 1 | Top | Yes
R5;R7;Rpd1;Rpd2;Rpd3;Rpd4 | 100k 1% | 0805 | ERJP06F1003V | Panasonic | 6 | Top | Yes
R8 | 33k | 0805 | RC0805JR-0733KL | Yageo | 1 | Top | Yes
R13;R14;R15;R16;R17 | 4.7k | 0805 | ERJ6ENF4701V | Panasonic | 5 | Top | Yes
Rg1;Rg2;Rg3;Rg4 | 100R | 0805 | RT0805BRD07100RL | Yageo | 4 | Top | Yes |  | gate resistor
SW1;SW2 | Tactile switch 6x6 | 6x6 SMD | B3FS1010P | Omron | 2 | Top | Yes
TP1;TP2;TP3;TP4 | Test point (bare pad) | THT pad |  |  | 4 | Top | DNP |  | DO NOT POPULATE
U1 | ESP32-C6-WROOM-1-N16 | WROOM module | ESP32-C6-WROOM-1-N16 | Espressif | 1 | Top | Yes |  | customer can supply (have 5); pin1
U2 | TPS54202 buck | SOT-23-6 | TPS54202DDCR | TI | 1 | Top | Yes |  | orient pin1
U3 | CH224K PD trigger | SSOP-10 w/ EP | CH224K | WCH | 1 | Top | Yes |  | thermal pad EP; pin1
U4 | USBLC6-2SC6 ESD | SOT-23-6 | USBLC6-2SC6 | ST | 1 | Top | Yes |  | orient pin1

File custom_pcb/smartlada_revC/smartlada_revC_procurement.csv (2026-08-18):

Ref | FormFactor | Value | Footprint | Qty_1bd | Qty_5bd_margin | Tolerance | Platan | Note
Rg1-Rg4 | 0805 | 100R | R_0805_2012Metric_HandSolder | 4 | 30 | 1% | 2017101911 | gate resistors (RT0805BRD07100RL)
R1;R12 | 0805 | 1k | R_0805_2012Metric_HandSolder | 2 | 20 | 5% | 2014969775 | R1=CH224 VDD / R12=3V3 LED
R13-R17 | 0805 | 4k7 | R_0805_2012Metric_HandSolder | 5 | 30 | 5% | 2011352451 | LED indicator series
R2;R6;R9;R10;R11 | 0805 | 10k | R_0805_2012Metric_HandSolder | 5 | 30 | 1% | 2017347591 | pull-ups (ERJ6ENF1002V 1%)
R4 | 0805 | 22k | R_0805_2012Metric_HandSolder | 1 | 15 | 5% | 2014983933 | buck FB bottom - part is 5% (RC0805JR); consider 1% for tighter Vout
R3 | 0805 | 24k | R_0805_2012Metric_HandSolder | 1 | 15 | 1% | 2014969370 | CH224 CFG1 (PD 12V select) - verify 1%
R8 | 0805 | 33k | R_0805_2012Metric_HandSolder | 1 | 15 | 1% | 2014967654 | VBUS-sense bottom
R5;R7;Rpd1-Rpd4 | 0805 | 100k | R_0805_2012Metric_HandSolder | 6 | 40 | 1% | 2011428029 | R5/R7 dividers 1% + Rpd pulldown (ERJP06F1003V 1%)
C2;C5;C9 | 0805 | 100nF | C_0805_2012Metric_HandSolder | 3 | 30 | 10% | 2014826976 | X7R decoupling >=16V (TCC0603X7R104K250CT)
C1;C10 | 0805 | 1uF | C_0805_2012Metric_HandSolder | 2 | 20 | 10% | 579760124 | X7R >=16V (TCC0603X7R105K250CT)
C3;C4 | 1210 | 10uF | C_1210_3225Metric_HandSolder | 2 | 20 | 10% | 2014974049 | X7R BUCK INPUT 12V -> 50V part OK (GRM32ER71H106KA12L)
C6;C7;C8 | 1210 | 22uF | C_1210_3225Metric_HandSolder | 3 | 30 | 10-20% | 2015696919 | X5R 3V3 out 25V (GRT21BR61E226ME13L)
C11 | e-cap 10x10.5 | 470uF | CP_Elec_10x10.5 | 1 | 8 | 20% | 696157719 | 12V BULK >=25V low-ESR
D1-D6 | 0805 | LED red | LED_0805_2012Metric_HandSolder | 6 | 40 | - | Ali:LED0805red | red indicators (Ali not Platan)
Q1-Q4 | DPAK/TO252 | AOD4184A | TO252_AOS | 4 | 25 | - | 2010030452 | N-MOSFET low-side
U1 | module | ESP32-C6-WROOM-1-N16 | XCVR_ESP32-C6-WROOM-1-N16 | 1 | 5+2 | - | own | ALREADY HAVE 5 pcs; +2 spare
U2 | SOT-23-6 | TPS54202DDCR | SOT-23-6_Handsoldering | 1 | 7 | - | 2015708243 | buck 12->3.3V
U3 | SSOP-10-EP | CH224K | SSOP-10-1EP_ThermalVias | 1 | 7 | - | 2016569523 | PD 12V trigger
U4 | SOT-23-6 | USBLC6-2SC6 | SOT-23-6_Handsoldering | 1 | 7 | - | 2015971466 | USB ESD
L1 | 7x7 SMD | 10uH | IND_CDRH6D28NP-100NC_SUM | 1 | 7 | 20% | 2014962957 | Isat >=3A (CDRH6D28NP-100NC)
J1 | USB-C 16P THT | USB-C receptacle | USB_C_Receptacle_HRO_TYPE-C-31-M-12 | 1 | 7 | - | 2015452755 | found this session (schematic field said Ali)
J2;J3;J5;J6;J7 | Faston 6.3 THT | tab male | TE_1217754-1 | 5 | 30 | - | 2011346771 | OUT0-3 + common +12V; crimp female separate
J4 | header 1x08 2.54 horiz | - | PinHeader_1x08_P2.54mm_Horizontal | 1 | 5 | - | PBS-40 | cut from 1x40 strip; OLED cable BLS-8 Platan 10660
J8 | header 1x03 2.54 horiz | - | PinHeader_1x03_P2.54mm_Horizontal | 1 | 5 | - | PBS-40 | UART; same 1x40 strip
SW1;SW2 | 6x6 SMD btn | tactile | SW_SPST_Omron_B3FS-100xP | 2 | 12 | - | 2015452241 | found this session (pricey >=31); any 6x6 SMD equiv
TP1-TP4 | TP THT D2/1mm | testpoint | TestPoint_THTPad_D2.0mm_Drill1.0mm | 4 | 0 | - | - | not purchased - wire loop / bare pad

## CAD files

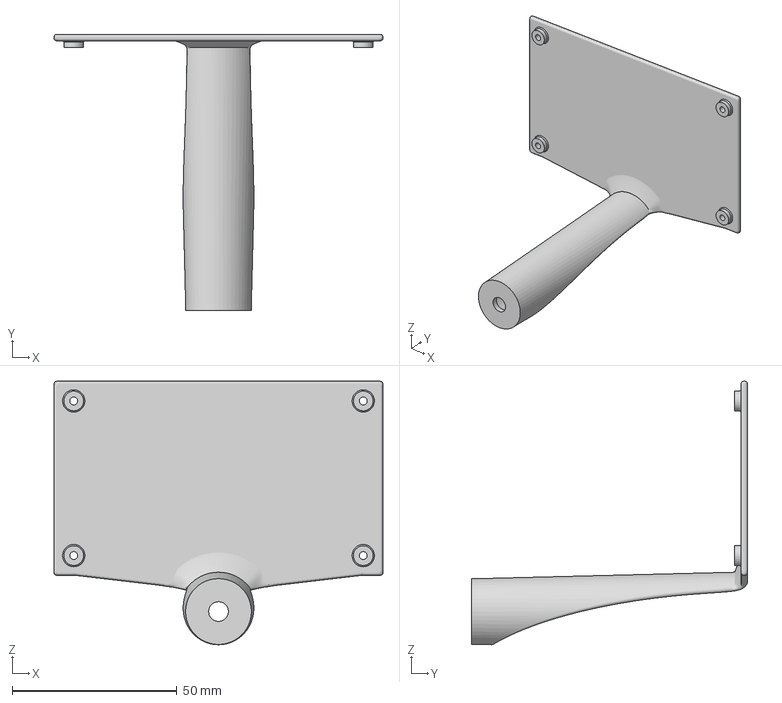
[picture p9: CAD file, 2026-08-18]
custom_pcb/smartlada_revC/3d print models/smartlada_revC.3mf
100.0 x 84.0 x 80.1 mm

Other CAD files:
custom_pcb/smartlada_revC/3d print models/smartlada_3d_revC.3mf
custom_pcb/smartlada_revC/mechanical/260812_smartlada_revC_3D.step

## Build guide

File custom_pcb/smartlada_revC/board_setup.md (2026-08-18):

# SmartLada Rev C — Board Setup (KiCad PCB Editor)

Значения под завод **pselectro (ЭЛЕКТРОконнект), техпроцесс «Стандарт», фольга 35 µm/1oz**
([pselectro_tech_limits.md](../pselectro_tech_limits.md)) и токи revC (шина 12 В до ~2.5 А).
Идём по вкладкам диалога **File → Board Setup**.

---

## 1. Board Stackup → Physical Stackup

Толщина платы **1.5 мм**, фольга внешняя **35 µm (1oz)**, финиш/маска — см. §2.

### Вариант 2 слоя (Саша пробует)
- F.Cu (сигнал+разводка) / B.Cu (**сплошная земля-полигон**, минимум разрезов).
- Земля льётся полигоном снизу; силовые +12В/каналы — сверху широкими дорожками.

### Вариант 4 слоя (рекомендую — RF+buck)
- **F.Cu** — сигнал/компоненты (35 µm)
- **In1.Cu** — **сплошной GND-план** (18 или 35 µm) ← опора под антенной и buck
- **In2.Cu** — питание (+12В/+3V3 полигоны) / доп. сигнал (18 или 35 µm)
- **B.Cu** — сигнал (35 µm)
- Диэлектрик FR4, итог 1.5 мм (завод раскидает препрег/кор).

**Импеданс-контроль НЕ заказываем** (±10% опция, не нужна: USB Full-Speed прощает).

---

## 2. Board Stackup → Board Finish
- **Толщина платы:** 1.5 мм.
- **Финиш:** **HASL (ПОС-63)** — работает от 1 мм, дёшево, дружелюбно к ручной пайке 0805.
  (ENIG опционально — площе под USB-C/ESSOP-10, но дороже; для нас HASL достаточно.)
- **Маска:** чёрная (LPI). **Solder mask tenting = FRONT + BACK = yes** — у нас via 0.3, а
  цветную маску завод просит закрывать на via ⌀≤0.4.
- **Шелкография:** белая.

---

## 3. Text & Graphics Defaults (шелкография)
- **Silkscreen line width (default):** **0.15 мм** (min завода).
- **Text height:** **1.0 мм** (min символ), **thickness 0.15 мм**.
- Подписи (CH1..4 с мощностью, полярность LED, USB-порт, TP) — не мельче 1.0 мм.
- Silk→pad зазор держим ≥ **0.2 мм** (клип маркировки включён).

---

## 4. Design Rules → Constraints (минимумы DRC)
| Параметр | Значение | Основание (pselectro) |
|---|---|---|
| Minimum clearance | **0.20 мм** | зазор 0.175 + полигон→пад 0.2 → берём 0.2 |
| Minimum track width | **0.175 мм** | топология 35 µm (по классам шире) |
| Minimum annular width | **0.20 мм** | поясок C (35 µm) |
| Minimum via diameter | **0.70 мм** | 0.3 сверло + 2×0.2 поясок |
| Minimum through hole (drill) | **0.30 мм** | PTH B |
| Hole to hole clearance | **0.25 мм** | Z=0.2 + допуск |
| **Copper to edge clearance** | **0.50 мм** | скрайб, 1.5 мм (I/U) |
| Silk to solder mask / pad | **0.20 мм** | X |
| Min solder mask sliver | 0.15 мм | R |
| Min text height | 1.0 мм | W |

Aspect ratio: сверло 0.3 при 1.5 мм = 1:5 (норма, предел 1:7). Ок.

---

## 5. Design Rules → Pre-defined Sizes
**Track widths (мм):** 0.25 · 0.5 · 0.6 · 1.0 · **1.5**
**Vias (диаметр/сверло, мм):** **0.7/0.3** (сигнал) · **0.8/0.4** (силовой)

---

## 6. Design Rules → Net Classes

| Класс | Track | Clearance | Via | Нетты |
|---|---:|---:|---|---|
| **Default** | 0.25 | 0.20 | 0.7/0.3 | всё остальное: CC1/CC2, I2C_SCL/SDA, KEY1-4, CH0..3_IN, CH224_PG, VBUS-sense, UART_TX/RX, EN-цепи |
| **USB** | 0.25 | 0.20 | 0.7/0.3 | USB_D+, USB_D- (вести **парой**, коротко, над сплошной землёй; ~90 Ом целимся, но не контролируем) |
| **+3V3** | 0.5 | 0.20 | 0.8/0.4 | +3V3 |
| **PWR_12V** | **1.5** | 0.25 | 0.8/0.4 (несколько) | **+12V** (он же LAMP_COM, ~2.5 А) |
| **LAMP_CH** | 0.6 | 0.20 | 0.8/0.4 | LAMP0, LAMP1, LAMP2, LAMP3 (~0.83 А/канал) |
| **GND** | 1.0 | 0.20 | 0.8/0.4 | GND, PGND — на 4 слоя это план; на 2 слоя сплошной полигон снизу |

Расчёт (IPC-2221, внешний слой, 1oz, ΔT≈10 °C): 2.5 А → ~1.0 мм min; берём **1.5 мм** с запасом.
0.83 А → ~0.25 мм min; берём **0.6 мм**.

---

## 7. Solder Mask / Paste
- **Solder mask clearance:** 0.05 мм (площадка→край маски Q, Стандарт).
- **Solder mask min web:** 0.15 мм.
- **Tenting vias:** ON (front+back) — см. §2.
- Paste — по умолчанию (ручная пайка/паста по вкусу).

---

## 8. Механика (Edge.Cuts + крепёж) — не в диалоге, но задать сразу
- **Контур платы:** прямоугольник **100 × 59 мм** (X × Y). Контур **скрайбом** (медь→край 0.5 мм).
- **4× крепёжных отверстия M3:** **Ø3.2 мм**, прямоугольник **88 (X) × 47 (Y)**,
  центрирован, отступ 6 мм до края. NPTH (без металлизации), keep-out под шайбу M3 (~Ø6-7).
- **Зазор платы над пластиной — 2 мм** (back-side пропай THT/via помещается).
- **RF keepout под антенной WROOM-1** — по даташиту модуля: **нет меди/дорожек/полигонов
  на ВСЕХ слоях** под областью антенны; антенну — к краю платы.

---

## Заметки по разводке (не Board Setup, но держать в голове)
- **Buck (U2):** петля VIN→SW→L→Cout короткая; **узел SW компактный** (не разливать — EMI);
  тепловые via под теплопадом если есть; входные C3/C4 вплотную к VIN.
- **CH224K, USBLC6, C_bulk** — у разъёма J1.
- **DPAK Q1-4 и CH224K** — тепловые via под падами (пад = сток/GND).
- **12В и GND-return** — широкие и короткие; общий +12В (Faston COM) разведён на все 4 канала.
- **Faston-табы** — по краю платы, удобно для проводов к лампам.

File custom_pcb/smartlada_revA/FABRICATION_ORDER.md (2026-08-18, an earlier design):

# SmartLada Rev A -- fabrication order preparation

How to turn the finished KiCad project into a manufacturable data package and place the
order. Companion to [KICAD_WORKFLOW.md](KICAD_WORKFLOW.md) (process/state) and
[smartlada_rev_a_bom_netlist.md](smartlada_rev_a_bom_netlist.md) (electrical spec).

**Status (2026-07-21):** board fully routed, DRC 0/0/0 after the J2 change to 2.54 mm.
Parts are being ordered. This document is the gate between "routing done" and "gerbers
sent".

Requirements below are distilled from three Russian fab houses whose limits and order
process are representative: PCBtech, PSElectro (ELEKTROconnect blank) and Rezonit. Any
of them can build this board; the data package is the same for all three.

---

## 1. Board summary (what the fab must build)

| Parameter | Value |
|---|---|
| Outline | 80 x 65 mm, rectangular |
| Layers | 2 (F.Cu, B.Cu) |
| Base material | FR4 |
| Board thickness | 1.5 mm |
| Copper weight | 35 um (1 oz), both sides |
| Solder mask | black, both sides (as ordered 2026-07-21) |
| Silkscreen | white, top only (bottom is a bare GND pour) |
| Surface finish | HASL (lead-free acceptable); ENIG optional, not required |
| Min track | 0.20 mm |
| Min clearance | 0.20 mm |
| Min copper-to-edge | 0.50 mm |
| Smallest finished hole | 0.40 mm (vias) |
| Distinct drill diameters | 8 |
| Plated (PTH) holes | 0.4, 0.5, 0.8, 1.0, 1.1, 1.3 mm |
| Non-plated (NPTH) holes | 2.7 mm (F1 fixator), 3.2 mm x4 (M3 mounting) |
| Electrical test | yes (recommended) |
| Panelization | none -- single boards (80 x 65 > 25 x 25) |
| Quantity | match parts on order (fab minimum is typically 5) |

The NPTH split matters: the four M3 holes and F1's 2.7 mm center hole must be
**non-metallized**. KiCad marks them NPTH automatically; keep PTH and NPTH drill files
separate so the fab cannot plate them by mistake.

---

## 2. Design rules vs fab capability -- the board is inside standard limits

Nothing here needs a special process or carries a surcharge. Verified against the three
vendors' published limits.

| Rule | This board | Rezonit std 2-layer | PSElectro | Verdict |
|---|---|---|---|---|
| Min track | 0.20 mm | 0.125 mm | 0.20 mm min polygon line | OK |
| Min clearance | 0.20 mm | 0.125 mm | -- | OK |
| Min finished hole | 0.40 mm | ~0.21 mm (1:7 of 1.5 mm) | 0.3/0.4 in standard list | OK |
| Min via annular ring | 0.20 mm (POWER 0.8/0.4), 0.15 mm (Default 0.6/0.3) | 0.15 mm | pad rim >= 0.25 mm for auto-metallization | OK, but see note |
| Copper-to-edge | 0.50 mm | -- | 0.30 mm (mill) / 0.50 mm (scoring) | OK for either edge method |
| Board coordinates | <= 80 mm | -- | <= 1430 mm | OK |
| Drill types | 8 | -- | <= 9 recommended, >12 surcharge | OK, no surcharge |
| Board size | 80 x 65 mm | large-format available | -- | OK |

**Class of accuracy:** min feature 0.20/0.20 mm sits at Russian class 3-4. Order as
class 4; class 3 is also sufficient. Do not pay for class 5.

**Annular-ring note:** Default-class vias are 0.6 mm pad on 0.3 mm drill -> 0.15 mm
annular, right at Rezonit's standard floor and below PSElectro's 0.25 mm rim for
*automatic* metallization decisions. All 8 vias on this board are GND and POWER-class
(0.8/0.4 -> 0.20 mm), so this is comfortable in practice; just confirm the drill/hole
convention in the order form (section 5) so plating compensation is applied to the drill,
not the finished size.

---

## 3. Generate the fab outputs in KiCad

`File > Fabrication Outputs`. Two data sets: Gerbers and drill files.

### 3.1 Gerbers (`... > Gerbers (.gbr)`)

Plot exactly these layers:

- **F.Cu, B.Cu** -- copper
- **F.Mask, B.Mask** -- solder mask
- **F.Silkscreen** (B.Silkscreen is empty but plot it too; an empty gerber is fine)
- **Edge.Cuts** -- board outline

Do **not** send: F.Fab/B.Fab, User.* (documentation only), Courtyard, F.Paste/B.Paste
(paste is stencil-only; this board is hand-soldered, no stencil needed).

Plot options for Russian fab CAM:

- Format: **Gerber**, Units: **mm**
- Coordinate format: **4.6**
- **Uncheck** "Use extended X2 format" and "Include netlist attributes" -- older CAM
  reads plain RS-274X more reliably (PSElectro asks for RS-274X specifically)
- **Uncheck** "Plot border and title block"
- **Check** "Subtract soldermask from silkscreen" (keeps silk off pads -- PSElectro:
  silk on bare copper will not print)
- Mirror: **off**
- Drill marks: **none** (drills come from the Excellon file, not the copper gerber)
- "Use drill/place file origin" (aux origin) so gerbers and drill share an origin

### 3.2 Drill files (`... > Drill Files (.drl)`)

- Format: **Excellon**
- **Uncheck** "Merge PTH and NPTH into one file"  -- keep them separate so the 2.7 mm
  and 3.2 mm holes are unambiguously non-plated
- Units: **mm**, decimal format
- Drill origin: **same aux origin** as the gerbers
- Also generate the **drill map** (PDF or gerber) for the fab to sanity-check the pattern
- Optionally "Generate map file" + the drill report -- the report lists the 8 diameters
  and PTH/NPTH counts; keep it in the package

### 3.3 Package

Zip the whole set (gerbers + PTH.drl + NPTH.drl + drill map + report) under one name,
e.g. `smartlada_revA_gerbers_v1.zip`. Include this file's section 5 as the board
description / order form. KiCad's default file names carry the layer in the extension,
which every fab CAM recognizes; no renaming needed.

---

## 4. Verify the gerbers before uploading

Open the generated set in an **external** viewer (KiCad's own GerbView counts, but a
fresh open catches export mistakes the PCB editor hides). Check, in order:

- [ ] **Edge.Cuts** present and forms one closed rectangle -- no gap, no stray segment
- [ ] **Four M3 holes** and **F1's 2.7 mm hole** appear in the **NPTH** drill, not PTH
- [ ] All **8 GND vias** present on both copper layers
- [ ] **GND pour on B.Cu** is one continuous island, not fragmented by the export
- [ ] **Silkscreen** legible, not clipped by pads, sits over mask (not on bare copper)
- [ ] **Mask openings** on every pad; no pad left mask-covered
- [ ] No layer missing and no extra layer (paste must be absent)
- [ ] Drill count/types match the report: 8 diameters, PTH 0.4-1.3 mm, NPTH 2.7/3.2 mm

Only after this passes: upload.

---

## 5. Order form values

These fill any of the three vendors' forms. Field order follows the ELEKTROconnect
"Zayavka" blank v21.01 (`BOM_work/revA/electroconnect_blank_zakaza.xls`); PCBtech accepts
the same set as a free-form description; PSElectro reads it off the gerbers plus this
sheet.

| Field | Value |
|---|---|
| Board file name | smartlada_revA |
| Order type | new |
| Quantity | (set to match the parts run; fab min ~5) |
| Delivery format | single boards (no array) |
| Exact board size (mm) | 80 x 65 |
| Layer count | 2 |
| Base material | FR4 |
| Board thickness (mm) | 1.5 |
| Copper foil (um) | 35 (1 oz) |
| Solder mask | yes, both sides |
| Solder mask color | black |
| Marking (silkscreen) | white, top side only |
| Surface finish | HASL lead-free (or leaded HASL; ENIG not required) |
| Edge-connector plating | none |
| Electrical test | yes |
| Contour method | milling (routing); scoring also fine, both edge clearances met |
| Drill file diameter is | finished (after plating) -- confirm with vendor; apply plating allowance to drill, not to the finished hole |
| Input format (CAD) | Gerber RS-274X + Excellon |
| Outline layer name | Edge.Cuts |
| Internal-layer order (MLB) | n/a (2 layers) |
| Cutouts / windows | none (only round holes) |
| Vias | tented/covered by mask is fine; all vias are GND/POWER |
| Assembly | no -- bare board only |
| Delivery | (fill per vendor) |
| Other requirements | 4x M3 (3.2 mm) and F1 2.7 mm holes are NON-PLATED |

---

## 6. Vendor notes and how to submit

**PCBtech** ([order procedure](https://www.pcbtech.ru/poryadok-oformleniya-zakaza)).
Accepts Gerber RS-274X (and legacy formats with a surcharge). Order = order form (or
free-form description) + PCB files + any supporting docs. Must state thickness, finish,
mask color, layer count, material. Submit to **pcb@pcbtec.ru**, via the online form, or
in person; include purpose, contact, and requestor. Processing starts after payment.

**PSElectro / ELEKTROconnect**
([project requirements](https://pselectro.ru/zakaz-pechatnyh-plat/trebovania-k-proektu-pecatnoj-platy-40626/)).
Gerber **RS-274X**, coordinates <= 1430 mm; drill in **Excellon**. Outline in a dedicated
layer as continuous, non-self-intersecting lines/arcs (edge = line centerline). Vector
polygons only, min line 0.2 mm -- no raster fills. Mask: green negative, 0.1 mm
pad-to-mask gap, 100 um min mask bridge. Silk: min line 0.15 mm, text >= 1.3 mm, stroke
font (GOST type B), >= 0.3 mm from edges/slots, nothing on bare pads. Copper-to-edge
0.3 mm (milled) / 0.5 mm (scored). Keep drill types <= 9 (>12 surcharges). Fill the
`electroconnect_blank_zakaza.xls` blank and attach it.

**Rezonit** ([single/double-sided](https://www.rezonit.ru/pcb/odnostoronnie-i-dvustoronnie/),
[tech capabilities](https://www.rezonit.ru/directory/tekhnologicheskie-osobennosti-proizvodstva/)).
Standard 2-layer process reaches 0.125/0.125 mm track/gap, 0.15 mm via annular ring, and
hole:thickness down to 1:7 -- this board (0.20/0.20, 0.40 mm holes) is well inside
standard, no special-process fee. Multiple mask/silk colors available if wanted; green
is cheapest. Upload gerbers + drill through their site quote.

---

## 7. Decide before ordering

Choices the fab form forces that the design does not fix:

- **Surface finish.** HASL is cheapest and fine here -- no fine-pitch/BGA parts; the
  DPAK and SOT-23-6 solder fine on HASL. Pick ENIG only if flatness or shelf life matters.
- **Copper weight.** Design basis is 1 oz: POWER traces are 1.5 mm, ~11 C rise at 3.33 A
  (KICAD_WORKFLOW section 5). 2 oz would lower that but is not needed and slightly
  stresses the 0.2 mm etch; **stay at 1 oz.**
- **Mask/silk color.** Green/white unless there is a reason otherwise.
- **Quantity.** Match the parts run. Note the fab minimum (~5).

Then run the section 4 checklist and submit.

---

## 8. Still open (from KICAD_WORKFLOW section 6, carried here)

- [ ] Confirm the drill-diameter convention with the chosen fab (finished vs tooling).
- [ ] Silkscreen text height: KiCad default 1.0 mm meets most fabs; PSElectro prefers
      >= 1.3 mm for readability. Spot-check the smallest reference designators; enlarge
      if any fall below 1.0 mm.
- [ ] Devboard pin order still unconfirmed -- a wiring issue at bring-up, not a board
      issue; does not block fabrication (J3 is flying-lead).

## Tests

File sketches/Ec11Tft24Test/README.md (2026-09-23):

# Модуль 2.4" TFT (ST7789) + EC11 — рабочие заметки

Стендовый тест отдельного модуля: **2.4" SPI-дисплей ST7789 240x320** со встроенным
энкодером **EC11 (A/B/PUSH)** и отдельной кнопкой **K0**. Не связан с проектом
smartlada — самостоятельный скетч.

Проверено вживую на **ESP32-C6 dev-board** (навесной монтаж, питание 3V3),
2026-07-28. Всё работает. Скетч: [`Ec11Tft24Test.ino`](Ec11Tft24Test.ino).

---

## 1. Что за модуль (по схеме продавца)

| Узел | Факт | Следствие для кода |
|---|---|---|
| Дисплей | ST7789, 240x320, **4-wire SPI, только запись** (MISO нет) | ID/регистры не читаются, offset/поворот подбираются вручную |
| `SDA/SCL` | Это **SPI** (SDA=MOSI, SCL=SCLK), НЕ I2C | не путать с I2C-шиной OLED |
| Энкодер A/B | 100R последоват., **10K подтяжка к VCC, 100nF на GND** (RC ~1 мс) | дебаунс уже на плате; `INPUT`, active-low, idle HIGH |
| PUSH | вал энкодера: R6 10K + C2 100nF, active-low | `INPUT`, доп. кондёров не надо |
| K0 (SW2) | R7 **10K подтяжка** + C3 100nF, кнопка на GND | подтяжка ЕСТЬ; `INPUT`, active-low |
| BLK (подсветка) | `BLK` -> 1K -> база **SS8050** (NPN), R3 10K вниз, low-side ключ | **active-HIGH**; плавающий/LOW = экран тёмный; PWM через LEDC работает |
| Питание | VCC 3.3/5V, логика 3.3 = VDDIO модуля | питаем от **3V3** |

> RC-дебаунс энкодера (~1 мс) впаян на модуле — выпаивать нечего. Он же не мешает
> быстрому кручению рукой (~10 об/с = ~5 мс/детент). Доп. конденсаторы A/B не нужны.

---

## 2. Распиновка (навесной монтаж на голый C6)

Обходим strapping (IO8/9/15), USB (IO12/13), BOOT. Если паять на эти пины — код
заработает без правок.

| Модуль | GPIO C6 | Роль |
|---|---|---|
| SCL (SCLK) | IO6 | SPI clock |
| SDA (MOSI) | IO7 | SPI data |
| CS | IO10 | chip select |
| DC (A0) | IO11 | data/command |
| RES | IO18 | reset |
| BLK | IO19 | подсветка, LEDC PWM, active-HIGH |
| A | IO2 | энкодер фаза A (PCNT) |
| B | IO3 | энкодер фаза B (PCNT) |
| PUSH | IO4 | кнопка вала, active-low |
| K0 | IO5 | отдельная кнопка, active-low |
| VCC | 3V3 | |
| GND | GND | |

Пины меняются в `#define` в начале `.ino`. SPI и PCNT на C6 роутятся через
GPIO-матрицу — пины можно любые (не только «дефолтные»).

---

## 3. Библиотеки

| Либа | Версия | Зачем |
|---|---|---|
| **GFX Library for Arduino** (moononournation) | 1.6.6 | дисплей: нативный C6, ест GFX-шрифты (совместимо с `bdf2gfx`) |
| **ESP32Encoder** (madhephaestus) | 0.12.0 | энкодер через аппаратный PCNT (новый IDF-драйвер, C6 ок) |

```bash
arduino-cli lib install "GFX Library for Arduino"
arduino-cli lib install "ESP32Encoder"
```

Почему не `TFT_eSPI`: на C6 (RISC-V) поддержка хрупкая, конфиг через `User_Setup.h`,
свой формат шрифтов. Arduino_GFX — надёжнее и совместим по шрифтам.

---

## 4. Инициализация (ключевые куски)

Дисплей — контроллер **настоящий ST7789**, цвета верные при **`ips=false`**
(INVOFF), поворот 1 (landscape 320x240), offset 0:

```cpp
Arduino_DataBus *bus = new Arduino_ESP32SPI(DC, CS, SCLK, MOSI, GFX_NOT_DEFINED);
Arduino_GFX *gfx = new Arduino_ST7789(bus, RES, /*rot*/1, /*ips*/false, 240, 320);
gfx->begin(40000000);   // 40 MHz стабильно на макетке
```

> Если бы попалась панель ILI9341 (частая подмена на 2.4"/240x320) — картинка была бы
> «каша»/со сдвигом. Тогда: `new Arduino_ILI9341(bus, RES, 1, false)`. Здесь — ST7789.

Энкодер — PCNT, full-quad даёт 4 отсчёта на детент (делим на 4). Внешние подтяжки
есть, внутренние не нужны. Порядок B,A задаёт направление (CW = increment):

```cpp
ESP32Encoder::useInternalWeakPullResistors = puType::none;
encoder.attachFullQuad(PIN_B, PIN_A);   // swap B<->A чтобы сменить направление
encoder.setFilter(1023);                // glitch-фильтр
long detents = encoder.getCount() / 4;
```

Подсветка — LEDC, active-HIGH; включать ДО первой отрисовки, иначе тёмный экран:

```cpp
ledcAttach(BLK, 20000, 8);   // 20 кГц, 8 бит
ledcWrite(BLK, 255);         // 0..255, диммирование без мерцания
```

---

## 5. Сборка и заливка

Собирать под **нативный USB-Serial-JTAG** (иначе Serial уходит в UART0):

```bash
arduino-cli compile --fqbn esp32:esp32:esp32c6:CDCOnBoot=cdc sketches/Ec11Tft24Test
arduino-cli upload  --fqbn esp32:esp32:esp32c6:CDCOnBoot=cdc -p /dev/cu.usbmodemXXXX sketches/Ec11Tft24Test
arduino-cli monitor -p /dev/cu.usbmodemXXXX -c baudrate=115200
```

Гочи (см. также bring-up RevB):
- По CDC загрузочные строки уходят до подключения монитора; `loop()` в простое молчит.
- `Serial.setTxTimeoutMs(0)` — чтобы `print` не блокировал `loop()`, если хост держит
  порт открытым, но не читает.

---

## 6. Результаты стенда (что реально намерено)

- **Контроллер ST7789** подтверждён: Border-тест — offset 0, обрезки нет.
- **Цвета** верные при `ips=false`.
- **Энкодер**: быстрое кручение без потерь шагов, реакция на дисплее мгновенная.
- **Подсветка**: диммирование LEDC 20 кГц — без мерцания на любой яркости.
- **Скорость SPI @ 40 МГц**:
  - полный кадр 240x320x16 (`fillScreen`): **~34 мс** (`fullFill=33825 us`)
    -> потолок **~29 fps** при полной перерисовке;
  - `fillRect 40x40`: ~720 us; лёгкий цикл (мелкий rect): ~690 loop/s.
- **TE-линии на разъёме НЕТ** -> vsync невозможен (как у OLED). Полноэкранная
  анимация даёт tearing + моргание.
- **Mura на белом** — от механического изгиба стекла на макетке; ушла после прогрева
  клеевого слоя (снялось напряжение). Панель не бракованная. **В корпусе не зажимать/
  не гнуть.**
- **80 МГц SPI** мерить только на плате с короткими дорожками; на dupont — артефакты
  по signal integrity, тест будет про провода, а не про панель.

---

## 7. Антифликер (важный вывод для будущего UI)

«Стереть `fillRect(BLACK)` -> нарисовать» без двойного буфера/TE виден как вспышка,
экран «рябит». Рабочие приёмы (применены в скетче):

1. **Текст поверх себя с непрозрачным фоном фиксированной ширины:**
   `gfx->setTextColor(fg, bg); gfx->printf("%6ld", v);` — новое затирает старое в тех
   же ячейках, без отдельной очистки -> без ряби.
2. **Обновлять только меняющуюся область** (dirty-rect), а не весь экран.
3. Для спрайтов/иконок — `drawBitmap(..., fg, bg)`: фон под нулевыми битами
   перекрывает предыдущий кадр без смаза.

Полноэкранных `fillScreen` в цикле анимации избегать.

---

## 8. Пиктограммы/анимация из `.h`

Формат `checkmark_ok_64_64_28f.h`: `frames[28][512]` в PROGMEM — **64x64 1bpp**,
MSB-first (стандартный формат `drawBitmap`), 512 байт/кадр = 64*64/8. (В файле есть
неиспользуемая `static int ..._frame` — можно игнорировать.)

Отрисовка кадра маской (зелёным на чёрном), без смаза:

```cpp
gfx->drawBitmap(x, y, checkmark_ok_64_64_28f_frames[i], 64, 64, GREEN, BLACK);
```

Проигрывание — в режиме `Anim OK` (`updateAnim()`): автопрокрутка 28 кадров, холд
на последнем, энкодер = скорость (10..200 мс/кадр).

**Конвертер** `tools/anim2h.py` (Pillow): GIF/APNG/папка-PNG -> .h.
- `--format 1bpp` (маска, `drawBitmap`, одноцветная иконка) или
  `--format rgb565` (цвет, `draw16bitRGBBitmap`, в разы больше flash).
- `--size 64 --frames 28 --threshold --alpha auto|on|off --invert --out ...`.
- Видео (mp4/mov) требует ffmpeg (нет в системе) — экспортируй в GIF.
Пример цветной анимации в скетче: режим `Earth` (`earth_64_64_24f.h`, RGB565 24f)
из примера GFX ezgif-resize; ~192 КБ flash на 64x64x24.

**Масштабирование** (drawBitmap не умеет): собрать RGB565-буфер NxN нужного размера
nearest-neighbor из битов и вывести одним трансфером — быстро и без ряби:

```cpp
gfx->draw16bitRGBBitmap(x, y, scaledBuf, SW, SH);
```

---

## 9. Режимы теста

`Info -> Colors -> Bars+Gradient -> Border -> Encoder -> Buttons -> Bench ->
Backlight -> Anim OK` (по кругу).

Навигация: **PUSH коротко = следующий, K0 коротко = предыдущий, K0 удержание =
сброс счётчиков.** Энкодер активен в `Encoder` (значение), `Backlight` (яркость),
`Anim OK` (скорость).

| Режим | Что проверяет |
|---|---|
| Info | распиновка, контроллер, подсказки |
| Colors | инверсия, битые пиксели, mura, RGB-порядок |
| Bars+Gradient | цветовые полосы, banding 16 бит |
| Border | offset/обрезка краёв (рамка 1px + уголки) |
| Encoder | PCNT: направление, потери шагов, детент/с, dirty-rect отклик |
| Buttons | PUSH и K0 раздельно, счётчики, long-press |
| Bench | время full/partial заливки, fps, tearing (движущийся квадрат) |
| Backlight | PWM-диммирование, минимум без мерцания |
| Anim OK | проигрывание 64x64 1bpp анимации из .h |

---

## 10. Итог / дальше

Модуль полностью пригоден. Библиотека и способ декодирования (Arduino_GFX + PCNT)
подтверждены железом. Для реального UI: dirty-rect обновления, полноэкранных
заливок избегать, при интеграции в плату замерить 80 МГц SPI на коротких дорожках.

## На плате revC (2026-09-24)

Модуль подключается к плате revC вместо OLED + 4 кнопок: прошивка `SmartLadaRevC`, сборка с
`-DUI_TFT=1`. Проводка, поведение и ограничения - [`SmartLadaRevC/README.md`](../../SmartLadaRevC/README.md),
раздел «Bench variant». Что выяснили на этом:

- **Панели нужны настоящие CS и RES.** На J4 шесть сигналов (SCLK, MOSI, DC + A/B/PUSH), поэтому
  CS и RES взяты с отладочного UART J8 (IO17/IO16). BLK и K0 не подключены: подсветка горит сама.
- `Arduino_ST7789` на ESP32 сам ставит `SPI_MODE3`, руками не нужно.
- Вариант CS->GND + RES->3V3 дал белый экран, но на плате с недопаянным U1 - окончательно не
  проверен. Хрупкий в любом случае: без CS один лишний фронт SCLK сдвигает поток до снятия питания.
- Стенды: [`../RevCTftEnc`](../RevCTftEnc/RevCTftEnc.ino) (панель + энкодер, проверка мягкого
  ресета) и [`../RevCTftDiag`](../RevCTftDiag/RevCTftDiag.ino) (цвета, дамп IO_MUX, сила выходов).

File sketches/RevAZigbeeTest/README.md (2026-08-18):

# RevAZigbeeTest — Zigbee bring-up на собранной плате RevA (ESP32-C6)

Цель этого теста — проверить, что модуль **присоединяется к Zigbee-координатору**
(Яндекс Станция Midi) как стандартная диммируемая лампа и что вкл/выкл + яркость из
приложения Дом с Алисой рулят четырьмя каналами ламп.

Wi-Fi/веб здесь намеренно отключены: у ESP32-C6 один 2.4 ГГц тракт на Wi-Fi и
802.15.4, поэтому первый заход — чистый Zigbee, лог по USB. Совмещение веб-интерфейса
и Zigbee (coexistence) — отдельный следующий шаг.

## Железо (из рабочей прошивки SmartLadaC6)

| Что | Пин | Примечание |
|-----|-----|---|
| Каналы ламп | GPIO0..3 | stop/reverse/turn/marker, low-side D4184, active-high PWM (больше duty = ярче). В тесте — один общий свет. |
| NeoPixel-статус | GPIO8 | onboard WS2812 |
| Кнопка BOOT | GPIO9 | active-low; удержание 3 c = factory reset + rejoin |
| USB | — | нативный USB-Serial-JTAG, лог 115200 |

Индикация NeoPixel: **синий мигает** — ищет сеть; **зелёный** — присоединился;
**белый мигает** — identify (Алиса «ищет устройство»); **красный** — идёт factory reset.

> [CRITICAL] С подключёнными лампами и 12 В: общая земля C6 ↔ БП, предохранитель на
> месте. Каналы принудительно OUTPUT+LOW до любой инициализации.

## Сборка и заливка

Модуль — ESP32-C6-WROOM-1-**N8** (8 МБ флеш), поэтому партишн `zigbee_8MB`.

Компиляция:

```bash
arduino-cli compile -b "esp32:esp32:esp32c6:ZigbeeMode=ed,PartitionScheme=zigbee_8MB,CDCOnBoot=cdc,FlashSize=8M" sketches/RevAZigbeeTest
```

Заливка (подставь свой порт из `arduino-cli board list`, обычно `/dev/cu.usbmodemXXXX`):

```bash
arduino-cli upload -b "esp32:esp32:esp32c6:ZigbeeMode=ed,PartitionScheme=zigbee_8MB,CDCOnBoot=cdc,FlashSize=8M" -p /dev/cu.usbmodemXXXX sketches/RevAZigbeeTest
```

Лог:

```bash
arduino-cli monitor -p /dev/cu.usbmodemXXXX -c baudrate=115200
```

В Arduino IDE эквивалент: Tools → Zigbee mode = **Zigbee ED (end device)**,
Partition Scheme = **Zigbee 8MB with spiffs**, USB CDC On Boot = **Enabled**.

## Порядок спаривания

1. Залить скетч, открыть монитор порта — увидеть `Joining network...`.
2. В приложении «Дом с Алисой»: добавить устройство → Умный дом → Зигби-устройство
   (открыть режим сопряжения на Midi).
3. NeoPixel сменит синее мигание на зелёный, в логе — `Joined Zigbee network`.
4. В приложении появится лампа: проверить вкл/выкл и ползунок яркости — каналы должны
   реагировать. Голос: «Алиса, включи <имя лампы>».

## Честные оговорки

- Zigbee-хаб Яндекса исторически придирчив к нестандартным устройствам. Стандартный
  профиль «диммируемая лампа» (On/Off + Level) имеет хорошие шансы, но результат
  эмпирический: может спариться как есть, может — только вкл/выкл, может не принять.
- Если диммер не принимается — откат на `ZigbeeLight` (чистый On/Off) тривиален.
- Если не присоединяется вовсе — снять лог с `DebugLevel=verbose` и режимом
  `ZigbeeMode=ed_debug` для диагностики стека.

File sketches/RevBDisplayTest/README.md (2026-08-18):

# RevBDisplayTest

Bring-up-тест платы **SmartLada Rev B**: проверка OLED-модуля и 4 кнопок
(разъём `J4` "OLED AND BUTTONS"). Пины взяты как **уже разведено на плате**
(сверено по нетлисту `custom_pcb/smartlada_revB`).

## Подключение

| Модуль | Сигнал | ESP32-C6 |
|---|---|---|
| GND | GND | GND |
| VCC | +3V3 | 3V3 |
| SCL | I2C SCL| GPIO18 |
| SDA | I2C SDA| GPIO19 |
| K4 (*) | KEY4 | GPIO23 |
| K3 (#) | KEY3 | GPIO22 |
| K2 (v) | KEY2 | GPIO21 |
| K1 (^) | KEY1 | GPIO20 |

Кнопки замкнуты на GND -> `INPUT_PULLUP`, нажатие = LOW.
Дисплей: WEO012864V, контроллер SSD1315 (совместим с SSD1306), I2C `0x3C`.

## Что делает

- На OLED — по строке на кнопку: метка, символ и живой счётчик нажатий;
  удерживаемая кнопка подсвечивается (инверсия). В шапке — heartbeat 0..9
  (доказывает, что цикл обновления не завис).
- Каждое нажатие дублируется в Serial @115200.
- Если OLED не найден — тест продолжает опрашивать кнопки и пишет в Serial,
  чтобы можно было проверить разводку кнопок отдельно.

## Сборка/заливка

```
arduino-cli compile --fqbn esp32:esp32:esp32c6:CDCOnBoot=cdc sketches/RevBDisplayTest
arduino-cli upload  --fqbn esp32:esp32:esp32c6:CDCOnBoot=cdc -p <PORT> sketches/RevBDisplayTest
```

Библиотеки: `Adafruit SSD1306`, `Adafruit GFX`.

Важно: `CDCOnBoot=cdc` нужен, чтобы вывод `Serial` шёл в нативный USB-порт
(usbmodem). Без него по умолчанию `Serial` уходит в аппаратный UART0, и в
USB-мониторе вывода скетча не видно (виден только лог ROM-бутлоадера).

Проверено на живой плате (dev-board C6 + провода): OLED отвечает на `0x3C`,
все 4 кнопки (K1..K4) отрабатывают.

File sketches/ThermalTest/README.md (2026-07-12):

# ThermalTest — DS18B20 validation bench (ESP8266 / HW-364A)

Standalone test sketch that validates **2× DS18B20** (PSU, BODY) on one 1-Wire
bus, plus the phone time-sync, the cineink-style event log and the dark web view —
before the thermal layer is ported into `SmartLadaC6`. It does **not** drive
lamps/PWM. (The ESP/die point comes from the C6 internal sensor on the target;
room temp ~22.5 °C is the ambient reference.)

Full spec: [docs/TZ_thermal_test.md](docs/TZ_thermal_test.md).

## Wiring

| Signal | Pin | Notes |
|---|-----|---|
| 1-Wire data | **GPIO13 (D7)** | one bus, both sensors |
| Pull-up | 4.7 kΩ | data → **3.3 V**, one for the whole bus |
| Sensor power | 3.3 V | normal (non-parasite), common ground |
| OLED | SDA=GPIO14, SCL=GPIO12, `0x3C` | onboard SSD1306 |
| Button | FLASH=GPIO0 | cycles OLED pages |

## Layers

```
ThermalTest.ino        thin: setup/loop + temperature-logging policy
src/thermal/           2x DS18B20, non-blocking 12-bit, ROM->point map
src/rtc/               wall clock seeded by the phone (/api/time)
src/log/               LittleFS event log (/log.txt, rotates 512 KB)
src/stats/             running min/max/avg + recent-sample ring (OLED pages 4-5)
src/display/           OLED: temps / status / ROMs / history / min-max-avg (5 pages)
src/web/               SoftAP + HTTP: UI, /api/state, /api/time, /log, /clearlog
```

## Build & flash

Libraries: `OneWire`, `DallasTemperature`, `Adafruit SSD1306` (+ Adafruit GFX).
Board: NodeMCU 1.0 (HW-364A compatible), flash layout with a filesystem for the log.

```sh
arduino-cli compile --fqbn esp8266:esp8266:nodemcuv2:eesz=4M2M ThermalTest.ino
arduino-cli upload  --fqbn esp8266:esp8266:nodemcuv2:eesz=4M2M -p <PORT> ThermalTest.ino
```

## Bring-up

1. On boot the serial log prints every ROM address on the bus (`dumpBus`). The two
   bench sensors are already pinned in `CONFIGURED[]` in `src/thermal/thermal.cpp`
   (psu / body — provisional; heat one point to confirm and swap if needed).
2. Connect to Wi-Fi AP **ThermalTest** (password `thermaltest`), open
   `http://192.168.4.1`. The page sets the device clock from your phone and shows
   the three live temperatures.
3. Logs: **DOWNLOAD LOG** / **LOG.BAK** / **CLEAR LOG** on the page. Sample policy:
   a control stamp every 60 s + a `Δ`-marked line whenever any sensor moves > 2 °C.

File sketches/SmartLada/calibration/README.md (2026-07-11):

# Bench calibration results

`2026-07-06_bench.json` — captured on real VAZ-2106 tail light lamps, tuned by eye.

## Run observations (2026-07-06)

- **Flicker:** the difference between 100 and 1000 Hz is invisible to the eye — the
  thermal inertia of the filaments smooths PWM completely. 100 Hz was chosen.
- **Glow threshold:** `min_duty` 50 (21 W) / 100 (5 W marker) — below that the filament
  visibly doesn't light. The thin marker filament needs a larger share of the scale.
- **Gamma:** 2.0 for the 21 W lamps, 2.2 for the 5 W marker.
- **Cap removed** (100%) deliberately after testing; the cap is not carried over to C6.
- **Tail-light wiring:** the common tail-light board is re-polarized to +12 (common
  positive), individual socket contacts → D4184 drains (separate switched terminals).
  Incandescent lamps don't care about polarity. The wiring is verified — channels are
  fully independent.

## On soft_start_ms = 30 (a deliberate decision)

The cold-filament inrush (~10× nominal for the first tens of ms) is dangerous not to the
lamp (automotive lamps are designed for cold starts — there is no soft-start in a car)
and not to the switch (the D4184 handles tens of amps), but to the switching PSU
(over-current protection tripping) and the fuse (false blows). The bench showed
empirically: the 100 W PSU digests a start with a 30 ms ramp without the cap — protection
does not trip. So 30 ms is validated by hardware; longer is not needed. Caveat: recheck
this if the PSU is swapped for a weaker/more nervous one.

## For porting to the ESP32-C6

- The `gamma` / `min_duty` / `max_duty` / `soft_start_ms` numbers — into the `channels`
  layer unchanged.
- `gpio` — a bench binding (ESP8266/HW-364A); on the C6 the pins will be different.
- `pwm_freq_hz: 100` — chosen for the ESP8266 softPWM; LEDC on the C6 is hardware, and
  the frequency is visually irrelevant (100–1000 Hz identical), so it can be raised for a
  quieter-singing PSU.

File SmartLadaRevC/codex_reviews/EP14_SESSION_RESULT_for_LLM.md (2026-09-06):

# EP14 / Yandex color feedback — session result

Date: 2026-09-06. Project: `SmartLadaRevC`. Firmware: `1.0.9-revC`.
This document supersedes `EP14_DEBUG_HANDOFF.md` for this incident. Older project notes
claiming EP14 reports H/S or calling report-back fully complete are outdated.

## Outcome

Implemented and flashed a small Yandex compatibility workaround: suppress automatic
Hue/Saturation reports on EP14 before incoming Color Control commands update attributes.
Keep received H/S unchanged; retain attribute reads, brightness/on-off reporting and EP10–13.
No color scaling, preset lookup table, fabricated values, core-library edits or re-pairing.
No commits; the working tree contains extensive pre-existing user changes. Preserve them.

This removes the demonstrated trigger. It does **not** establish the precise defect inside
the station, its adapter/backend or the phone app.

## Context and decisive evidence

EP14 uses color to select an effect, not physical RGB output. Saturation <40 means static;
otherwise hue selects an effect. Level controls brightness. Original symptom: after white,
the app jumped to red; white became an unnamed white. Effect selection itself worked.

Received raw H/S examples: white `162/25`, blue `158/243`, green `95/243`, red `0/243`.
Attribute values remained stable after settling and 2.3 seconds later.

| Experiment | Observed result |
|---|---|
| Inspect modes after commands | ColorMode and EnhancedColorMode both became 0; persistent mode mismatch was not the cause. |
| Explicit hue reports | Helped replace stale cached hue; did not preserve presets reliably. |
| Stop SDK H/S reports; send one combined H/S packet after settling | Stop API succeeded; no early report response remained. All six transmitted pairs exactly matched incoming bytes, with APS and ZCL success responses. Preset replacements persisted. |
| Disable both SDK H/S reports and explicit color reports | User confirmed no jumps through white → blue → white → green. |
| Send one unchanged green report | No jump. Station had already received the same pair earlier; duplicate filtering is plausible, not proven. |
| Select white without reports, then manually report unchanged `162/25` | White stayed selected until the report, then became unnamed. Packet: `08c10a000020a201002019`; APS success and ZCL success response. |
| Select white again without reports; reopen card; change brightness | User confirmed preset remained selected after both actions. |

The separate-packet ordering hypothesis failed: combined reports still caused the issue.
An extreme-red slider test received S=243, not 254, so it did not rule out conversion or
rounding upstream. Screenshots alone do not reveal numeric H/S. The user's other lamp is
Matter, not Zigbee; no independent Zigbee-lamp comparison was completed.

## Final implementation

- `src/net/zigbee.cpp`: `onApsIndication()` stops only configured SEND reports for EP14
  Color Control attributes 0/1. It always chains Arduino's existing
  `zb_apsde_data_indication_handler()` to preserve binding-list handling and normal processing.
  Installed after `Zigbee.begin()` under the SDK lock; callback itself already holds the lock.
- Same file: protect pending HSV snapshot with `portMUX_TYPE`; compare settling timestamps
  using signed subtraction. A callback timestamp newer than the loop's sampled time previously
  underflowed unsigned subtraction and bypassed the 150 ms wait. This was separately fixed.
- `.ino`: USB TX timeout remains zero, avoiding stalls when debug output is unread.
- `README.md`: compatibility behavior, evidence and limitations documented.
- Removed temporary `color_report.{h,cpp}` and `fara_diagnostics.{h,cpp}`. No manual P/R/H/Q/C
  protocol or experimental APS sender remains in the final firmware.

## Validation and stopping state

- Arduino-ESP32 **3.3.10**, ESP32-C6, USB `/dev/cu.usbmodem101`.
- Build and upload succeeded; flash hashes verified. Final build: 1,112,890 program bytes,
  40,432 global-data bytes. Boot log confirms workaround installed and firmware ready.
- C++ tests with ASan/UBSan passed against extracted final handler and HSV snapshot:
  reporting scope, malformed/unrelated traffic, original-handler chaining, error path,
  settling deadline and timer wrap. These do not simulate the entire Zigbee stack.
- Final cleaned firmware received blue → white and selected modes 4 → 0 correctly in logs.
  **User did not explicitly confirm the final cleaned build's UI smoke test before ending.**
  The no-jump/reopen/brightness confirmations above were on diagnostic v6 with the same
  report-suppression behavior.
- USB capture stopped. Device remains on final firmware. No further tests scheduled.

## Limits / avoid scope expansion

- Local button-selected effects do not update the app's color selector; this already matched
  the pre-investigation policy. Suppression trades color feedback for stable Yandex presets.
- Re-pairing, other controllers and future Arduino versions are untested. The chained Arduino
  hook is version-sensitive. This is a compatibility workaround, not full reporting compliance.
- Immediate `applyLevel()` still writes shared configuration from the Zigbee callback;
  broader state races, static-channel overwrite semantics and persistence were not fixed here.

## Evidence / reproducibility

Logs are alongside this file: `EP14_USB_paired_no_auto_v5_2026-09-06.log` (exact paired
reports still fail), `EP14_USB_quiet_v6_2026-09-06.log` (no-report and manual-white A/B),
`EP14_USB_final_2026-09-06.log` (final boot/commands). Earlier logs retain exploratory tests.

Temporary builds/tests/source backups: `/tmp/smartlada-ep14-debug/` (not durable).
Final build directory: `build-final`; debug-v6 source snapshot: `v6-sources`.
FQBN: `esp32:esp32:esp32c6:ZigbeeMode=ed,PartitionScheme=zigbee_8MB,CDCOnBoot=cdc,FlashSize=16M`.

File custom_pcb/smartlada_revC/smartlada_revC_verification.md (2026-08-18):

# SmartLada Rev C — Верификация перед фабом (2026-08-15)

Проверка по файлам `smartlada_revC.kicad_pcb` / `.kicad_sch` (нетлист kicad-cli).
Метод: разбор координатами + сверка со SVG-отрисовкой меди. Все пункты ниже — проверенные факты.

## Итог: плата электрически чистая, fab-ready.

## 1. DRC — чисто
- `footprint_symbol_field_mismatch` (поле `Platan`) переведён в **Ignore** в `.kicad_pro`
  (поле закупочное, живёт только на символах; BOM генерится из схемы).
- Итог headless DRC: **0 violations, 0 unconnected, 0 footprint errors** (было 66 Platan-warning).

## 2. Земля под USB D+/D- (задача handoff)
- Пара `/USB_D+ /USB_D-` (U4->U1) и `Net-(J1-D+/-)` (J1->U4) — **вся по F.Cu**, 30 сегментов,
  **0 переходов на другой слой** => опорная земля = единый сплошной B.Cu-полигон на всём пути.
- B.Cu GND-заливка x[142..229.5] y[71.5..129.5] **полностью накрывает** маршрут пары
  x[177..214] y[78..96].
- **Длинный участок** (U4->U1, x186..214 @ y~94..95): под ним на B.Cu только GND, ближайшая
  не-GND медь (+3V3-перемычка @y=84.7) в ~10 мм. Возврат тока не разрезан.
- GND-стежок-via вдоль пары: @(177.9,81.4)(178.5,91.6)(194.7,79.0) + кластер у U1 (208..209).
- **Заметка (не блокер):** у разъёма/U4 (x171..180, y81..92) по B.Cu идут CC1/CC2 близко к вееру
  D+/D- — локальный «щелевой» участок земли в launch-зоне. Для ESP32-C6 (native USB = **Full-Speed
  12 Мбит**) некритично.

## 3. Антенна WROOM (задача handoff)
- Плата 100x59, край x=230. Встроенный keepout U1 под антенной = x[230.51..236.51] — **целиком
  за краем платы**. B.Cu-заливка кончается на x=229.5. **Меди под антенной нет** (висит за краем).

## 4. Silk J8 UART (задача handoff — своп пинов 2/3)
- pad1 = silk `GND` = net `GND`; pad2 = silk `RX` = `/UART_RX`; pad3 = silk `TX` = `/UART_TX`.
- **Совпадает.** Своп разрешён. Маркировка board-side (silk `TX` = MCU TX).

## 5. Питание (сверка номиналов)
| Узел | Найдено | Проверка |
|---|---|---|
| CFG1 (U3.9) | R3 = **24k** ->GND | профиль PD **12В** ✓ |
| Buck FB (U2.4) | R5=100k(top)/R4=22k(bot), Vref 0.596 | Vout = **3.30В** ✓ |
| U4 (USBLC6) VBUS pin5 | **/+3V3** | не 12В — 5В-деталь жива ✓ |
| CH224 PG (U3.10) | R9=10k↑ на 3V3 -> IO10 | open-drain active-LOW ✓ |
| ESP EN (U1.3) | R6=10k↑ + C10=1µF + SW1 | RC-reset ✓ |
| Buck EN (U2.5) | не подключён (внутр. pull-up) | плавающий, наследие revB ✓ |
| CH224 DP/DM (4,5) | закорочены на `Net-(U3-DM)`, отвязаны от данных | чистый PD ✓ |
| VBUS-sense (U1.IO4) | R7=100k/R8=33k -> 12В=**2.98В** ADC | presence-sense ок; точность у верха ADC (заметка) |
| +12V rail | J1 VBUS x4 -> U2 + C11 470µF + Faston J7 (общий +12В) | ✓ |

## 6. Финальный pin-map U1 (снят из нетлиста — ground truth для прошивки)
Каналы ламп (low-side, gate active-HIGH):
```
OUT0 = GPIO1   (/CH0_IN -> Rg1 -> Q1 -> /OUT0)
OUT1 = GPIO0   (/CH1_IN -> Rg2 -> Q2 -> /OUT1)
OUT2 = GPIO2   (/CH2_IN -> Rg3 -> Q3 -> /OUT2)
OUT3 = GPIO3   (/CH3_IN -> Rg4 -> Q4 -> /OUT3)
```
> IO0/IO1 перекрещены (IO1->OUT0, IO0->OUT1); IO2/IO3 прямые. Своп CH2/CH3 уже разрешён.

Питание/сенсоры:
```
CH224_PG   = GPIO10   (open-drain, active-LOW, 10k pull-up 3V3)
VBUS_sense = GPIO4    (ADC, делитель 100k/33k, 12В->2.98В)
```
Native USB: `D- = GPIO12`, `D+ = GPIO13`.
Strapping: `BOOT = GPIO9` (SW2), `RESET = EN` (SW1).
I2C (OLED, J4): `SCL = GPIO18`, `SDA = GPIO19`.
Кнопки (J4): `KEY1=GPIO23  KEY2=GPIO22  KEY3=GPIO21  KEY4=GPIO20`.
UART debug (J8): `TX = GPIO16`, `RX = GPIO17`.
Индик. LED: D2..D5 на /OUT0..3 (пассивные), D1 на +3V3, D6 на GND.

## Открытые заметки (не блокеры)
- VBUS-делитель 100k/33k: 2.98В при 12В — presence-sense надёжно, но у верхней (нелинейной)
  зоны ADC ESP32-C6. При входе >~13.3В ADC-пин уйдёт >3.3В (защиты нет). CH224K держит 12В =>
  риск низкий. Если нужна точность/запас — сделать 100k/24k (12В->2.32В).
- CC1/CC2 щель под launch-зоной D+/D- — ок для FS.

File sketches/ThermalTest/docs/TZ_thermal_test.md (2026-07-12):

# TZ — ThermalTest: DS18B20 validation bench (ESP8266 / HW-364A)

Standalone test sketch that validates two DS18B20 sensors (PSU, BODY) and the
supporting plumbing (phone time-sync, event log, web view) **before** the thermal
layer is ported into `SmartLadaC6`. It does **not** drive lamps/PWM.

> A third DS18B20 for the ESP point was dropped: on the C6 target that reading
> comes from the internal die sensor, not a DS18B20. Room temperature (~22.5 °C
> measured on the bench) is taken as the **ambient reference**.

- **Board:** ESP8266 HW-364A (ESP-12F + onboard SSD1306 OLED + FLASH button).
- **Sketch path:** `sketches/ThermalTest/` (thin `.ino` + `src/*/{h,cpp}` layers,
  mirroring `sketches/SmartLada/`).
- **Design lineage:** OLED/button pattern from `sketches/SmartLada/src/display/`;
  time-sync + event log + dark web view ported from the `cineink` project
  (`firmware/cineink/{rtc,log,web}.cpp`, `web_view/device.css`).

> Language: all code, comments and docs in English (project convention).

---

## 1. Goal & scope

**In scope (v1):**
- Read 3× DS18B20 on one 1-Wire bus, non-blocking, 12-bit.
- Show live temperatures on the OLED (paged, FLASH button cycles pages).
- Serve a dark cineink-style web page with the 3 live values + wall clock.
- Sync wall clock from the phone browser on page load (`POST /api/time`).
- Persist a rolling event log on LittleFS (cineink mechanics) with temperature
  samples carrying real time; downloadable/clearable from the web.

**Out of scope (v1):** any control action (no PWM, no thermal derating), sensor
calibration, plotting. The C6 port replaces OLED with web + NeoPixel.

---

## 2. Hardware

| Node | Value | Notes |
|---|---|---|
| MCU | ESP8266 (HW-364A) | ESP-12F |
| OLED | SSD1306 128×64, I²C **SDA=GPIO14, SCL=GPIO12**, `0x3C` | verified pins, see SmartLada bench |
| Button | FLASH = **GPIO0** (LOW = pressed) | cycles OLED pages; 30 ms debounce |
| **1-Wire bus** | **GPIO13 (D7)** | non-strapping; broken out on the HW-364A header (used as a channel in the SmartLada bench) |
| Sensors | 2× DS18B20, 12-bit, normal (non-parasite) power | unique 64-bit ROM each |
| Pull-up | one **4.7 kΩ** DATA → 3.3 V for the whole bus | not one per sensor |
| Power | 3.3 V, common ground | |

**Mounting (sensor reads its own case → thermal contact matters):**
- **PSU** — thermal-glue/clamp to the DC-DC case near the hot spot.
- **BODY** — tail-light housing near the lamps.

Bench addresses (from `dumpBus`, provisional PSU/BODY assignment — heat one point
to confirm, swap the two lines in `CONFIGURED[]` if needed):
`psu = 28 1D 1B 74 00 00 00 A5`, `body = 28 DF 2D 6D 00 00 00 E7`.

---

## 3. Firmware layers

Thin `ThermalTest.ino` + these `src/` layers:

### 3.1 `src/thermal/{thermal.h, thermal.cpp}`
- Libraries: `OneWire` + `DallasTemperature`.
- 12-bit resolution; **non-blocking** state machine in `tick(now)`:
  `requestTemperatures()` (async, `setWaitForConversion(false)`) → wait ~750 ms
  → read. Live sample period **2 s**.
- Hard-coded ROM→label table (like `CHANNEL_DEFS`): index 0..2 → `psu/body/esp`.
- Fault handling: a reading outside the DS18B20 spec range (−55…125 °C) →
  **not present** (UI shows `—`). This covers `DEVICE_DISCONNECTED_C` (−127); the
  full 750 ms conversion wait rules out the false `85.0` power-on value.
- API:
  ```cpp
  namespace thermal {
    void  begin();                 // bus init, 12-bit, async mode
    void  tick(uint32_t now_ms);   // request → wait → read
    float celsius(uint8_t idx);    // NaN if !present
    bool  present(uint8_t idx);
    void  dumpBus(Print& out);     // list all found ROM addresses + temps
  }
  ```
- Bring-up: `dumpBus(Serial)` at boot prints found addresses so the ROM→label
  table can be populated. Acceptance expects **exactly 3** addresses, CRC ok.

### 3.2 `src/rtc/{rtc.h, rtc.cpp}` (port of cineink `rtc`)
- `setLocalEpoch(uint32_t)`, `isSet()`, `format(out,n,withDate)`.
- Stores the phone's **local** epoch via `settimeofday()`; `gmtime_r()` then
  yields local wall-clock. `isSet()` = clock ≥ 2021-01-01 (distinguishes
  "set by browser" from cold boot). Works on ESP8266 `time.h`.

### 3.3 `src/log/{log.h, log.cpp}` (port of cineink `log`, simplified)
- LittleFS `/log.txt`, rotates at **512 KB** → `/log.bak.txt` (one backup kept).
- **ESP8266 deltas vs cineink:** no FreeRTOS mutex (single core);
  `LittleFS.begin()` (no format-arg); no panic-breadcrumb subsystem.
- Macros `LOGI/LOGW/LOGE`.
- **Line format** (unified rule for the whole log): prefix is wall-clock
  `HH:MM:SS` when `rtc::isSet()`, else `<sec>s` (`millis()/1000`). Body keeps
  cineink's `<LEVEL> <TAG>: <msg>`. Session anchor `==== boot @ <ts> ====` and a
  one-shot `clock set <ts>` when the phone first sets the time.

### 3.4 Temperature logging policy
Live reading (2 s) is separate from what is persisted. A line is written when:
1. **Control stamp — every 60 s** (always, even if steady).
2. **Change trigger** — any sensor's current reading differs from its
   **last-logged** value by **> 2.0 °C** (up or down); the compared baseline for
   that sensor is then updated. Change-triggered lines use the tag `TEMP*` (ASCII
   only — no non-standard glyphs in the log).

Line examples (both values per line):
```
20:15:03 I TEMP: psu=47.2 body=39.1
20:15:31 I TEMP*: psu=49.4 body=39.3
20:16:03 I TEMP: psu=49.6 body=39.2
```
Before the phone sets the clock the prefix falls back to `<sec>s`.

### 3.5 `src/stats/{stats.h, stats.cpp}`
Fed from the main loop (reads the thermal layer directly). Keeps, per sensor,
running **min / max / avg** since boot (valid readings only) plus a short ring
buffer of recent samples (5 entries at 30 s) for the history page. Pure bookkeeping
— no display or storage dependency.

### 3.6 `src/display/{display.h, display.cpp}` (OLED)
FLASH button cycles **5 pages** (pattern from the SmartLada bench). This board is a
two-colour panel — **top 16 px yellow, rest blue** — so page content keeps the
yellow strip for the title/clock and all data rows sit at `y ≥ 16` (blue).
1. **Temps** — yellow strip: `THERMAL  HH:MM:SS`; blue: two big rows
   `PSU 47.2` / `BODY 39.1` (`--` for a missing sensor).
2. **Status** — IP, SSID, clients, free heap, log size, `clock: set/unset`.
3. **Sensors** — ROM address tails + present/CRC per sensor.
4. **History** — table of recent samples (age / psu / body), 30 s cadence,
   newest first; `collecting...` until the first entry.
5. **Min/Max/Avg** — per-sensor min/max/avg since boot + sample count and uptime.

### 3.7 `src/web/{web_server.h, web_server.cpp}`
SoftAP + HTTP. Endpoints:
| Method | Path | Purpose |
|---|---|---|
| GET | `/` | dark SPA (cineink style) |
| GET | `/api/state` | JSON: `{temp:[..], present:[..], time, clients, heap, logBytes}` |
| POST | `/api/time` | phone hands local epoch (`epoch=…`) |
| GET | `/log`, `/log.1` | download current / backup log (dated filename) |
| POST | `/clearlog` | wipe both log files (confirm-guarded) |

Web view: black bg, system font, uppercase letter-spaced labels, `.btn/.line/
.danger` buttons, `.ok/.warn/.err` colors, 440 px width (from
`cineink/web_view/device.css`). Live values poll `/api/state` every 2 s. On page
load the SPA fires the one-shot `POST /api/time` with
`epoch = Math.floor(Date.now()/1000) − new Date().getTimezoneOffset()*60`.

### 3.8 `ThermalTest.ino`
Thin: `Serial.begin`, `LittleFS`/`log::begin`, `rtc` implicit, `thermal::begin`,
`thermal::dumpBus(Serial)`, `stats::begin`, SoftAP + `web::begin`, `display::begin`.
In `loop()`: `web::handle()`, `thermal::tick(now)`, `stats::tick(now)`,
log-policy tick, `display::tick(now)`.

---

## 4. Acceptance

1. `arduino-cli compile` passes (build-before-upload rule). ✅
2. `dumpBus(Serial)` finds **both** addresses, CRC ok. ✅ (`28…A5`, `28…E7`)
3. Two plausible values on OLED **and** in `/api/state`; they diverge under
   local heating (finger/hot-air on one sensor).
4. Unplugging one sensor → `present=false`, UI/OLED `—`, firmware does not hang,
   the other keeps reading.
5. Phone loads the page → log shows `clock set <ts>`, boot header carries the
   date, downloaded file name is dated.
6. Log policy verified: 60 s control stamps present; a `Δ` line appears within
   one sample after a >2 °C swing; rotation at 512 KB works.
7. `loop()` never blocks (OLED refresh + web stay responsive during the 750 ms
   conversion window).

---

## 5. Risks

- Wrong ROM→point mapping → mitigated by `dumpBus` + labelling the pigtails.
- Poor thermal contact → low/lagging readings (esp. PSU/board points).
- Long/branched 1-Wire runs → keep normal power + correct pull-up, no star topology.
- `85.0` raw value mistaken for a real reading → explicitly filtered as not-present.

---

## 6. Port to SmartLadaC6 (after validation)

`thermal` + `rtc` + `log` layers and the `/api/time` `/log` `/clearlog`
endpoints port almost verbatim. On C6: bus on **GPIO10** (confirmed on the
nanoESP32-C6 header); **2×** external DS18B20 (PSU, BODY) + the **C6 internal
sensor** for the die (`temperatureRead()`), reported as `esp (die)`; the third
DS18B20 stays in spares. OLED/button are test-only and are replaced by the web
UI + NeoPixel indication. `/status` JSON gains `temp:[psu,body,esp]`.

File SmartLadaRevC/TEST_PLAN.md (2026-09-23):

# SmartLada Rev C - план тестирования

Прошивка **1.1.0-revC**. Документ для многодневного прогона: проходить сверху вниз,
отмечать результат прямо здесь (`OK` / `FAIL` + короткая заметка).
Незакрытые места и уже известные ловушки - в `SESSION_HANDOFF.md`.

## 0. Подготовка

Нужно: блок питания USB-C **PD с 12 В**, кабель USB к компьютеру (для логов и заливки),
телефон с приложением Яндекса, Wi-Fi-сеть 2.4 ГГц.

```
FQBN="esp32:esp32:esp32c6:ZigbeeMode=ed,PartitionScheme=zigbee_8MB,CDCOnBoot=cdc,FlashSize=16M"
arduino-cli compile -b "$FQBN" --build-path /tmp/smartlada SmartLadaRevC
arduino-cli upload  -b "$FQBN" -p /dev/cu.usbmodem101 --input-dir /tmp/smartlada SmartLadaRevC
```

**Три ловушки, которые исказят результат, если про них забыть:**

1. **Открытие USB-порта перезагружает плату** (`rst USB` в загрузочной строке). Любой запуск
   монитора = ребут. Во время BLE-сессии смотреть лог нельзя вообще: открытие порта выбьет
   плату из режима обновления.
2. **BLE OTA заливать только на PD 12 В.** На USB 5 В скорость падает до ~6.5 КБ/с и передача
   срывается на трети.
3. **Лампы не горят без 12 В** - это не поломка, а гейтинг. Для проверки логики на 5 В есть
   Settings -> Force Out.

Настройки сохраняются **через 4 секунды после того, как перестали меняться**. Если обесточить
раньше - изменения не переживут перезагрузку, и это ожидаемо.

## 1. Питание и загрузка

| ID | Что делаем | Ожидаем |
|----|---|---|
| P1 | Подать 12 В PD | Сплэш, затем плавный разгон ламп ~1.5 с (не рывок) |
| P2 | Подать только USB 5 В | Лампы не горят, на экране покоя "NO 12V" |
| P3 | На 5 В: Settings -> Force Out -> Yes | Каналы открываются (видно по индикаторным LED) |
| P4 | Ребут после Force Out | Force Out сброшен, лампы снова заперты |
| P5 | Выдернуть 12 В при горящих лампах | Гашение **мгновенное**, не плавное |
| P6 | Вернуть 12 В | Плавный подъём с нуля через soft start |
| P7 | Statistics: VBUS, temp, rst, счётчик загрузок | Значения правдоподобны, счётчик растёт при ребутах |
| P8 | Statistics: маркер обхода | Показано `fix`. `NOFIX` = обход не установился, это дефект |
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

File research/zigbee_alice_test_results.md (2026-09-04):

# SmartLada × Zigbee × Алиса — журнал тестов и чеклист

Живой документ. Заполняем по мере проверки: **что работает, что нет, как именно.**
Цель — эмпирически закрыть архитектурные риски до переноса Zigbee в продуктовую прошивку
`SmartLadaRevC`.

Связанные документы:
- Архитектура и теория: [`smartlada_alice_zigbee_multi_endpoint_summary.md`](smartlada_alice_zigbee_multi_endpoint_summary.md)
- Тест multi-endpoint: [`../sketches/RevCZigbee4EP/`](../sketches/RevCZigbee4EP/)
- Первый Zigbee bring-up (1 лампа): [`../sketches/RevAZigbeeTest/`](../sketches/RevAZigbeeTest/)
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

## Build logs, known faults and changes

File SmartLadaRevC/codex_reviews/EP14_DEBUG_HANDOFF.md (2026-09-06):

# EP14 / Yandex color display investigation

Status: baseline hardware sequence completed 2026-09-06; owner confirms both UI failures. Persistent EnhancedColorMode mismatch hypothesis disproved in this run. Diagnostic v2 compiled; next measurement is command/report tracing.
Target: SmartLadaRevC, current working tree v1.0.9-revC, Arduino-ESP32 3.3.10.

## Evidence vs hypotheses

- Reported symptom: white -> color snaps the app wheel to red; white changes to an unnamed white about 2 s later. Physical effect selection reportedly correct; not yet independently reproduced.
- Confirmed in installed Arduino core: constructor defaults ColorMode and EnhancedColorMode to XY (1). `setLightColorCapabilities(1)` does not change either mode. HSV callback synchronization explicitly writes only ColorMode. `setLightColorMode` is private.
- DISPROVED by baseline: EnhancedColorMode stays 1 after color commands. All 20 post-command snapshots show ColorMode=EnhancedColorMode=0 without H. The underlying stack updates it despite no explicit Arduino write.
- NOT established: Yandex reads/uses EnhancedColorMode. An attribute-table dump cannot identify incoming read requests or outgoing network traffic.
- Early returns from state/level setters do not prove radio silence: automatic reporting and read responses remain possible.
- ZCL requires copying a changed ColorMode to EnhancedColorMode for ordinary color modes. Source: [ZCL revision 6, section 5.2.2.2.1.2](https://csa-iot.org/wp-content/uploads/2019/12/07-5123-06-zigbee-cluster-library-specification.pdf).

## Changes in this pass

- Added `src/net/fara_diagnostics.{h,cpp}`; added diagnostic hooks to `src/net/zigbee.cpp` only.
- USB snapshots on connection, after settled HSV processing, and 2300 ms after the last settled callback.
- USB `?`: immediate read. Logs decimal mode, enhanced mode, capabilities, hue, saturation, X/Y, temperature, on/off and level. `-1` means missing attribute or unexpected type.
- USB uppercase `H`: one-shot experiment. If caps=1, ColorMode=0 and EnhancedColorMode>0, write only EnhancedColorMode=0. Print before/after and SDK status. Otherwise do nothing.
- No automatic correction, no forced report, no hue/brightness write from diagnostic code. Original application reporting remains active. All SDK access is locked; USB printing occurs after releasing the lock.
- H deliberately does not force ColorMode: that would bypass the library's private mode cache. First select a color normally.
- No Arduino core edits, commits or factory reset. Diagnostic uploads authorized by owner. Existing uncommitted work preserved.

## Live session (2026-09-06)

- Upload to `/dev/cu.usbmodem101` succeeded; ESP32-C6 detected, all written hashes verified. Firmware diagnostic marker confirmed over USB.
- Baseline capture: `codex_reviews/EP14_USB_2026-09-06.log`. Reader session 82905 stopped after the sequence to release the port for v2 upload.
- Initial manual snapshot: mode=1, enhanced=1, caps=1, h=0, s=0, x=24939, y=24701, ct=250, on=1, level=107. Confirms inconsistent initial capabilities/mode; does NOT yet establish post-color state or cause of UI issue.
- Owner's baseline sequence: white -> magenta -> white -> blue -> white -> cyan -> white -> green -> white -> red. Requested ~4 s between selections.
- No H correction sent; no mismatch exists after a color command, so H would be a no-op.

### Baseline result

All ten selections arrived, each with the same values immediately after settling and 2300 ms later. mode=0, enhanced=0, caps=1, level=107 throughout these snapshots. X/Y stay at 24939/24701; this alone does not establish that Yandex uses them.

| Selection | H | S | Firmware effect mode |
|---|---:|---:|---:|
| White (all 5 selections) | 162 | 25 | 0 |
| Magenta | 215 | 243 | 5 |
| Blue | 158 | 243 | 4 |
| Cyan | 124 | 243 | 3 |
| Green | 95 | 243 | 2 |
| Red | 0 | 243 | 1 |

Each action produced two callbacks carrying the previous HSV pair, followed ~100 ms later by the hue/saturation update pair. Existing coalescing applied the final pair in these ten trials. This does not prove correctness under other timing or concurrency.

### Diagnostic v2

- Chain the Arduino 3.3.10 APS receive hook (preserving its binding handling) to log EP14 Color Control, OnOff and Level frames as bounded hex. This shows commands/read requests; it is not an over-the-air sniffer.
- Add ZCL send-status hook; it exposes status/TSN/endpoints, NOT transmitted attribute values. Do not claim payload evidence from it.
- `?` also reads reporting configuration/last reported storage for H/S/X/Y/modes/enhanced hue. Configuration is not proof of actual delivery.
- `R` sends the current H, S, ColorMode once each to coordinator endpoint learned from an incoming Color Control frame. Does not change any attributes or synthesize an effect-center hue. No automatic color reports.
- Next: owner selects white, waits >=4 s, selects blue, waits >=4 s and reports UI state. Capture RX/config, then use R to test whether current-value reports correct the displayed color. Do not send R before that baseline snapshot.
- v2 full build passed (1,116,464 bytes flash, 40,448 bytes globals). Host sanitizer tests passed, including bounded trace, chained handler and R destination/attribute IDs/no attribute writes. Build: `/tmp/smartlada-ep14-debug/build-v2`.
- v2 uploaded successfully; reader session **80322**, log `codex_reviews/EP14_USB_v2_2026-09-06.log`. Initial capture found a blue state (h=158/s=243), apparently selected before capture started, so its RX trace was missed. Request a fresh white -> blue sequence now that capture is active.
- Initial reporting lookup: H direction=1, S direction=0 (min=1, max=28800, delta low byte=1, last low byte=243). This is suspicious but not yet proof of the fault. v2 prints `send_info` even for direction=1: IGNORE min/max/delta/last for that record (it is the receive union). Also ignore upper bytes of delta/last for U8 attributes. Inspect actual configure-report requests if available; do not assume this lookup proves all report behavior.
- R has not been sent.

## Next hardware test

1. With owner approval, upload the compiled diagnostic build to the confirmed lamp port; keep Zigbee pairing/storage intact.
2. Capture USB output. Find `EP14 diagnostic build` marker (firmware version string itself is unchanged).
3. Select white, wait >=3 s, select a clearly non-red color, wait >=3 s. Record when the app changes and retain both settled/+2300ms snapshots. Repeat once.
4. If snapshots show caps=1, mode=0, enhanced=1, send H once. Confirm status=0 and enhanced=0. Repeat the identical white/color sequence, preferably multiple times. No forced report means the UI need not change immediately on H alone.
5. If the app still fails while both mode attributes remain 0, the mismatch alone is insufficient to explain the symptom. If enhanced was already 0 before H, the main premise in problem.txt is disproved for that run.
6. If H consistently fixes it, implement a small permanent initialization/synchronization fix and retest boot/rejoin/on-off/brightness. Do not simply write ColorMode behind the library's internal cache.
7. If inconclusive, inspect actual Zigbee traffic or compare another coordinator. A different coordinator behaving well is useful evidence, not proof that only Yandex is at fault; endpoint acceptance/quirks/report configuration may differ.

## Validation

- Full Arduino build passed: 1,113,896 bytes flash (32%); 40,440 bytes globals (12%).
- FQBN: `esp32:esp32:esp32c6:ZigbeeMode=ed,PartitionScheme=zigbee_8MB,CDCOnBoot=cdc,FlashSize=16M`.
- Build directory: `/tmp/smartlada-ep14-debug/build` (temporary).
- Host test compiled actual diagnostic source with mocked SDK, AddressSanitizer and UndefinedBehaviorSanitizer: read-only default; single-attribute correction; no write for already-HS, wrong capabilities, XY mode, missing/wrong-type attribute; lock failure and setter failure; delayed snapshot and millis wrap. Passed. This does not validate the actual stack or Yandex.

## Separate existing issue; not changed to keep the experiment isolated

`onFaraHsv()` unconditionally calls `applyLevel(value)`, including on color callbacks with an unchanged level. In static mode this still flattens every channel's stored brightness before the hue/saturation pair settles. Therefore the claim that coalescing fully prevents that overwrite is false for the present working tree. A later fix should distinguish level events from color events instead of treating every HSV callback as a brightness command. The pending HSV fields also lack an atomic snapshot across tasks.

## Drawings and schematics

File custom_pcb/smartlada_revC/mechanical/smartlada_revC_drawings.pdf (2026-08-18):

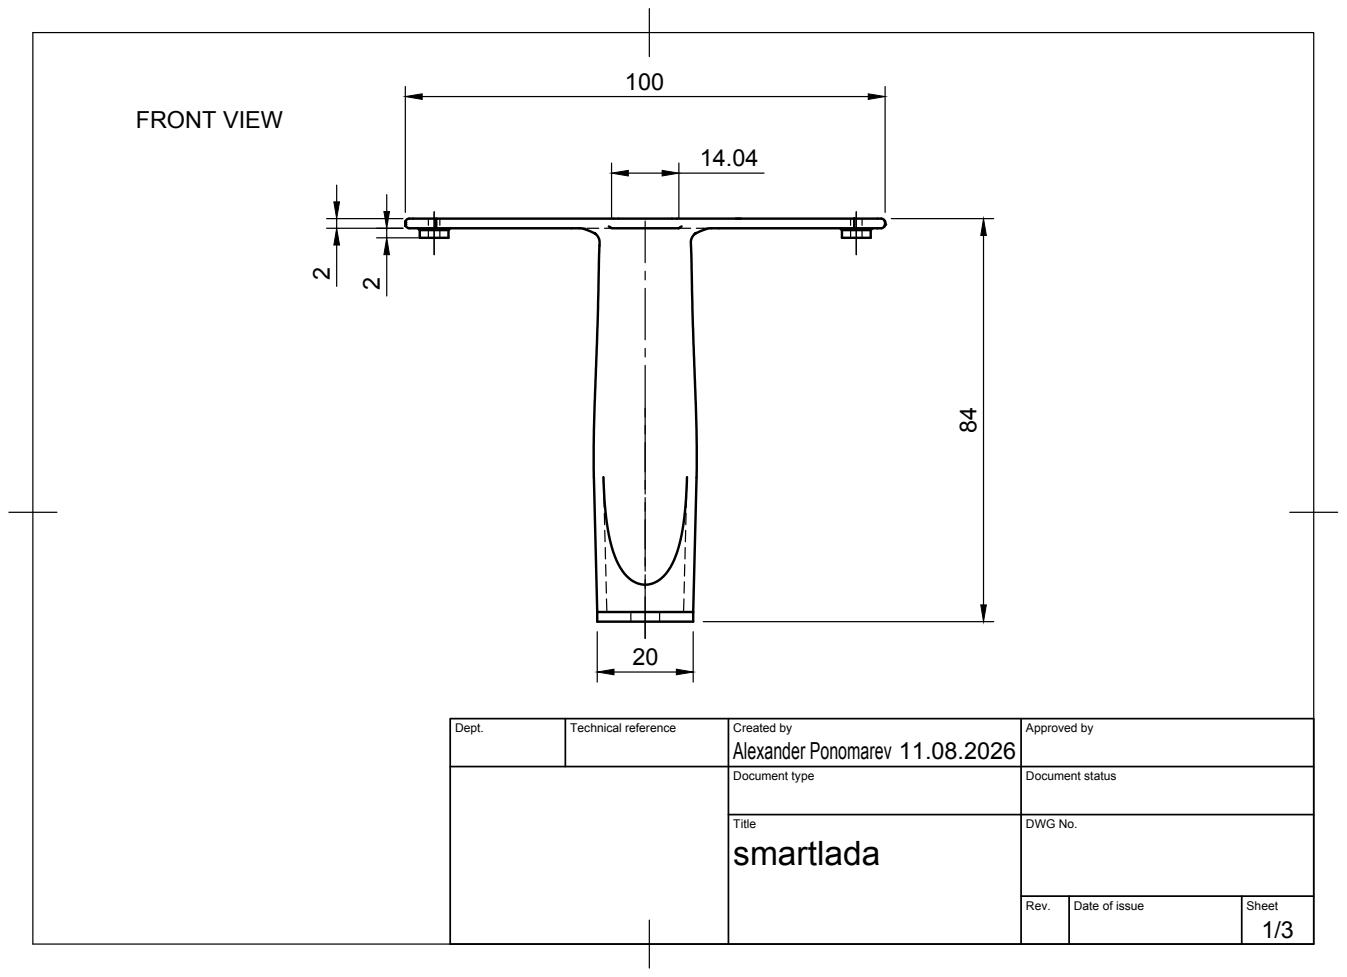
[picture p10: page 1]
FRONT VIEW

Dept. | Technical reference | Created by Alexander Ponomarev 11.08.2026 | Approved by

Document type | Document status

Title smartlada | DWG No.

Rev. | Date of issue | Sheet

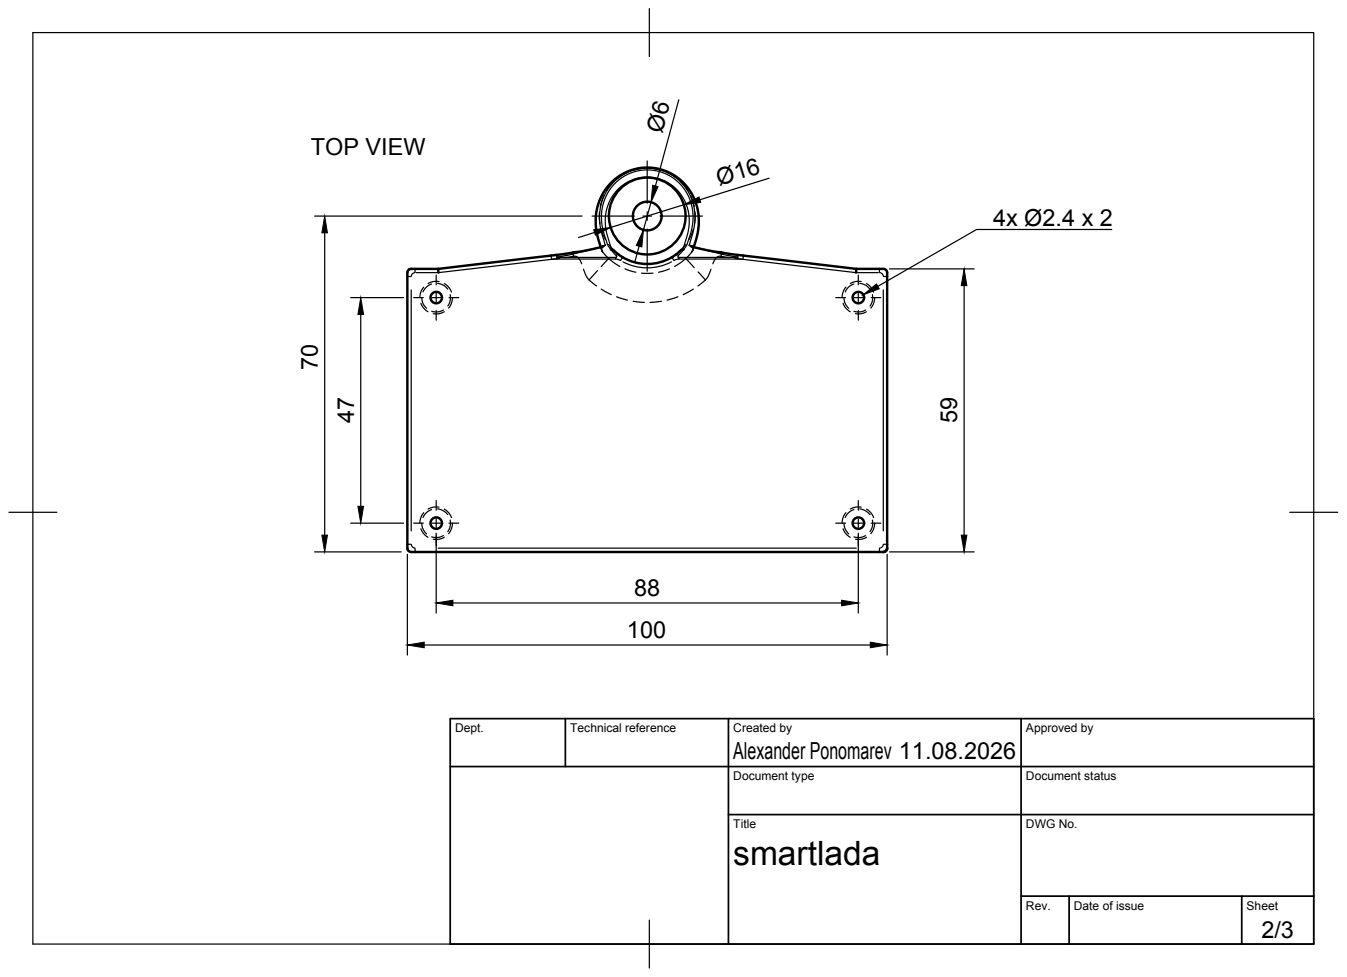
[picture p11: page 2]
Alexander Ponomarev 70; TOP VIEW

Dept. | Technical reference | Created by 11.08.2026 | Approved by

Document type | Document status

Title smartlada | DWG No.

Rev. | Date of issue | Sheet

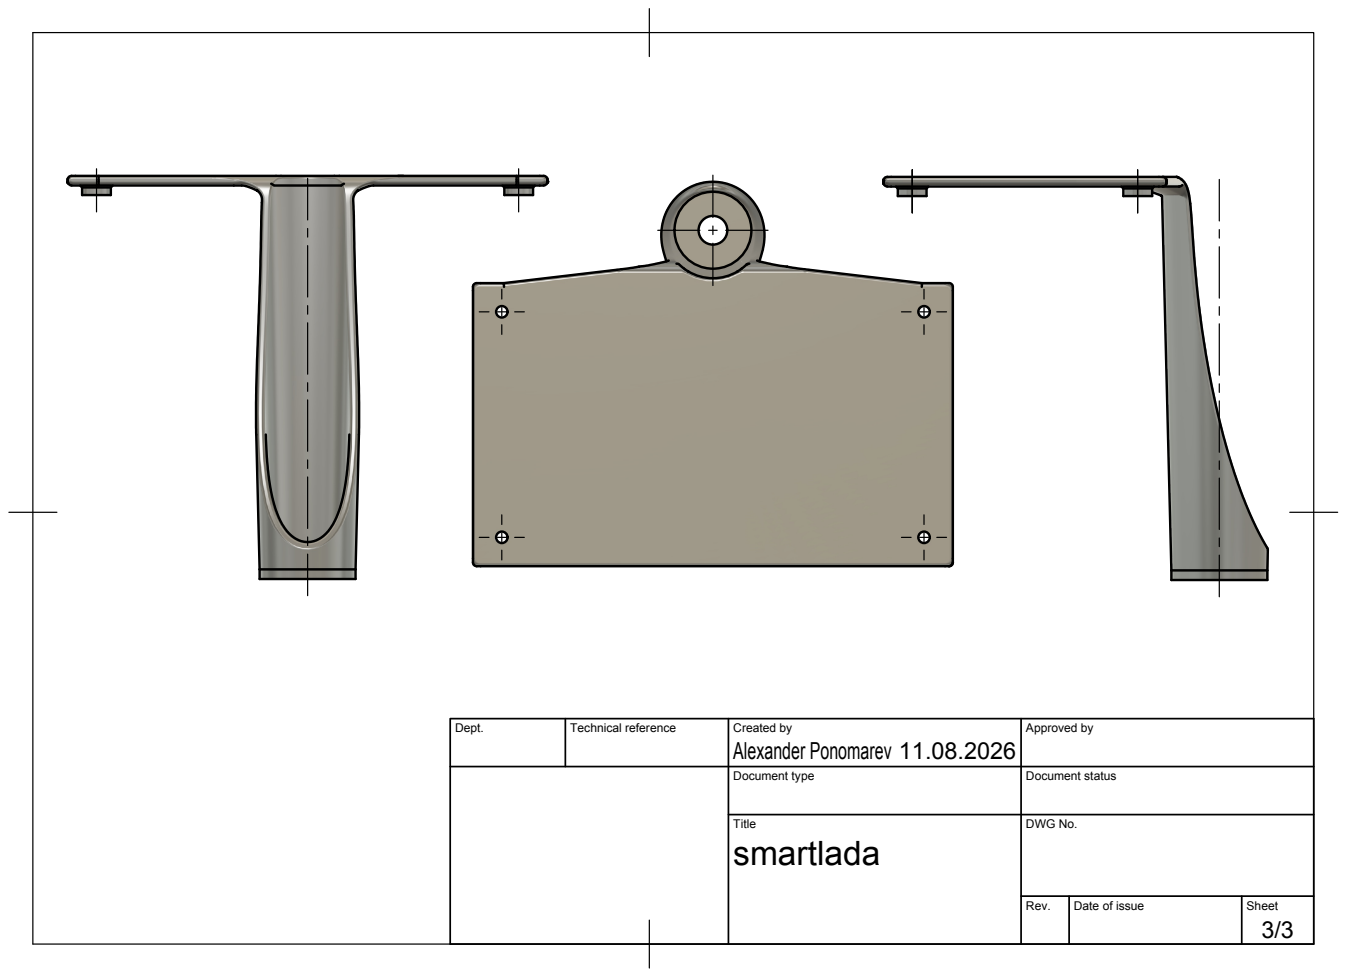
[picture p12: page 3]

Dept. | Technical reference | Created by Alexander Ponomarev 11.08.2026 | Approved by

Document type | Document status

Title smartlada | DWG No.

Rev. | Date of issue | Sheet

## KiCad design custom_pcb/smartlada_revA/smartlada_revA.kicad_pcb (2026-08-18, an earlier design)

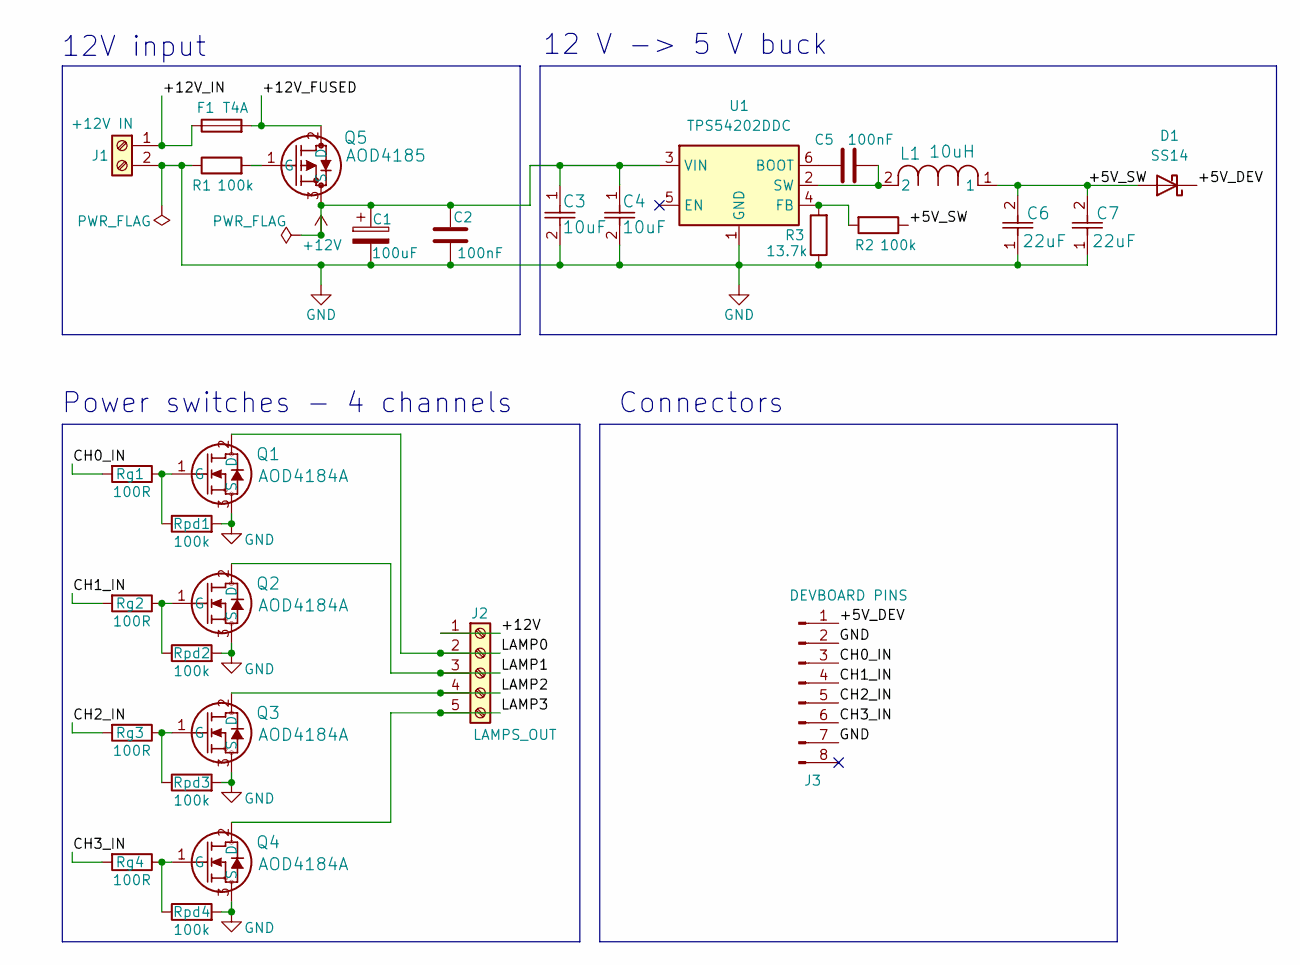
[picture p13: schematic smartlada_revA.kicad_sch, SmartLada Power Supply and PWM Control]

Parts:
C1: 100uF; CP_Radial_D6.3mm_P2.50mm; MPN EEUFR1E101
C2: 100nF; C_0805_2012Metric_Pad1.18x1.45mm_HandSolder; MPN GRM21BR71E104KA01L
C3, C4: 10uF; CAP_UMK325BJ106KM-P_TAY; MPN HLC1210X7R106K500N
C5: 100nF; C_0603_1608Metric_Pad1.08x0.95mm_HandSolder; MPN GRM188R72A104KA35D
C6, C7: 22uF; CAP_2012_TDK; MPN GRT21BR61E226ME13L
D1: SS14; D_SMA; MPN SS14-E3/61T
F1: T4A; Fuseholder_Cylinder-5x20mm_Schurter_0031_8201_Horizontal_Op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; MPN S1052-1
J1: +12V IN; TerminalBlock_MaiXu_MX126-5.0-02P_1x02_P5.00mm; MPN DG127-5.0-02P-14-00Z(H)
J2: LAMPS_OUT; TerminalBlock_Phoenix_MPT-0,5-5-2.54_1x05_P2.54mm_Horizontal; MPN DG308-2.54-05P-14-00ZH
J3: DEVBOARD PINS; PinHeader_1x08_P2.54mm_Vertical; MPN PLS-40 (alt L-KLS1-207-1-40-S)
L1: 10uH; IND_CDRH6D28NP-100NC_SUM; MPN CDRH6D28NP-100NC
Q1, Q2, Q3, Q4: AOD4184A; TO252_AOS; MPN AOD4184A
Q5: AOD4185; TO252_AOS; MPN AOD4185
R1, R2: 100k; R_0805_2012Metric_Pad1.20x1.40mm_HandSolder; MPN ERJP06F1003V
R3: 13.7k; R_0805_2012Metric_Pad1.20x1.40mm_HandSolder; MPN RC0805FR-0713K7L
Rg1, Rg2, Rg3, Rg4: 100R; R_0805_2012Metric_Pad1.20x1.40mm_HandSolder; MPN RT0805BRD07100RL
Rpd1, Rpd2, Rpd3, Rpd4: 100k; R_0805_2012Metric_Pad1.20x1.40mm_HandSolder; MPN ERJP06F1003V
U1: TPS54202DDC; SOT-23-6; MPN TPS54202DDCR

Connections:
+12V: C1.1, C2.1, C3.1, C4.1, J2.1, Q5.3 (S), U1.3 (VIN)
/+5V_DEV: D1.1 (K), J3.1
/+5V_SW: C6.2, C7.2, D1.2 (A), L1.1, R2.1
/+12V_FUSED: F1.2, Q5.2 (D)
/+12V_IN: F1.1, J1.1
/CH0_IN: J3.3, Rg1.2
/CH1_IN: J3.4, Rg2.2
/CH2_IN: J3.5, Rg3.2
/CH3_IN: J3.6, Rg4.2
/LAMP0: J2.2, Q1.2 (D)
/LAMP1: J2.3, Q2.2 (D)
/LAMP2: J2.4, Q3.2 (D)
/LAMP3: J2.5, Q4.2 (D)
GND: C1.2, C2.2, C3.2, C4.2, C6.1, C7.1, J1.2, J3.2, J3.7, Q1.3 (S), Q2.3 (S), Q3.3 (S), Q4.3 (S), R1.1, R3.1, Rpd1.2, Rpd2.2, Rpd3.2, Rpd4.2, U1.1 (GND)
unnamed: Q1.1 (G), Rg1.1, Rpd1.1
unnamed: Q2.1 (G), Rg2.1, Rpd2.1
unnamed: Q3.1 (G), Rg3.1, Rpd3.1
unnamed: Q4.1 (G), Rg4.1, Rpd4.1
unnamed: Q5.1 (G), R1.2
unnamed: C5.1, U1.6 (BOOT)
unnamed: R2.2, R3.2, U1.4 (FB)
unnamed: C5.2, L1.2, U1.2 (SW)

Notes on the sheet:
12V input
12 V -> 5 V buck
Connectors
Power switches - 4 channels

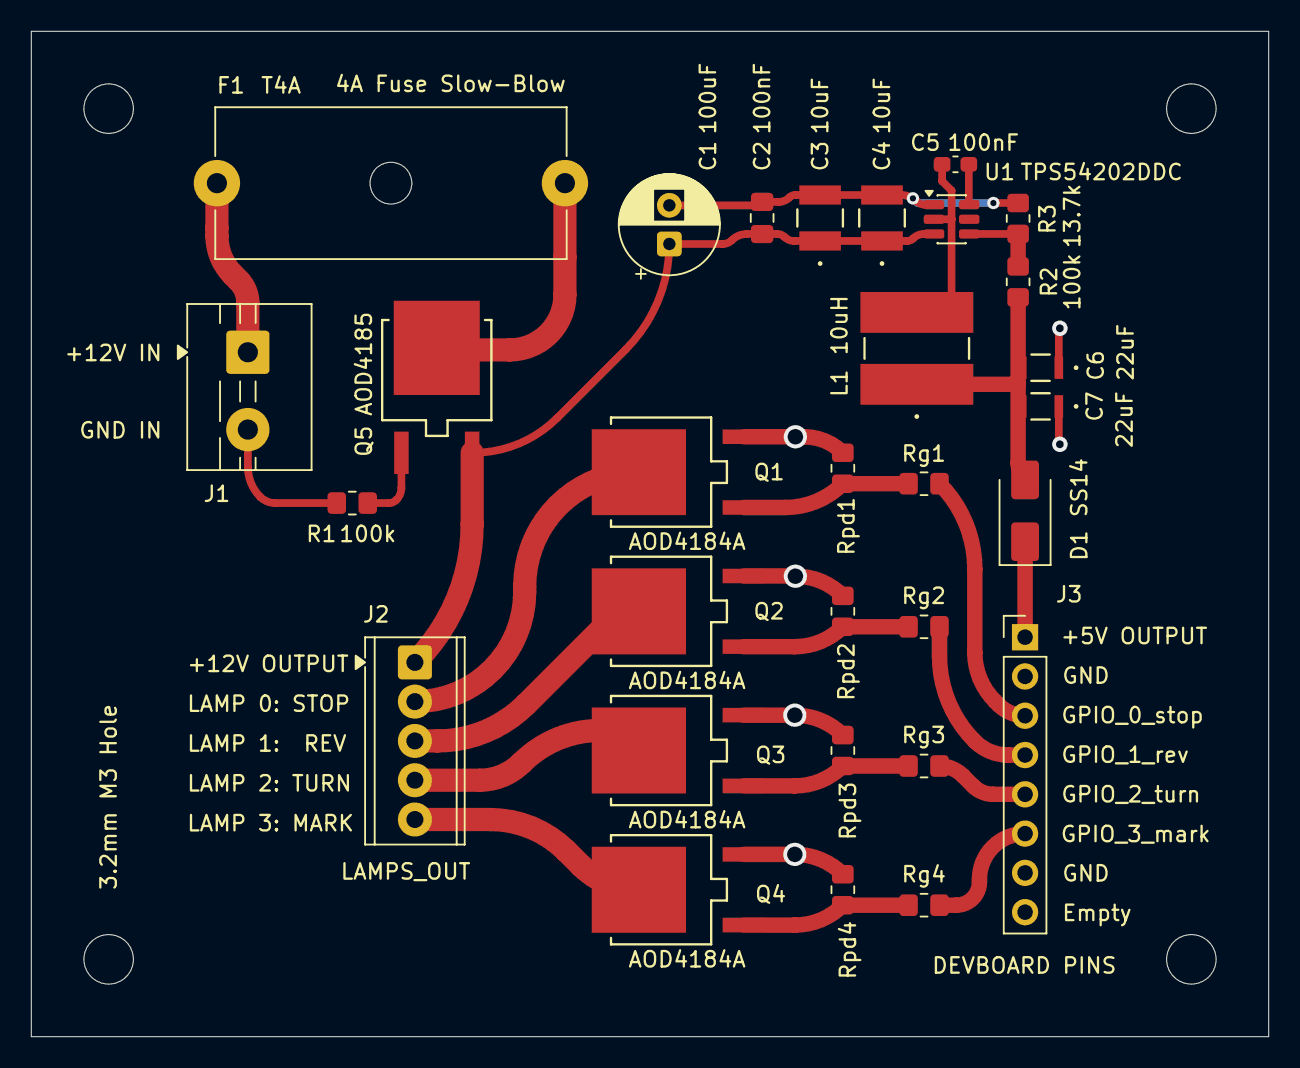
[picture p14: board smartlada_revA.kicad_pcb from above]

Board: 2 copper layers, 80.0 x 65.0 mm, 34 parts (0 on the bottom side), 22 nets.

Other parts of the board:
H1, H2, H3: 3.2mm_M3; MountingHole_3.2mm_M3
H4: 3.2mm M3 Hole; MountingHole_3.2mm_M3

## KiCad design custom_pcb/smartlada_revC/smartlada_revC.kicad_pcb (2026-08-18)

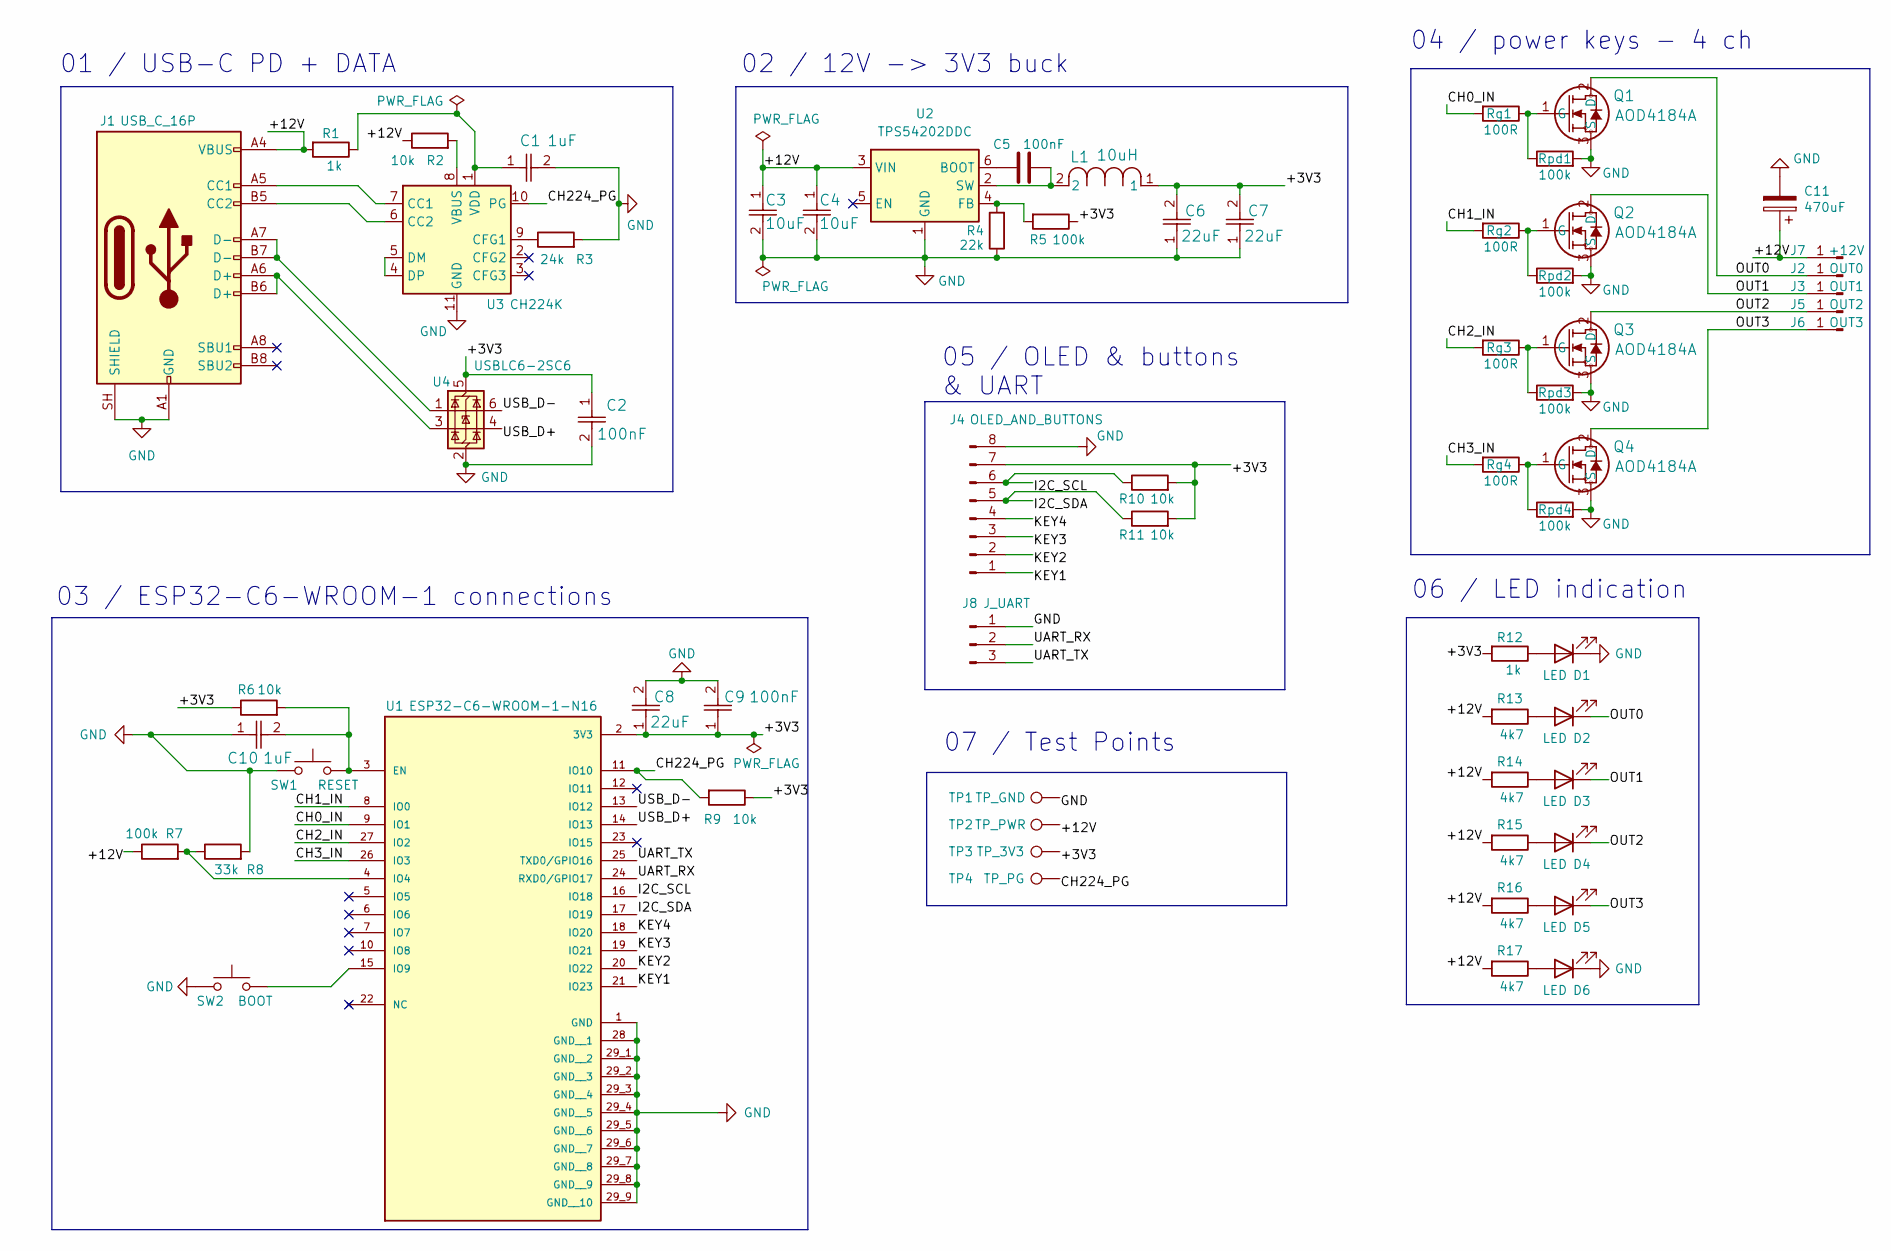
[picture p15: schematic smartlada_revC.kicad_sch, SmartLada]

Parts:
C1: 1uF; C_0805_2012Metric_Pad1.18x1.45mm_HandSolder; MPN GRM32ER71H106KA12L
C2: 100nF; C_0805_2012Metric_Pad1.18x1.45mm_HandSolder; MPN GRM32ER71H106KA12L
C3, C4: 10uF; C_1210_3225Metric_Pad1.33x2.70mm_HandSolder; MPN GRM32ER71H106KA12L
C5, C9: 100nF; C_0805_2012Metric_Pad1.18x1.45mm_HandSolder; MPN TCC0603X7R104K250CT
C6, C7, C8: 22uF; C_1210_3225Metric_Pad1.33x2.70mm_HandSolder; MPN GRT21BR61E226ME13L
C10: 1uF; C_0805_2012Metric_Pad1.18x1.45mm_HandSolder; MPN TCC0603X7R105K250CT
C11: 470uF; CP_Elec_10x10.5
D1, D2, D3, D4, D5, D6: LED; LED_0805_2012Metric_Pad1.15x1.40mm_HandSolder
J1: USB_C_16P; USB_C_Receptacle_HRO_TYPE-C-31-M-12
J2: OUT0; TE_1217754-1
J3: OUT1; TE_1217754-1
J4: OLED_AND_BUTTONS; PinHeader_1x08_P2.54mm_Horizontal; MPN PBS-40
J5: OUT2; TE_1217754-1
J6: OUT3; TE_1217754-1
J7: +12V; TE_1217754-1
J8: J_UART; PinHeader_1x03_P2.54mm_Horizontal
L1: 10uH; IND_CDRH6D28NP-100NC_SUM; MPN CDRH6D28NP-100NC
Q1, Q2, Q3, Q4: AOD4184A; TO252_AOS; MPN AOD4184A
R1, R12: 1k; R_0805_2012Metric_Pad1.20x1.40mm_HandSolder
R2, R9: 10k; R_0805_2012Metric_Pad1.20x1.40mm_HandSolder
R3: 24k; R_0805_2012Metric_Pad1.20x1.40mm_HandSolder
R4: 22k; R_0805_2012Metric_Pad1.20x1.40mm_HandSolder; MPN RC0805JR-0722KL
R5: 100k; R_0805_2012Metric_Pad1.20x1.40mm_HandSolder; MPN ERJP06F1003V
R6, R10, R11: 10k; R_0805_2012Metric_Pad1.20x1.40mm_HandSolder; MPN ERJ6ENF1002V
R7: 100k; R_0805_2012Metric_Pad1.20x1.40mm_HandSolder
R8: 33k; R_0805_2012Metric_Pad1.20x1.40mm_HandSolder
R13, R14, R15, R16, R17: 4k7; R_0805_2012Metric_Pad1.20x1.40mm_HandSolder
Rg1, Rg2, Rg3, Rg4: 100R; R_0805_2012Metric_Pad1.20x1.40mm_HandSolder; MPN RT0805BRD07100RL
Rpd1, Rpd2, Rpd3, Rpd4: 100k; R_0805_2012Metric_Pad1.20x1.40mm_HandSolder; MPN ERJP06F1003V
SW1: RESET; SW_SPST_Omron_B3FS-100xP; MPN 1-1825910-0
SW2: BOOT; SW_SPST_Omron_B3FS-100xP; MPN 1-1825910-0
TP1: TP_GND; TestPoint_THTPad_D2.0mm_Drill1.0mm
TP2: TP_PWR; TestPoint_THTPad_D2.0mm_Drill1.0mm
TP3: TP_3V3; TestPoint_THTPad_D2.0mm_Drill1.0mm
TP4: TP_PG; TestPoint_THTPad_D2.0mm_Drill1.0mm
U1: ESP32-C6-WROOM-1-N16; XCVR_ESP32-C6-WROOM-1-N16; MPN ESP32-C6-WROOM-1-N16
U2: TPS54202DDC; SOT-23-6_Handsoldering; MPN TPS54202DDCR
U3: CH224K; SSOP-10-1EP_3.9x4.9mm_P1mm_EP2.1x3.3mm_ThermalVias
U4: USBLC6-2SC6; SOT-23-6_Handsoldering

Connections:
/+3V3: C2.1, C6.2, C7.2, C8.1, C9.1, J4.7, L1.1, R5.1, R6.1, R9.1, R10.2, R11.2, R12.2, TP3.1 (1_1), U1.2 (3V3), U4.5 (VBUS)
/+12V: C3.1, C4.1, C11.1, J1.A4 (VBUS), J1.A9 (VBUS), J1.B4 (VBUS), J1.B9 (VBUS), J7.1 (Pin_1_1), R1.2, R2.1, R7.1, R13.2, R14.2, R15.2, R16.2, R17.2, TP2.1 (1_1), U2.3 (VIN)
/CH0_IN: Rg1.2, U1.9 (IO1)
/CH1_IN: Rg2.2, U1.8 (IO0)
/CH2_IN: Rg3.2, U1.27 (IO2)
/CH3_IN: Rg4.2, U1.26 (IO3)
/CH224_PG: R9.2, TP4.1 (1_1), U1.11 (IO10), U3.10 (PG)
/I2C_SCL: J4.6, R10.1, U1.16 (IO18)
/I2C_SDA: J4.5, R11.1, U1.17 (IO19)
/KEY1: J4.1, U1.21 (IO23)
/KEY2: J4.2, U1.20 (IO22)
/KEY3: J4.3, U1.19 (IO21)
/KEY4: J4.4, U1.18 (IO20)
/OUT0: D2.1 (K), J2.1 (Pin_1_1), Q1.2 (D)
/OUT1: D3.1 (K), J3.1 (Pin_1_1), Q2.2 (D)
/OUT2: D4.1 (K), J5.1 (Pin_1_1), Q3.2 (D)
/OUT3: D5.1 (K), J6.1 (Pin_1_1), Q4.2 (D)
/UART_RX: J8.2, U1.24 (RXD0/GPIO17)
/UART_TX: J8.3, U1.25 (TXD0/GPIO16)
/USB_D+: U1.14 (IO13), U4.4 (I/O2)
/USB_D-: U1.13 (IO12), U4.6 (I/O1)
GND: C1.2, C2.2, C3.2, C4.2, C6.1, C7.1, C8.2, C9.2, C10.1, C11.2, D1.1 (K), D6.1 (K), J1.A1 (GND), J1.A12 (GND), J1.B1 (GND), J1.B12 (GND), J1.SH (SHIELD), J4.8, J8.1, Q1.3 (S), Q2.3 (S), Q3.3 (S), Q4.3 (S), R3.2, R4.1, R8.2, Rpd1.2, Rpd2.2, Rpd3.2, Rpd4.2, SW1.1, SW2.1, TP1.1 (1_1), U1.1 (GND), U1.28 (GND__1), U1.29_1 (GND__2), U1.29_2 (GND__3), U1.29_3 (GND__4), U1.29_4 (GND__5), U1.29_5 (GND__6), U1.29_6 (GND__7), U1.29_7 (GND__8), U1.29_8 (GND__9), U1.29_9 (GND__10), U2.1 (GND), U3.11 (GND), U4.2 (GND)
unnamed: D1.2 (A), R12.1
unnamed: D2.2 (A), R13.1
unnamed: D3.2 (A), R14.1
unnamed: D4.2 (A), R15.1
unnamed: D5.2 (A), R16.1
unnamed: D6.2 (A), R17.1
unnamed: J1.A5 (CC1), U3.7 (CC1)
unnamed: J1.B5 (CC2), U3.6 (CC2)
unnamed: J1.A6 (D+), J1.B6 (D+), U4.3 (I/O2)
unnamed: J1.A7 (D-), J1.B7 (D-), U4.1 (I/O1)
unnamed: Q1.1 (G), Rg1.1, Rpd1.1
unnamed: Q2.1 (G), Rg2.1, Rpd2.1
unnamed: Q3.1 (G), Rg3.1, Rpd3.1
unnamed: Q4.1 (G), Rg4.1, Rpd4.1
unnamed: C10.2, R6.2, SW1.2, U1.3 (EN)
unnamed: R7.2, R8.1, U1.4 (IO4)
unnamed: SW2.2, U1.15 (IO9)
unnamed: C5.1, U2.6 (BOOT)
unnamed: R4.2, R5.2, U2.4 (FB)
unnamed: C5.2, L1.2, U2.2 (SW)
unnamed: R3.1, U3.9 (CFG1)
unnamed: U3.4 (DP), U3.5 (DM)
unnamed: R2.2, U3.8 (VBUS)
unnamed: C1.1, R1.1, U3.1 (VDD)

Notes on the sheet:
03 / ESP32-C6-WROOM-1 connections
05 / OLED & buttons & UART
04 / power keys - 4 ch
07 / Test Points
01 / USB-C PD + DATA
06 / LED indication
02 / 12V -> 3V3 buck

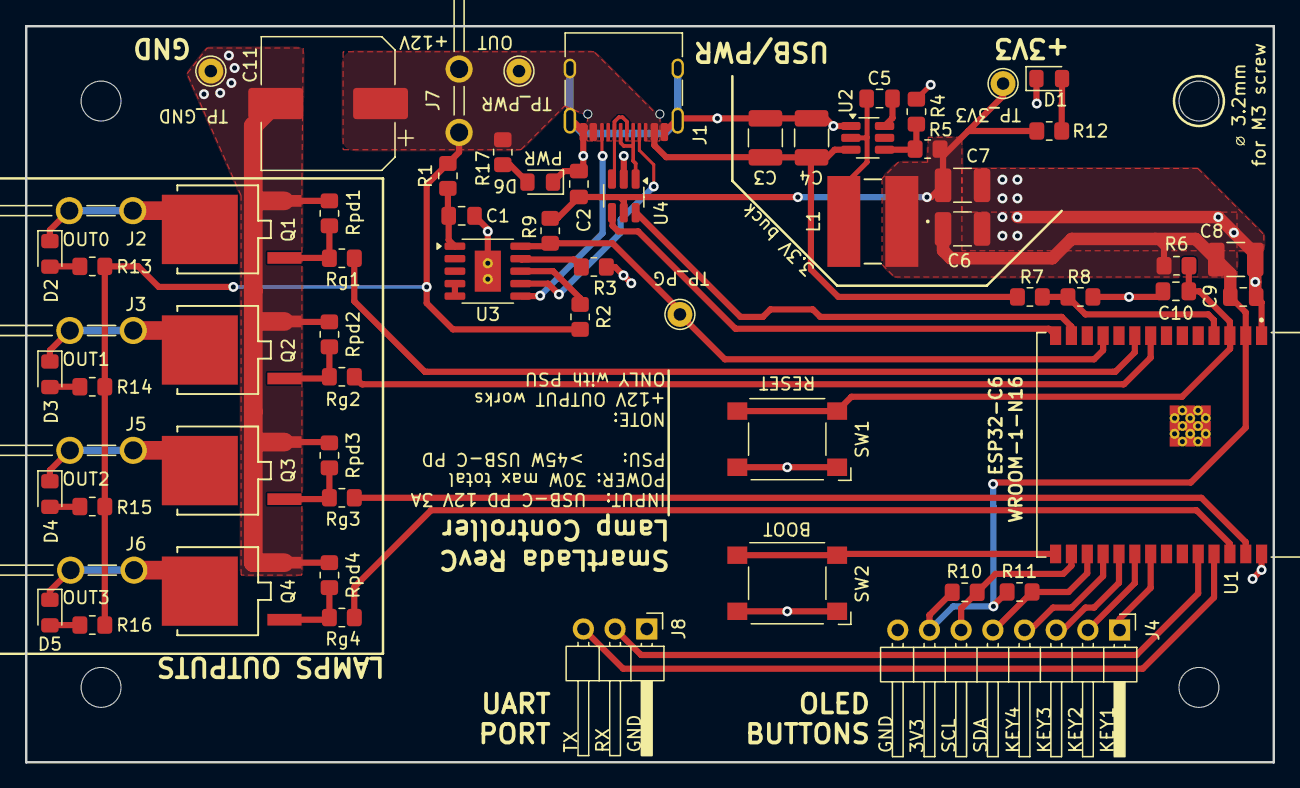
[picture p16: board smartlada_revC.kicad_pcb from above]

Board: 2 copper layers, 100.0 x 59.0 mm, 69 parts (0 on the bottom side), 46 nets.

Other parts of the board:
HOLE1, HOLE1#2, HOLE1#3, HOLE1#4: MountingHole_3.2mm_M3

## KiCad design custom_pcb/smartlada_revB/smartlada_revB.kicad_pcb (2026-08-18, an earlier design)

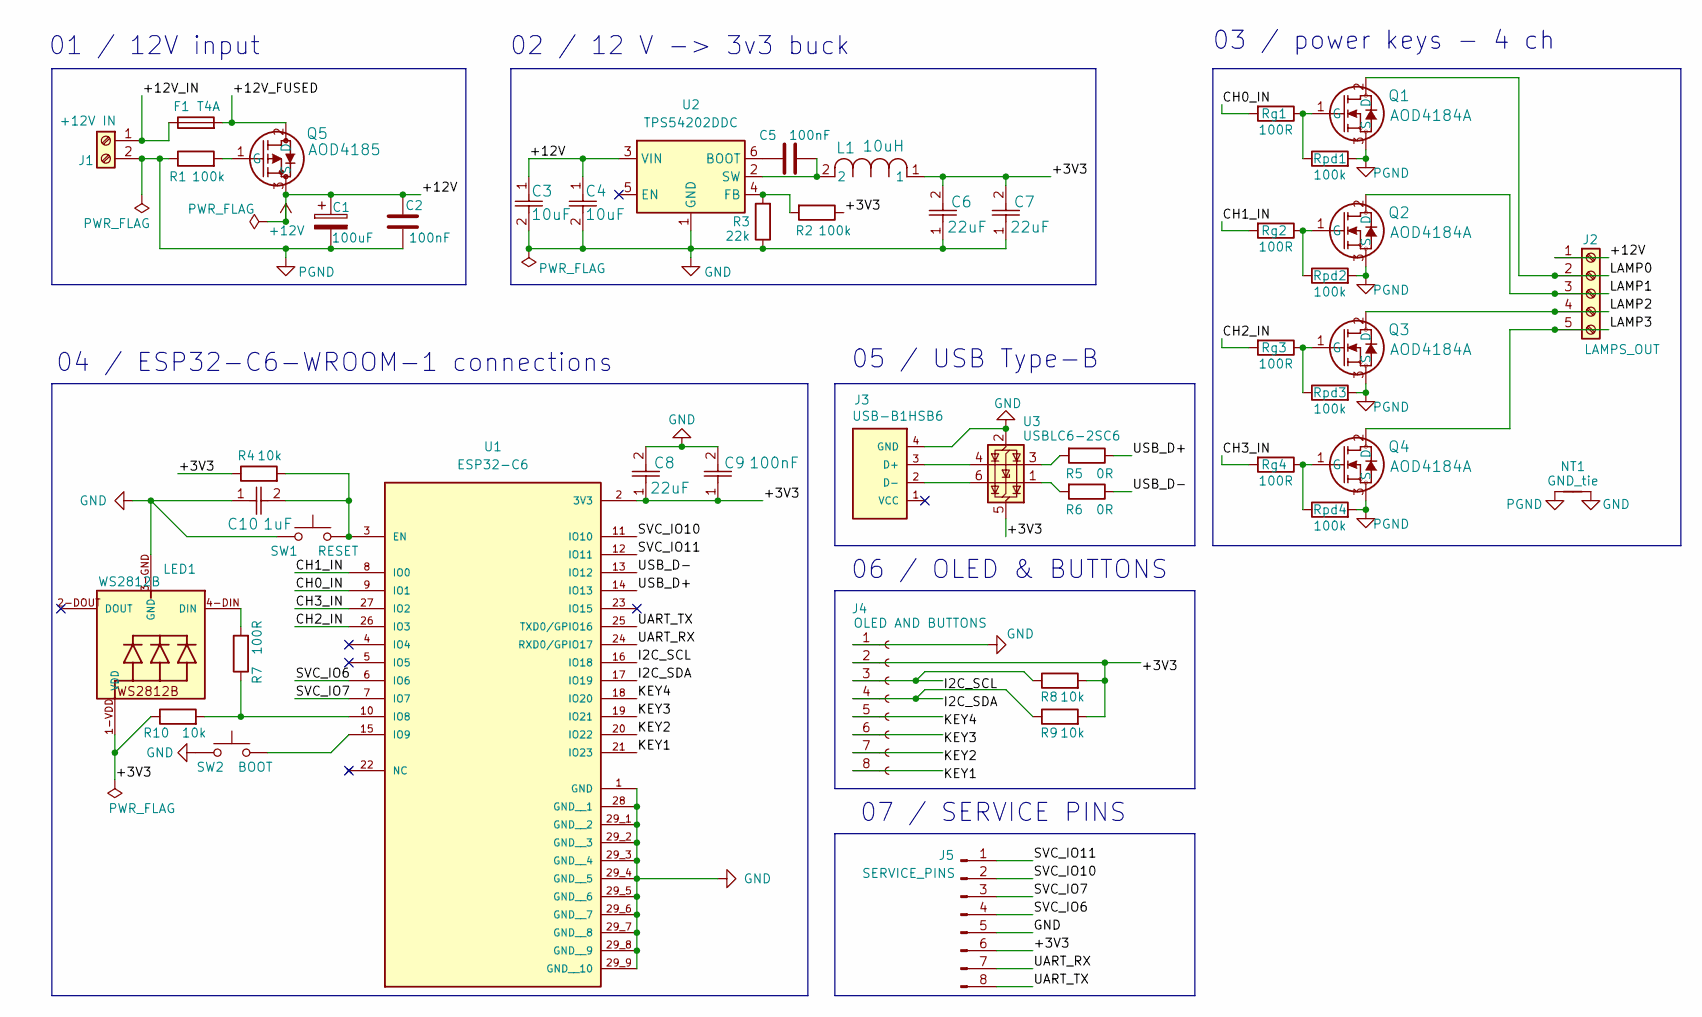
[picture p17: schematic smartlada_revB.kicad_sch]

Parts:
C1: 100uF; CP_Radial_D6.3mm_P2.50mm; MPN EEUFR1E101
C2: 100nF; C_0805_2012Metric_Pad1.18x1.45mm_HandSolder; MPN TCC0603X7R104K250CT
C3, C4: 10uF; C_1210_3225Metric_Pad1.33x2.70mm_HandSolder; MPN GRM32ER71H106KA12L
C5, C9: 100nF; C_0603_1608Metric_Pad1.08x0.95mm_HandSolder; MPN TCC0603X7R104K250CT
C6, C7, C8: 22uF; C_1210_3225Metric_Pad1.33x2.70mm_HandSolder; MPN GRT21BR61E226ME13L
C10: 1uF; C_0603_1608Metric_Pad1.08x0.95mm_HandSolder; MPN TCC0603X7R105K250CT
F1: T4A; Fuseholder_Cylinder-5x20mm_Schurter_0031_8201_Horizontal_Op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; MPN FS-52GT-4.0/250
J1: +12V IN; TerminalBlock_Phoenix_MKDS-1,5-2_1x02_P5.00mm_Horizontal; MPN DG127-5.0-02P-14-00Z(H)
J2: LAMPS_OUT; TerminalBlock_Phoenix_MPT-0,5-5-2.54_1x05_P2.54mm_Horizontal; MPN DG308-2.54-05P-14-00ZH
J3: USB-B1HSB6; OST_USB-B1HSB6; MPN USBB-1J-W
J4: OLED AND BUTTONS; PinSocket_1x08_P2.54mm_Vertical; MPN PBS-40
J5: SERVICE_PINS; PinHeader_1x08_P2.54mm_Vertical; MPN PLS-40
L1: 10uH; IND_CDRH6D28NP-100NC_SUM; MPN CDRH6D28NP-100NC
LED1: WS2812B; LED_WS2812B_PLCC4_5.0x5.0mm_P3.2mm; MPN WS2812B-V5
NT1: GND_tie; NetTie-2_THT_Pad0.3mm
Q1, Q2, Q3, Q4: AOD4184A; TO252_AOS; MPN AOD4184A
Q5: AOD4185; TO252_AOS; MPN AOD4185
R1, R2: 100k; R_0805_2012Metric_Pad1.20x1.40mm_HandSolder; MPN ERJP06F1003V
R3: 22k; R_0805_2012Metric_Pad1.20x1.40mm_HandSolder; MPN RC0805JR-0722KL
R4, R8, R9, R10: 10k; R_0805_2012Metric_Pad1.20x1.40mm_HandSolder; MPN ERJ6ENF1002V
R5, R6: 0R; R_0805_2012Metric_Pad1.20x1.40mm_HandSolder
R7: 100R; R_0805_2012Metric_Pad1.20x1.40mm_HandSolder; MPN RT0805BRD07100RL
Rg1, Rg2, Rg3, Rg4: 100R; R_0805_2012Metric_Pad1.20x1.40mm_HandSolder; MPN RT0805BRD07100RL
Rpd1, Rpd2, Rpd3, Rpd4: 100k; R_0805_2012Metric_Pad1.20x1.40mm_HandSolder; MPN ERJP06F1003V
SW1: RESET; SW4_1825910-F_TEC; MPN 1-1825910-0
SW2: BOOT; SW4_1825910-F_TEC; MPN 1-1825910-0
U1: ESP32-C6; XCVR_ESP32-C6-WROOM-1-N8; MPN ESP32-C6-WROOM-1-N16
U2: TPS54202DDC; SOT-23-6; MPN TPS54202DDCR
U3: USBLC6-2SC6; SOT-23-6_Handsoldering; MPN USBLC6-2SC6

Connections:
+12V: C1.1, C2.1, C3.1, C4.1, J2.1, Q5.3 (S), U2.3 (VIN)
/+3V3: C6.2, C7.2, C8.1, C9.1, J4.2, J5.6, L1.1, LED1.1-VDD (VDD), R2.1, R4.1, R8.2, R9.2, R10.1, U1.2 (3V3), U3.5 (VBUS)
/+12V_FUSED: F1.2, Q5.2 (D)
/+12V_IN: F1.1, J1.1
/CH0_IN: Rg1.2, U1.9 (IO1)
/CH1_IN: Rg2.2, U1.8 (IO0)
/CH2_IN: Rg3.2, U1.26 (IO3)
/CH3_IN: Rg4.2, U1.27 (IO2)
/I2C_SCL: J4.3, R8.1, U1.16 (IO18)
/I2C_SDA: J4.4, R9.1, U1.17 (IO19)
/KEY1: J4.8, U1.21 (IO23)
/KEY2: J4.7, U1.20 (IO22)
/KEY3: J4.6, U1.19 (IO21)
/KEY4: J4.5, U1.18 (IO20)
/LAMP0: J2.2, Q1.2 (D)
/LAMP1: J2.3, Q2.2 (D)
/LAMP2: J2.4, Q3.2 (D)
/LAMP3: J2.5, Q4.2 (D)
/SVC_IO6: J5.4, U1.6 (IO6)
/SVC_IO7: J5.3, U1.7 (IO7)
/SVC_IO10: J5.2, U1.11 (IO10)
/SVC_IO11: J5.1, U1.12 (IO11)
/UART_RX: J5.7, U1.24 (RXD0/GPIO17)
/UART_TX: J5.8, U1.25 (TXD0/GPIO16)
/USB_D+: R5.1, U1.14 (IO13)
/USB_D-: R6.1, U1.13 (IO12)
GND: C3.2, C4.2, C6.1, C7.1, C8.2, C9.2, C10.1, J3.4 (GND), J4.1, J5.5, LED1.3-GND (GND), NT1.2, R3.1, SW1.1, SW2.1, U1.1 (GND), U1.28 (GND__1), U1.29_1 (GND__2), U1.29_2 (GND__3), U1.29_3 (GND__4), U1.29_4 (GND__5), U1.29_5 (GND__6), U1.29_6 (GND__7), U1.29_7 (GND__8), U1.29_8 (GND__9), U1.29_9 (GND__10), U2.1 (GND), U3.2 (GND)
unnamed: J3.3 (D+), U3.4 (I/O2)
unnamed: J3.2 (D-), U3.6 (I/O1)
unnamed: LED1.4-DIN (DIN), R7.2
unnamed: Q1.1 (G), Rg1.1, Rpd1.1
unnamed: Q2.1 (G), Rg2.1, Rpd2.1
unnamed: Q3.1 (G), Rg3.1, Rpd3.1
unnamed: Q4.1 (G), Rg4.1, Rpd4.1
unnamed: Q5.1 (G), R1.2
unnamed: R5.2, U3.3 (I/O2)
unnamed: R6.2, U3.1 (I/O1)
unnamed: C10.2, R4.2, SW1.2, U1.3 (EN)
unnamed: R7.1, R10.2, U1.10 (IO8)
unnamed: SW2.2, U1.15 (IO9)
unnamed: C5.1, U2.6 (BOOT)
unnamed: R2.2, R3.2, U2.4 (FB)
unnamed: C5.2, L1.2, U2.2 (SW)
PGND: C1.2, C2.2, J1.2, NT1.1, Q1.3 (S), Q2.3 (S), Q3.3 (S), Q4.3 (S), R1.1, Rpd1.2, Rpd2.2, Rpd3.2, Rpd4.2

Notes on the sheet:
04 / ESP32-C6-WROOM-1 connections
06 / OLED & BUTTONS
03 / power keys - 4 ch
01 / 12V input
05 / USB Type-B
07 / SERVICE PINS
02 / 12 V -> 3v3 buck

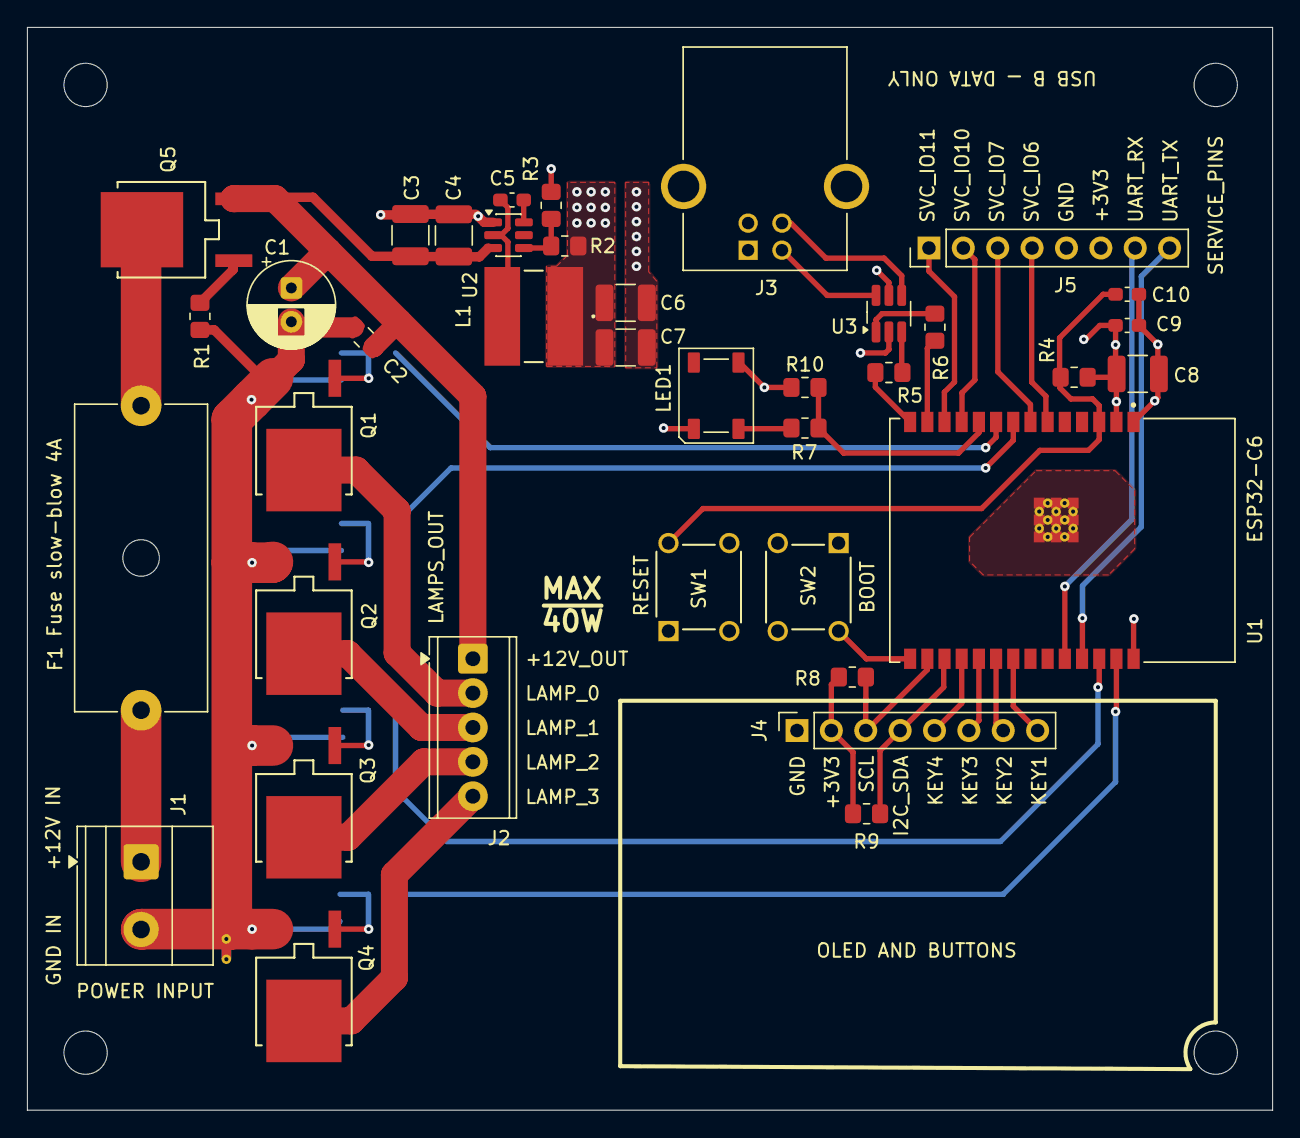
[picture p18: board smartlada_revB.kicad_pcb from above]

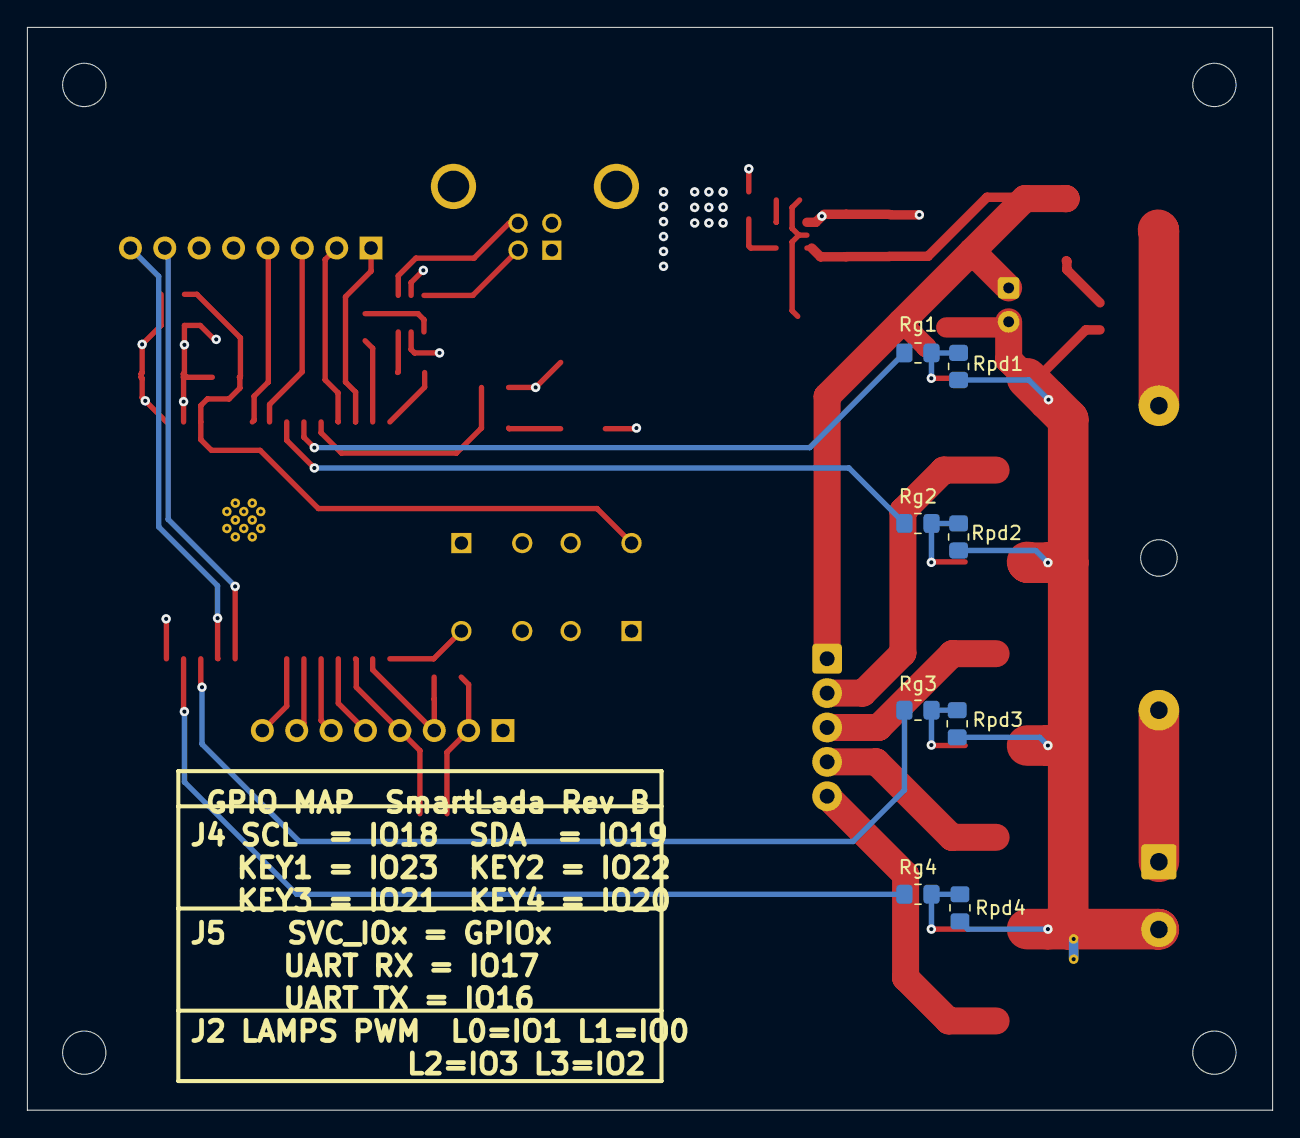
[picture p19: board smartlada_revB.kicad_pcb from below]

Board: 4 copper layers, 92.0 x 80.0 mm, 51 parts (8 on the bottom side), 44 nets.

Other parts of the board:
M3_1, M3_2, M3_3, M3_4: MountingHole_3.2mm_M3

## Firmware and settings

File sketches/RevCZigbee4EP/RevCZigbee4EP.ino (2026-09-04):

// RevCZigbee4EP - multi-endpoint Zigbee bring-up + raw-attribute capture for SmartLada Rev C.
//
// GOAL: prove that ONE ESP32-C6 node exposing FOUR standard DimmableLight endpoints
// (EP10..13) shows up in the "Dom s Alisoy" app as FOUR independently named lamps,
// each with its own on/off + brightness. This is the gating experiment (variant A vs B
// in research/smartlada_alice_zigbee_multi_endpoint_summary.md) that decides whether the
// direct-Zigbee path is viable before touching the product firmware (SmartLadaRevC).
//
// SECOND JOB (reverse engineering): capture the RAW ZCL data Alice sends. We cannot query
// Alice's NLP over Zigbee, but we CAN log every attribute write she pushes to us -- which
// endpoint, which cluster/attribute, ZCL type, decoded + hex value, with a millis()
// timestamp to correlate against the phrase spoken. That reveals exactly how Alice maps
// "yarkost 30 procentov" onto ZCL (which cluster, level scale, transition, on/off order).
//
// HOW THE RAW LOG WORKS: LoggingLight subclasses ZigbeeDimmableLight and overrides the
// public virtual zbAttributeSet(), logging the decoded message before driving the channel.
// Because that override replaces the base handler, on/off + level are re-parsed here (the
// same two attributes the base handles) -- so the lamp still works AND every write is
// logged, including ones the stock light ignores (Groups/Scenes/Identify show up too).
//
// A second, deeper firehose is available with no code change: build with DebugLevel=debug
// (or verbose) and Zigbee.setDebugMode(true) (already called) dumps APSDE-DATA indications
// (per-frame src/dst endpoint, cluster, profile, LQI). See README.md for that capture build.
//
// BENCH (per project owner): RevA carrier board + MuseLab nanoESP32-C6 dev board.
//   - Channel GPIOs use the Rev C routing {1,0,2,3} so the mapping matches the product.
//   - Status WS2812 is the nanoESP32-C6 onboard LED on GPIO8.
//   - BOOT button GPIO9 (active-low): hold 3 s -> Zigbee factory reset + rejoin.
//   - Debug/log over native USB CDC.
// No Wi-Fi / no web on purpose: the C6 shares one 2.4 GHz radio between Wi-Fi and 802.15.4.
//
// [SAFETY] Channels are forced OUTPUT+LOW before anything else. With lamps + 12 V wired:
// common ground board <-> PSU and a fuse in place, exactly as in the main firmware.
//
// Build (nanoESP32-C6 is N16 = 16 MB, no zigbee_16MB scheme exists -> zigbee_8MB + 16M):
//   arduino-cli compile -b "esp32:esp32:esp32c6:ZigbeeMode=ed,PartitionScheme=zigbee_8MB,CDCOnBoot=cdc,FlashSize=16M" sketches/RevCZigbee4EP

#include <Arduino.h>

#ifndef ZIGBEE_MODE_ED
#error "Select Zigbee mode 'Zigbee ED (end device)' (FQBN ...:ZigbeeMode=ed)"
#endif

#include "Zigbee.h"

// Per-endpoint default naming. When 1, each endpoint advertises a distinct, human
// ModelIdentifier (LAMP_NAME below). Some hubs surface ModelIdentifier as the default
// device name, so the four cards arrive distinguishable instead of four identical
// "Lampochka". Whether Alice actually uses it as the card name is EMPIRICAL -> re-pair
// and check. Changing this requires a factory reset (BOOT 3 s) + re-add, which WIPES
// the user-assigned names/group on the hub. When 0, all use one model "RevC-Lamp".
#define DISTINCT_MODEL 1

// ASCII labels (project rule: ASCII only in code/serial). Suggested Cyrillic meaning:
// Turn=povorotnik, Brake=stop-signal, Marker=gabarit, Reverse=zadniy hod.
static const char *LAMP_NAME[4] = {"Turn", "Brake", "Marker", "Reverse"};

// ---------------- channel hardware map (Rev C routing) ------------------
// Index i == logical channel i == physical Faston OUTi. Rev C netlist:
// OUT0=GPIO1, OUT1=GPIO0, OUT2=GPIO2, OUT3=GPIO3 (low-side D4184, active-HIGH gate).
static const uint8_t NUM_CH = 4;
static const uint8_t CH_PINS[NUM_CH] = {1, 0, 2, 3};   // OUT0..OUT3
// Endpoint id per channel. Suggested lamp meaning (assigned by wiring + app naming):
//   EP10 -> turn signal, EP11 -> brake, EP12 -> marker, EP13 -> reverse.
static const uint8_t EP_ID[NUM_CH] = {10, 11, 12, 13};

// ---------------- dev-board pins (MuseLab nanoESP32-C6) ------------------
static const uint8_t NEOPIXEL_PIN = 8;   // onboard WS2812
static const uint8_t BUTTON_PIN = 9;     // BOOT, active-low

// ---------------- PWM (LEDC), same shape as the main firmware -----------
static const uint32_t PWM_FREQ = 20000;  // 20 kHz, flicker-free for these lamps
static const uint8_t PWM_RES_BITS = 10;  // 0..1023
static const uint16_t DUTY_MAX = 1023;
static const uint16_t MIN_DUTY = 20;     // dead-zone floor (bench calibration)
static const float GAMMA = 1.9f;         // perceptual curve chosen on the bench

// Map a Zigbee ZCL level (1..254) to an LEDC duty via gamma + min-duty floor.
static uint16_t levelToDuty(uint8_t level) {
  if (level == 0) return 0;
  float norm = (float)level / 254.0f;
  float curved = powf(norm, GAMMA);
  uint16_t duty = MIN_DUTY + (uint16_t)((DUTY_MAX - MIN_DUTY) * curved + 0.5f);
  return duty > DUTY_MAX ? DUTY_MAX : duty;
}

// Drive one channel and log the resulting effect (paired with the raw-attribute line).
static void applyChannel(uint8_t i, bool state, uint8_t level) {
  uint16_t duty = state ? levelToDuty(level) : 0;
  ledcWrite(CH_PINS[i], duty);
  Serial.printf("[%lu] EP%u ch%u APPLY %s level=%u -> duty=%u\n",
                (unsigned long)millis(), EP_ID[i], i, state ? "ON" : "OFF", level, duty);
}

// Human-readable ZCL cluster name for the raw log.
static const char *clusterName(uint16_t c) {
  switch (c) {
    case 0x0000: return "Basic";
    case 0x0003: return "Identify";
    case 0x0004: return "Groups";
    case 0x0005: return "Scenes";
    case 0x0006: return "OnOff";
    case 0x0008: return "Level";
    case 0x0300: return "Color";
    default:     return "?";
  }
}

// RAW DUMP: one line per incoming attribute write. This is the reverse-engineering core.
static void logAttr(uint8_t ep, const esp_zb_zcl_set_attr_value_message_t *m) {
  uint16_t cl = m->info.cluster;
  uint16_t aid = m->attribute.id;
  uint8_t ty = m->attribute.data.type;
  uint16_t sz = m->attribute.data.size;
  const uint8_t *p = (const uint8_t *)m->attribute.data.value;
  uint32_t v = 0;
  for (uint16_t i = 0; i < sz && i < 4 && p; i++) v |= (uint32_t)p[i] << (8 * i);
  Serial.printf("[%lu] EP%u SET %s(0x%04x) attr=0x%04x type=0x%02x size=%u val=%lu raw=",
                (unsigned long)millis(), ep, clusterName(cl), cl, aid, ty, sz, (unsigned long)v);
  for (uint16_t i = 0; i < sz && p; i++) Serial.printf("%02x ", p[i]);
  Serial.println();
}

// ---------------- four DimmableLight endpoints with raw logging ---------
class LoggingLight : public ZigbeeDimmableLight {
public:
  LoggingLight(uint8_t ep, uint8_t ch) : ZigbeeDimmableLight(ep), _ep(ep), _ch(ch) {}

  // Re-apply the last known state to the channel (used after an identify blink).
  void reapply() { applyChannel(_ch, _state, _level); }

  // Overrides the base handler: log the raw attribute, then re-parse on/off + level so
  // the lamp keeps working. Cannot chain to the (private) base override, so we duplicate
  // the two attributes the base cares about -- intentionally, to keep one code path.
  void zbAttributeSet(const esp_zb_zcl_set_attr_value_message_t *m) override {
    logAttr(_ep, m);
    if (m->info.cluster == ESP_ZB_ZCL_CLUSTER_ID_ON_OFF
        && m->attribute.id == ESP_ZB_ZCL_ATTR_ON_OFF_ON_OFF_ID
        && m->attribute.data.type == ESP_ZB_ZCL_ATTR_TYPE_BOOL) {
      _state = *(bool *)m->attribute.data.value;
    } else if (m->info.cluster == ESP_ZB_ZCL_CLUSTER_ID_LEVEL_CONTROL
               && m->attribute.id == ESP_ZB_ZCL_ATTR_LEVEL_CONTROL_CURRENT_LEVEL_ID
               && m->attribute.data.type == ESP_ZB_ZCL_ATTR_TYPE_U8) {
      _level = *(uint8_t *)m->attribute.data.value;
    }
    applyChannel(_ch, _state, _level);
  }

private:
  uint8_t _ep, _ch;
  bool _state = false;
  uint8_t _level = 255;
};

LoggingLight zbCh0(10, 0), zbCh1(11, 1), zbCh2(12, 2), zbCh3(13, 3);
static LoggingLight *zbCh[NUM_CH] = {&zbCh0, &zbCh1, &zbCh2, &zbCh3};

// Identify: coordinator asks the device to blink. On finish, restore every channel.
static void onIdentify(uint16_t time) {
  static uint8_t on = 1;
  if (time == 0) {
    for (uint8_t i = 0; i < NUM_CH; i++) zbCh[i]->reapply();
    return;
  }
  neopixelWrite(NEOPIXEL_PIN, 60 * on, 60 * on, 60 * on);  // blink white
  on = !on;
}

static void channelsForceLow() {
  for (uint8_t i = 0; i < NUM_CH; i++) {
    digitalWrite(CH_PINS[i], LOW);
    pinMode(CH_PINS[i], OUTPUT);
    digitalWrite(CH_PINS[i], LOW);
  }
}

// Print our own node identity + network coordinates (reverse-engineering context).
static void logNetworkInfo() {
  esp_zb_ieee_addr_t ieee;
  esp_zb_get_long_address(ieee);
  Serial.printf("[%lu] NET short=0x%04x pan=0x%04x channel=%u\n",
                (unsigned long)millis(), esp_zb_get_short_address(),
                esp_zb_get_pan_id(), esp_zb_get_current_channel());
  Serial.print("[NET] ieee (little-endian) = ");
  for (int i = 0; i < 8; i++) Serial.printf("%02x ", ieee[i]);
  Serial.println();
}

void setup() {
  // FORCE-SAFE: lamps off before anything else.
  channelsForceLow();

  Serial.begin(115200);
  delay(50);
  Serial.println("\nRevCZigbee4EP - 4x DimmableLight multi-endpoint + raw ZCL capture");

  for (uint8_t i = 0; i < NUM_CH; i++) {
    if (!ledcAttach(CH_PINS[i], PWM_FREQ, PWM_RES_BITS))
      Serial.printf("LEDC attach FAILED on GPIO%u\n", CH_PINS[i]);
    ledcWrite(CH_PINS[i], 0);
  }

  neopixelWrite(NEOPIXEL_PIN, 0, 0, 0);   // dark
  pinMode(BUTTON_PIN, INPUT_PULLUP);

  // Enable library debug: with a DebugLevel=debug/verbose build this dumps APSDE-DATA
  // indications (per-frame endpoint/cluster/profile/LQI). Harmless on a normal build.
  Zigbee.setDebugMode(true);

  for (uint8_t i = 0; i < NUM_CH; i++) {
    zbCh[i]->onIdentify(onIdentify);
#if DISTINCT_MODEL
    zbCh[i]->setManufacturerAndModel("SmartLada", LAMP_NAME[i]);
#else
    zbCh[i]->setManufacturerAndModel("SmartLada", "RevC-Lamp");
#endif
    Zigbee.addEndpoint(zbCh[i]);
    Serial.printf("Added endpoint EP%u -> ch%u (GPIO%u)\n", EP_ID[i], i, CH_PINS[i]);
  }

  Serial.println("Starting Zigbee (end device)...");
  if (!Zigbee.begin()) {
    Serial.println("Zigbee failed to start! Rebooting in 1 s.");
    delay(1000);
    ESP.restart();
  }

  Serial.println("Joining network (open pairing on the Midi now)...");
  while (!Zigbee.connected()) {
    Serial.print(".");
    neopixelWrite(NEOPIXEL_PIN, 0, 0, 40);   // blue = searching
    delay(250);
    neopixelWrite(NEOPIXEL_PIN, 0, 0, 0);
    delay(250);
  }
  Serial.println("\nJoined Zigbee network.");
  logNetworkInfo();
  neopixelWrite(NEOPIXEL_PIN, 0, 60, 0);     // green = joined
}

void loop() {
  // BOOT hold 3 s -> factory reset + rejoin.
  if (digitalRead(BUTTON_PIN) == LOW) {
    delay(100);  // debounce
    uint32_t t0 = millis();
    while (digitalRead(BUTTON_PIN) == LOW) {
      delay(50);
      if (millis() - t0 > 3000) {
        Serial.println("Factory reset -> rebooting.");
        neopixelWrite(NEOPIXEL_PIN, 60, 0, 0);  // red flash
        delay(500);
        Zigbee.factoryReset();  // reboots
      }
    }
  }

  // Reflect link state on the NeoPixel: dim green when connected, blue blink when not.
  static uint32_t last = 0;
  if (millis() - last > 500) {
    last = millis();
    if (Zigbee.connected()) {
      neopixelWrite(NEOPIXEL_PIN, 0, 8, 0);   // idle dim green
    } else {
      static bool b = false;
      b = !b;
      neopixelWrite(NEOPIXEL_PIN, 0, 0, b ? 40 : 0);
    }
  }
  delay(20);
}

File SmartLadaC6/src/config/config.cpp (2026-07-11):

#include "config.h"

#include <stdio.h>
#include <stdlib.h>
#include <string.h>

namespace config {

// Lamps: R10W 12V BA15S on all 4 channels (10 W). power_w is UI-only.
// ESP32-C6: boot-safe pins. Forbidden — strapping (GPIO4/5/8/9/15),
// native USB (GPIO12/13), SPI flash (GPIO24..30) and NeoPixel (GPIO8).
const ChannelDef CHANNEL_DEFS[channels::NUM_CHANNELS] = {
    {"stop", "Stop", 10, 0},
    {"reverse", "Reverse", 10, 1},
    {"turn", "Turn", 10, 2},
    {"marker", "Marker", 10, 3},
};

// Defaults = calibration taken on the bench 2026-07-10 (R10W, Ecola 12V/80W).
// gamma range widened to 1.0..2.5 for tuning; 1.9 chosen on the bench.
static constexpr float GAMMA_MIN = 1.0f, GAMMA_MAX = 2.5f, GAMMA_DEFAULT = 1.9f;
// Working PWM range (LEDC can do up to 78 kHz at 10 bit in hardware, but above
// 30 kHz makes no sense with these lamps — ceiling reduced to 30 kHz).
static constexpr uint32_t FREQ_MIN = 10, FREQ_MAX = 30000, FREQ_DEFAULT = 30000;
static constexpr uint16_t SOFT_START_MAX = 5000, SOFT_START_DEFAULT = 30;
static constexpr uint16_t MIN_DUTY_DEFAULT = 20;  // R10W filament glow threshold
// Cap removed: on this bench 100% is verified safe (40 W out of the 80 W PSU).
static constexpr uint8_t CAP_DEFAULT = 100;
// Animation test-mode timings (ms): common range + defaults (former constants).
static constexpr uint16_t ANIM_MIN = 100, ANIM_MAX = 10000;
static constexpr uint16_t CHASE_DEFAULT = 200, SEQ_DEFAULT = 400;
static constexpr uint16_t PULSE_DEFAULT = 2000, ALT_DEFAULT = 450;

void setDefaults(Config& cfg) {
  cfg.pwm_freq_hz = FREQ_DEFAULT;
  cfg.max_duty_cap_pct = CAP_DEFAULT;
  cfg.calib = {GAMMA_DEFAULT, MIN_DUTY_DEFAULT, channels::DUTY_MAX, SOFT_START_DEFAULT};
  for (uint8_t i = 0; i < channels::NUM_CHANNELS; i++)
    cfg.gpio[i] = CHANNEL_DEFS[i].default_gpio;
  cfg.chase_ms = CHASE_DEFAULT;
  cfg.seq_ms = SEQ_DEFAULT;
  cfg.pulse_ms = PULSE_DEFAULT;
  cfg.alt_ms = ALT_DEFAULT;
}

static float clampf(float v, float lo, float hi) {
  return v < lo ? lo : (v > hi ? hi : v);
}

static uint16_t clampu(uint32_t v, uint16_t lo, uint16_t hi) {
  return v < lo ? lo : (v > hi ? hi : (uint16_t)v);
}

void clamp(Config& cfg) {
  if (cfg.pwm_freq_hz < FREQ_MIN) cfg.pwm_freq_hz = FREQ_MIN;
  else if (cfg.pwm_freq_hz > FREQ_MAX) cfg.pwm_freq_hz = FREQ_MAX;
  if (cfg.max_duty_cap_pct > 100) cfg.max_duty_cap_pct = 100;
  channels::Calib& c = cfg.calib;
  c.gamma = clampf(c.gamma, GAMMA_MIN, GAMMA_MAX);
  c.min_duty = clampu(c.min_duty, 0, channels::DUTY_MAX);
  c.max_duty = clampu(c.max_duty, 0, channels::DUTY_MAX);
  if (c.min_duty > c.max_duty) c.min_duty = c.max_duty;
  c.soft_start_ms = clampu(c.soft_start_ms, 0, SOFT_START_MAX);
  cfg.chase_ms = clampu(cfg.chase_ms, ANIM_MIN, ANIM_MAX);
  cfg.seq_ms = clampu(cfg.seq_ms, ANIM_MIN, ANIM_MAX);
  cfg.pulse_ms = clampu(cfg.pulse_ms, ANIM_MIN, ANIM_MAX);
  cfg.alt_ms = clampu(cfg.alt_ms, ANIM_MIN, ANIM_MAX);
}

size_t toJson(const Config& cfg, char* buf, size_t buflen) {
  const channels::Calib& c = cfg.calib;
  int n = snprintf(buf, buflen,
                   "{\n  \"pwm_freq_hz\": %u,\n  \"max_duty_cap_pct\": %u,\n"
                   "  \"gamma\": %.2f,\n  \"min_duty\": %u,\n  \"max_duty\": %u,\n"
                   "  \"soft_start_ms\": %u,\n  \"chase_ms\": %u,\n  \"seq_ms\": %u,\n"
                   "  \"pulse_ms\": %u,\n  \"alt_ms\": %u\n}\n",
                   (unsigned)cfg.pwm_freq_hz, cfg.max_duty_cap_pct, (double)c.gamma,
                   c.min_duty, c.max_duty, c.soft_start_ms, cfg.chase_ms, cfg.seq_ms,
                   cfg.pulse_ms, cfg.alt_ms);
  if (n < 0 || (size_t)n >= buflen) return 0;
  return (size_t)n;
}

// Finds "key": <number>. Minimal parser for our flat schema (all values are
// numbers). Returns false if the key is missing or not followed by a number.
static bool findNum(const char* json, const char* key, double& out) {
  char pat[24];
  snprintf(pat, sizeof(pat), "\"%s\"", key);
  size_t patlen = strlen(pat);
  const char* k = json;
  while ((k = strstr(k, pat)) != nullptr) {
    const char* c = k + patlen;
    while (*c == ' ' || *c == '\t' || *c == '\r' || *c == '\n') c++;
    if (*c == ':') {
      char* ep = nullptr;
      double v = strtod(c + 1, &ep);
      if (ep != c + 1) {
        out = v;
        return true;
      }
      return false;
    }
    k += patlen;
  }
  return false;
}

static double clampd(double v, double lo, double hi) {
  return v < lo ? lo : (v > hi ? hi : v);
}
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

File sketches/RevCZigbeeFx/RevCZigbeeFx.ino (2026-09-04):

// RevCZigbeeFx - Zigbee 4 lamps + a 5th "Fara" color device (master + effects).
//
// Extends RevCZigbee4EP with the chosen final architecture:
//   EP10..13  ZigbeeDimmableLight   -> 4 individual lamps (turn/brake/marker/reverse)
//   EP14      ZigbeeColorDimmableLight "Fara" -> master brightness + effect selector by color
//
// Effect selection by color (hue quantized into zones; Alice preset swatches act as the
// discrete palette). White/low-saturation = no effect (lamps show individually):
//   red -> blink (turn),   green -> chase,   blue -> fade/breathe
//
// Priority / compositor (per loop):
//   master = Fara.on ? Fara.level/254 : 1.0            (Fara off = per-lamp passthrough)
//   effect active (Fara.on && saturated): frame = animation; else frame = individual lamps
//   out[i] = frame[i] * master  ->  slew (soft-start)  ->  gamma  ->  LEDC
// Soft-start smooths Alice's coarse ~15-unit/100ms brightness steps AND power-on inrush in
// normal mode (SOFT_NORMAL_MS); effects use a short slew (SOFT_FX_MS) so blinks stay crisp.
//
// BENCH: RevA board + MuseLab nanoESP32-C6. Channel GPIOs = Rev C routing {1,0,2,3}.
// Status WS2812 GPIO8. BOOT GPIO9 hold 3 s = factory reset. Raw ZCL logging kept.
//
// Build: arduino-cli compile -b "esp32:esp32:esp32c6:ZigbeeMode=ed,PartitionScheme=zigbee_8MB,CDCOnBoot=cdc,FlashSize=16M" sketches/RevCZigbeeFx

#include <Arduino.h>
#ifndef ZIGBEE_MODE_ED
#error "Select Zigbee mode 'Zigbee ED (end device)' (FQBN ...:ZigbeeMode=ed)"
#endif
#include "Zigbee.h"
#include <math.h>

#define DISTINCT_MODEL 1  // distinct ModelIdentifier per endpoint (readable default names)

// ---------------- hardware ----------------
static const uint8_t NUM_CH = 4;
static const uint8_t CH_PINS[NUM_CH] = {1, 0, 2, 3};              // OUT0..OUT3 (Rev C)
static const uint8_t EP_ID[NUM_CH] = {10, 11, 12, 13};
static const char *LAMP_NAME[NUM_CH] = {"Turn", "Brake", "Marker", "Reverse"};
static const uint8_t FARA_EP = 14;
static const uint8_t NEOPIXEL_PIN = 8;
static const uint8_t BUTTON_PIN = 9;

// ---------------- PWM ----------------
static const uint32_t PWM_FREQ = 20000;
static const uint8_t PWM_RES_BITS = 10;
static const uint16_t DUTY_MAX = 1023;
static const uint16_t MIN_DUTY = 20;
static const float GAMMA = 1.9f;

// ---------------- soft-start ----------------
static const uint16_t SOFT_NORMAL_MS = 150;  // smooths Alice's stepped brightness + inrush
static const uint16_t SOFT_FX_MS = 20;        // effects: just tame inrush, keep edges crisp

// ---------------- effect selection ----------------
static const uint8_t SAT_THRESH = 40;         // saturation below this = white = no effect
enum Effect { FX_NONE, FX_BLINK, FX_CHASE, FX_FADE };

// ---------------- shared state (written by Zigbee callbacks, read by loop) ----------------
struct Lamp { bool on; uint8_t bri; };        // bri = Zigbee level 0..254
static volatile Lamp g_lamp[NUM_CH] = {{false, 254}, {false, 254}, {false, 254}, {false, 254}};
static volatile bool    g_faraOn = false;
static volatile uint8_t g_master = 254, g_hue = 0, g_sat = 0;

// ---------------- endpoints ----------------
class LoggingLight : public ZigbeeDimmableLight {
public:
  LoggingLight(uint8_t ep, uint8_t ch) : ZigbeeDimmableLight(ep), _ep(ep), _ch(ch) {}
  void zbAttributeSet(const esp_zb_zcl_set_attr_value_message_t *m) override {
    uint16_t cl = m->info.cluster, aid = m->attribute.id;
    if (cl == ESP_ZB_ZCL_CLUSTER_ID_ON_OFF && aid == ESP_ZB_ZCL_ATTR_ON_OFF_ON_OFF_ID
        && m->attribute.data.type == ESP_ZB_ZCL_ATTR_TYPE_BOOL) {
      g_lamp[_ch].on = *(bool *)m->attribute.data.value;
    } else if (cl == ESP_ZB_ZCL_CLUSTER_ID_LEVEL_CONTROL
               && aid == ESP_ZB_ZCL_ATTR_LEVEL_CONTROL_CURRENT_LEVEL_ID
               && m->attribute.data.type == ESP_ZB_ZCL_ATTR_TYPE_U8) {
      g_lamp[_ch].bri = *(uint8_t *)m->attribute.data.value;
    }
    Serial.printf("[%lu] EP%u ch%u cl=0x%04x attr=0x%04x -> on=%d bri=%u\n",
                  (unsigned long)millis(), _ep, _ch, cl, aid, g_lamp[_ch].on, g_lamp[_ch].bri);
  }
private:
  uint8_t _ep, _ch;
};

LoggingLight zbCh0(10, 0), zbCh1(11, 1), zbCh2(12, 2), zbCh3(13, 3);
static LoggingLight *zbCh[NUM_CH] = {&zbCh0, &zbCh1, &zbCh2, &zbCh3};
ZigbeeColorDimmableLight zbFara(FARA_EP);

// Fara color/level/power -> effect + master (decoded HSV callback).
static void onFaraHsv(bool state, uint8_t hue, uint8_t sat, uint8_t value) {
  g_faraOn = state;
  g_hue = hue;
  g_sat = sat;
  g_master = value;
  Serial.printf("[%lu] FARA on=%d hue=%u sat=%u val=%u\n",
                (unsigned long)millis(), state, hue, sat, value);
}

// ---------------- effects (fill 0..254 per channel) ----------------
static Effect hueToEffect(uint8_t hue, uint8_t sat) {
  if (sat < SAT_THRESH) return FX_NONE;               // white-ish = normal mode
  if (hue < 43 || hue >= 213) return FX_BLINK;         // red
  if (hue < 128) return FX_CHASE;                      // green
  return FX_FADE;                                       // blue
}

static void effectFrame(Effect fx, uint32_t now, uint8_t out[NUM_CH]) {
  switch (fx) {
    case FX_BLINK: {                                    // all blink together ~1.5 Hz
      uint8_t v = ((now / 340) & 1) ? 254 : 0;
      for (uint8_t i = 0; i < NUM_CH; i++) out[i] = v;
      break;
    }
    case FX_CHASE: {                                    // running light, 150 ms/step
      uint8_t step = (now / 150) % NUM_CH;
      for (uint8_t i = 0; i < NUM_CH; i++) out[i] = (i == step) ? 254 : 0;
      break;
    }
    case FX_FADE: {                                     // breathe, ~3 s period
      float ph = (float)(now % 3000) / 3000.0f * 2.0f * (float)M_PI;
      uint8_t v = (uint8_t)((sinf(ph) * 0.5f + 0.5f) * 254.0f);
      for (uint8_t i = 0; i < NUM_CH; i++) out[i] = v;
      break;
    }
    default:
      for (uint8_t i = 0; i < NUM_CH; i++) out[i] = 0;
  }
}

// ---------------- output pipeline: level 0..254 -> gamma/min -> duty ----------------
static uint16_t levelToDuty(uint8_t level) {
  if (level == 0) return 0;
  float curved = powf((float)level / 254.0f, GAMMA);
  uint16_t d = MIN_DUTY + (uint16_t)((DUTY_MAX - MIN_DUTY) * curved + 0.5f);
  return d > DUTY_MAX ? DUTY_MAX : d;
}

static float s_actual[NUM_CH] = {0, 0, 0, 0};
static uint32_t s_lastMs = 0;
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

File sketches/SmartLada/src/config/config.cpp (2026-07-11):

#include "config.h"

#include <stdio.h>
#include <stdlib.h>
#include <string.h>

namespace config {

const ChannelDef CHANNEL_DEFS[channels::NUM_CHANNELS] = {
    {"stop", "Stop", 21, 4, 300},
    {"reverse", "Reverse", 21, 5, 300},
    // GPIO15: not 12/14 (I2C OLED on the HW-364A board); the board's pulldown holds
    // the channel off at boot. Nothing external must pull GPIO15 high at startup!
    {"turn", "Turn", 21, 15, 300},
    {"marker", "Marker", 5, 13, 200},
};

static constexpr float GAMMA_MIN = 1.8f, GAMMA_MAX = 2.6f, GAMMA_DEFAULT = 2.2f;
static constexpr uint16_t FREQ_MIN = 100, FREQ_MAX = 1000, FREQ_DEFAULT = 150;
static constexpr uint16_t SOFT_START_MAX = 1000;
static constexpr uint8_t CAP_DEFAULT = 60;

void setDefaults(Config& cfg) {
  cfg.pwm_freq_hz = FREQ_DEFAULT;
  cfg.max_duty_cap_pct = CAP_DEFAULT;
  for (uint8_t i = 0; i < channels::NUM_CHANNELS; i++) {
    cfg.ch[i].gpio = CHANNEL_DEFS[i].default_gpio;
    cfg.ch[i].calib = {GAMMA_DEFAULT, 0, channels::DUTY_MAX,
                       CHANNEL_DEFS[i].default_soft_start_ms};
  }
}

static float clampf(float v, float lo, float hi) {
  return v < lo ? lo : (v > hi ? hi : v);
}

static uint16_t clampu(uint32_t v, uint16_t lo, uint16_t hi) {
  return v < lo ? lo : (v > hi ? hi : (uint16_t)v);
}

void clamp(Config& cfg) {
  cfg.pwm_freq_hz = clampu(cfg.pwm_freq_hz, FREQ_MIN, FREQ_MAX);
  if (cfg.max_duty_cap_pct > 100) cfg.max_duty_cap_pct = 100;
  for (uint8_t i = 0; i < channels::NUM_CHANNELS; i++) {
    channels::Calib& c = cfg.ch[i].calib;
    c.gamma = clampf(c.gamma, GAMMA_MIN, GAMMA_MAX);
    c.min_duty = clampu(c.min_duty, 0, channels::DUTY_MAX);
    c.max_duty = clampu(c.max_duty, 0, channels::DUTY_MAX);
    if (c.min_duty > c.max_duty) c.min_duty = c.max_duty;
    c.soft_start_ms = clampu(c.soft_start_ms, 0, SOFT_START_MAX);
  }
}

size_t toJson(const Config& cfg, char* buf, size_t buflen) {
  size_t off = 0;
  int n = snprintf(buf, buflen,
                   "{\n  \"pwm_freq_hz\": %u,\n  \"max_duty_cap_pct\": %u,\n"
                   "  \"channels\": {\n",
                   cfg.pwm_freq_hz, cfg.max_duty_cap_pct);
  if (n < 0 || (size_t)n >= buflen) return 0;
  off = (size_t)n;
  for (uint8_t i = 0; i < channels::NUM_CHANNELS; i++) {
    const channels::Calib& c = cfg.ch[i].calib;
    n = snprintf(buf + off, buflen - off,
                 "    \"%s\": { \"gpio\": %u, \"gamma\": %.2f, \"min_duty\": %u,"
                 " \"max_duty\": %u, \"soft_start_ms\": %u }%s\n",
                 CHANNEL_DEFS[i].key, cfg.ch[i].gpio, (double)c.gamma, c.min_duty,
                 c.max_duty, c.soft_start_ms,
                 (i + 1 < channels::NUM_CHANNELS) ? "," : "");
    if (n < 0 || off + (size_t)n >= buflen) return 0;
    off += (size_t)n;
  }
  n = snprintf(buf + off, buflen - off, "  }\n}\n");
  if (n < 0 || off + (size_t)n >= buflen) return 0;
  return off + (size_t)n;
}

// Finds "key": <number> in the range [p, end). Minimal parser for our fixed schema
// (all values are numbers, no string escaping).
static bool findNum(const char* p, const char* end, const char* key, double& out) {
  char pat[24];
  snprintf(pat, sizeof(pat), "\"%s\"", key);
  size_t patlen = strlen(pat);
  const char* k = p;
  while ((k = strstr(k, pat)) != nullptr && k < end) {
    const char* c = k + patlen;
    while (c < end && (*c == ' ' || *c == '\t' || *c == '\r' || *c == '\n')) c++;
    if (c < end && *c == ':') {
      char* ep = nullptr;
      double v = strtod(c + 1, &ep);
      if (ep != c + 1) {
        out = v;
        return true;
      }
      return false;
    }
    k += patlen;
  }
  return false;
}

// Finds a channel section's { ... } object by its key. Channel objects contain no
// nested braces (values are only numbers), so the first '}' is the end.
static bool findSection(const char* json, const char* key, const char** beg,
                        const char** end) {
  char pat[24];
  snprintf(pat, sizeof(pat), "\"%s\"", key);
  const char* k = strstr(json, pat);
  if (!k) return false;
  const char* o = strchr(k, '{');
  if (!o) return false;
  const char* c = strchr(o, '}');
  if (!c) return false;
  *beg = o;
  *end = c;
  return true;
}

static double clampd(double v, double lo, double hi) {
  return v < lo ? lo : (v > hi ? hi : v);
}
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

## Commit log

2026-07-05 SmartLada v0.1 — калибровочный стенд PWM на ESP8266
    Bring-up 4 ламп накаливания ВАЗ-2106 через модули D4184 (low-side PWM).
    Модульная структура: тонкий .ino + слои в src/. Слои channels/ и config/
    переносимы на ESP32-C6 (чистый C++, без Arduino/ESP8266-зависимостей);
    platform_pwm/ и web/ — временные для стенда.
2026-07-05 OLED-дисплей HW-364A + кнопка FLASH; CH2 перенесён на GPIO15
    Новый слой src/display/ (SSD1306 128x64, I2C SDA=GPIO14/SCL=GPIO12,
    Adafruit SSD1306): 3 страницы — статус AP/heap/PWM/кап/loop-rate,
    каналы (%/duty), калибровка. Кнопка FLASH (GPIO0) листает страницы.
    GPIO12/14 заняты дисплеем, поэтому CH2 "Поворот" переехал на GPIO15 (D8):
    pulldown платы держит канал закрытым при boot; внешний pullup на линии
    недопустим (см. README).
2026-07-05 Калибровка с реальных ламп фонаря (прогон 2026-07-06)
    Стенд отработал: 100 vs 1000 Гц глазами неразличимы (инерция нитей),
    min_duty 50/100, gamma 2.0/2.2. Фонарь переполюсован: общая плата = +12,
    индивидуальные контакты патронов = раздельные минусы на стоки D4184.
2026-07-05 Доки: прототип рабочий, схема с общим плюсом проверена на железе
    README: статус прототипа, переписана схема подключения (общая плата
    фонаря = +12, индивидуальные контакты патронов = раздельные выводы на
    стоки D4184), результат по джиттеру (не наблюдался, 100 Гц).
    calibration/README: обоснование soft_start_ms=30 — бросок опасен БП и
    предохранителю, а не лампе; валидировано прогоном.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
2026-07-11 Reorganize into monorepo; add ESP32-C6 firmware (SmartLadaC6, fw 0.7.0-c6)
    Move the ESP8266 bench (was repo root) into SmartLada/ and add the new
    ESP32-C6 firmware in SmartLadaC6/ plus project context docs and a root README.
    SmartLadaC6 (fw 0.7.0-c6):
    - Hardware PWM via LEDC; Wi-Fi AP + dark web UI (master, modes, calibration)
    - BOOT button: short press cycles modes, hold = smooth master-brightness dimmer
    - Master brightness as a global duty multiplier across all modes
    - 5 PWM test modes (TURN/CHASE/SEQ/PULSE/ALT) with web-editable timings
    - DRIVE mode rewritten as a finite-state machine (logical randomized timeline)
    - NeoPixel status + gamma-corrected brightness overlay
    - Docs: nanoESP32-C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
    [SmartLada.ino, SmartLadaC6.ino, channels.cpp]
2026-07-11 Translate project to English; restructure to a single main project
    - Translate all firmware code comments, web UI strings, Serial logs, and firmware
    docs (SmartLadaC6 + the ESP8266 bench) to English. The 4 root context/planning
    docs stay in Russian on purpose.
    - Make SmartLadaC6 the main project; move the ESP8266 bench to sketches/SmartLada/.
    - Reframe the root README around SmartLadaC6; fix cross-links.
    [SmartLada.ino, SmartLadaC6.ino, channels.cpp]
2026-07-12 Add ThermalTest bench: 2x DS18B20 on ESP8266 (HW-364A)
    Standalone validation sketch for the thermal-monitoring feature, ahead of
    porting the thermal/rtc/log layers into SmartLadaC6. Does not drive lamps/PWM.
    - thermal: 2x DS18B20 on one 1-Wire bus (GPIO13), non-blocking 12-bit, ROM->point map
    - rtc + log: phone time-sync (POST /api/time) and cineink-style LittleFS event log
    - stats: running min/max/avg + recent-sample ring buffer
    - display: 5 OLED pages (temps/status/ROMs/history/min-max-avg), yellow-zone aware
    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
2026-07-20 Add SmartLada Rev A carrier board: KiCad project and design docs
    Custom 80x65 mm two-layer carrier that replaces the 4x D4184 module bank.
    The nanoESP32-C6 devboard is kept as-is and wired through an 8-pin header
    (J3) on flying leads; firmware is unchanged (GPIO0..3 PWM, GPIO8 WS2812,
    GPIO9 button).
    Board content: 12 V input with T4A fuse and AOD4185 reverse-polarity FET,
    TPS54202 buck to 5 V feeding the devboard through an SS14 so USB always
    wins, and four low-side AOD4184A channels with 100R gate resistors and
    mandatory 100k gate pull-downs.
    State: ERC 0/0, DRC 0 violations / 0 unconnected / 0 footprint errors.
    All signals on F.Cu, leaving the B.Cu GND pour as one uninterrupted
    island ov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
    [smartlada_revA.kicad_pcb, smartlada_revA.kicad_sch]
2026-07-20 ThermalTest: add bus diagnostics for the DS18B20 -127 investigation
    The root cause of the high-temperature -127 dropouts is still unknown and
    two sensors have already been swapped out, so add instrumentation rather
    than guesses:
    - thermal::rawC() and thermal::errorCount() expose the last raw getTempC
    (which may legitimately be -127/85) and the number of invalid reads
    since begin(), so glitches are counted instead of being hidden behind
    the last-good value.
    - thermal::dumpScratch() prints the 9-byte scratchpad of every device on
    the bus and flags the genuine-DS18B20 reserved-byte signature
    (sp[5]=0xFF, sp[7]=0x10, 12-bit config 0x7F) — a clone check, since a
    counterfeit batch i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
    [ThermalTest.ino]
2026-07-20 Make the KiCad project self-contained: vendor libraries into the repo
    The custom symbols and footprints (AOD4184A, AOD4185, the Taiyo Yuden and
    TDK capacitors, the CDRH6D28 inductor) were registered only in KiCad's
    global library tables, with absolute paths under ~/Documents/KiCad. A
    clone on any other machine could not resolve them, and local fixes to
    those libraries — the 3D model references and L1's repaired courtyard —
    lived outside version control entirely.
    - custom_pcb/libs/Vendor.kicad_sym 5 symbols
    - custom_pcb/libs/Vendor.pretty/ 10 footprints
    - project-level sym-lib-table and fp-lib-table using ${KIPRJMOD}/../libs
    The schematic reaches the same symbol file under two nic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
2026-08-18 Add Rev B/Rev C boards + firmware; repo hygiene
    PCB: Rev C (product) routed/verified/gerbers/mechanical, ordered; Rev B
    (learning 4-layer) + docs; Rev A updates; Vendor lib new footprints
    (Faston TE_1217754-1, WS2812B, ESP32-C6-WROOM-1-N16, USB-B, tactile) + 3D shapes.
    Firmware: SmartLadaRevC (fork of RevB with Rev C pin remap, builds;
    PD-gating pending -> CODE_HANDOFF.md); SmartLadaRevB (modular UI, effects, fonts).
    Docs/tooling: Rev C verification/procurement/handoffs, fab READMEs, KiCad
    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
    [260721_platan_basket.xls, 260721_platan_basket_кириллица.xlsx, 260812_smartlada_revC_3D.step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]
2026-09-04 SmartLada Rev C firmware v1.0: hardware bring-up + Zigbee integration
    Rev C board fully brought up in hardware (USB-C PD 12V + TPS54202 3.3V buck,
    OLED, buttons, 4 PWM lamp channels validated on a real 35W load). Zigbee control
    merged into the main firmware: 4 lamp endpoints (EP10-13) + a "Fara" color
    endpoint (EP14) for master brightness + effect selection by hue, unified with the
    local OLED menu through config::s (last-writer-wins).
    - config: +lampOn/faraOn (MAGIC 0x57); fx::compute compositor + passthrough
    - src/net/zigbee: 5 endpoints -> config::s; group-vs-lone-touch heuristics
    - channels: LEDC RES_BITS=10 (C6 LEDC clocks from 40MHz; 20kHz needs <=10-bit)
    - menu: Zigbee factory-reset +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
    [RevCMqttTls.ino, RevCZigbee4EP.ino, RevCZigbeeFx.ino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]
2026-09-04 docs: make Rev C the primary firmware; rewrite READMEs
    - Root README rewritten: SmartLadaRevC (Rev C board, USB-C PD, Zigbee) is now
    the main firmware; hardware + build (Zigbee FQBN) updated; add a Lineage
    section (ESP8266 bench -> SmartLadaC6 -> Rev B -> Rev C).
    - New SmartLadaRevC/README.md: features, layer architecture, control model,
    pin map (ground truth), build/flash notes, status + roadmap.
    - CODE_HANDOFF.md reduced to a redirect (superseded by README + SESSION_HANDOFF).
    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
2026-09-06 SmartLadaRevC fw 1.0.10: fix OTA entry, color pairing, dimming; review Wave 1
    Codex review items R1-R6, plus three defects found on hardware.
    Found on hardware:
    - BLE OTA mode was unreachable. The RTC request flag used RTC_DATA_ATTR, whose
    section the bootloader restores from the image on every reset, so the menu's
    ESP.restart() cleared it before setup() could see it. Flag and boot counter
    move to RTC_NOINIT_ATTR behind a magic word; the boot counter now actually
    counts reboots, which is what it was added for.
    - One "move to hue and saturation" reaches the device as two attribute writes,
    and the library fires the HSV callback on each, filling the missing half from
    the attribute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
    [SmartLadaRevC.ino, bleota.cpp, buttons.cpp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]
2026-09-06 SmartLadaRevC fw 1.0.11: restore soft start for effects, EP14 effect-only, restore-on-boot
    Verified on hardware.
    Soft start regression, introduced by this branch: loop() had started overriding
    the channel time constant per mode (a short one for effects, so animations stayed
    crisp). Before that, the tau set once in setup() from Lamp Setup applied to
    everything, which is what gave Turn its ramp instead of snapping 0-100-0. Drop
    the per-mode override and the master easing that was papering over it; one time
    constant again shapes both effect edges and stepped brightness. Effects do not
    smear at the soft start values in use (50-100 ms).
    R7, power-on policy is RESTORE: config::tick() watches the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
    [SmartLadaRevC.ino, config.cpp, zigbee.cpp]
2026-09-06 SmartLadaRevC fw 1.0.19: rework Chase, fix effect param count, Timings scrolling
    Chase is rebuilt around a trigger clock and a per-lamp envelope. The old shape made
    Fade a fraction of Step, so it could never outlast one slot: Step 0.2 s with Fade 2 s
    just clamped and the lamp still went dark in 0.2 s. Now every Step triggers a lamp
    that runs its own Fade In -> On -> Fade Out, free to outlive later triggers -- that
    overlap is what reads as a snake rather than a row of separate blinks. Step and On
    are separate knobs so "lit for half a second" and "next one in 0.2 s" can both be
    expressed. Random picks the next lamp instead of walking in order, never repeating
    the one jus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
    [SmartLadaRevC.ino]
2026-09-06 docs: correct the Rev C control model and state the workaround's limits
    README described EP14's white as a second group dimmer fanning its level into every
    lamp. That behaviour was removed: off and white both mean "no effect", and EP14's
    level is always the effect brightness. Left in place the docs would have invited the
    next session to restore the very thing that flattened per-channel levels on each
    color change. Added why it went, where group and per-lamp brightness actually live,
    the single-time-constant rule, Chase's trigger/envelope model and restore-on-power-on.
    The Yandex workaround section now carries its open limits rather than only its
    evidence: it chains an internal Arduino-ESP32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
2026-09-06 SmartLadaRevC fw 1.0.20: close the two holes in the EP14 color workaround
    Coordinators send Configure Reporting when the device joins, which re-arms exactly the
    hue/saturation reports the workaround stops -- and the old code only stopped them on an
    incoming Color Control command. Between joining and the user's next color command the
    automatic report was armed again, so the preset-replacement bug could come back after
    every reboot until the color was touched. Confirmed on hardware: the new path fires on
    the first boot after flashing. Configure Reporting is serviced on the way OUT of the APS
    hook, since stopping before the stack applies it would simply be undone.
    Installing the hook needs the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
    [zigbee.cpp]
2026-09-06 SmartLadaRevC fw 1.0.21: decode every C6 reset reason; record the BLE OTA regression
    ESP_RST_USB, JTAG, EFUSE, PWR_GLITCH and CPU_LOCKUP all exist on the C6 and were all
    falling through to "UNKNOWN", which made a genuine fault during a transfer impossible
    to tell apart from a host-side reset. Decoding them immediately showed that opening the
    USB serial port resets the board -- so every serial capture started here rebooted it,
    and watching the log during a BLE session is not possible at all: the port open kicks
    the device out of OTA mode. That is now written down as a trap.
    The handoff also records what is not solved: BLE OTA ran 1.1 MB at 25.7 KB/s on its
    first outing, then 9.9, then stalle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
    [power.cpp]
2026-09-06 docs: BLE OTA is power-dependent, and R6's disconnect path is verified
    The BLE transfer degradation traced to the supply, not the radio: on USB 5 V it drops to
    ~6.5 KB/s and stalls a third of the way in, on PD 12 V the same image goes through at
    19-23 KB/s. Recorded as an operating instruction rather than an open problem, since it
    reproduces cleanly in both directions.
    With a transfer finally reaching the end, the last unverified R6 path was checked: the
    client drops the link immediately after FINISH and the board still commits and boots the
    new image, confirmed by SmartLada disappearing from the air afterwards.
    README had no BLE OTA section at all despite the feature and its host tool shi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
2026-09-06 SmartLadaRevC fw 1.1.0: Wi-Fi, web UI and a test plan for the bench week
    The C6 libraries this build already links are compiled with CONFIG_ESP_WIFI_ENABLED,
    SOFTAP support and CONFIG_SW_COEXIST_ENABLE alongside Zigbee, so both radios may run at
    once; whether that is stable in practice is what section 7 of the test plan is for. Wi-Fi
    stays off until switched on in the menu, which doubles as the fallback the plan always
    called for.
    wifinet: station when credentials are saved, provisioning AP otherwise or after a join
    times out, with the station retried in the background so a rebooting router reclaims the
    device on its own. Credentials live in their own NVS keys rather than the Settings blob,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
    [SmartLadaRevC.ino, web.cpp, wifinet.cpp]
2026-09-06 SmartLadaRevC fw 1.2.0: one radio at a time, and a web UI that mirrors the device
    Coexistence was compiled in and both stacks linked, but a phone could not join the access
    point while the Zigbee stack was up. So the radio is now a choice rather than a pair:
    radio::mode() owns it, the choice is persisted, and switching reboots -- the Arduino Zigbee
    stack has no clean shutdown and Wi-Fi must come up before the band is claimed. Everything
    that touches the Zigbee stack checks whether it actually started this boot, since a disabled
    boot would otherwise query a stack that was never there.
    Wi-Fi is access-point first, which is what a car actually needs: no network to join, so the
    lamp hosts its ow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
    [SmartLadaRevC.ino, web.cpp]
2026-09-06 docs: bring README and the test plan up to the 1.2.0 model
    These edits belong with c2a88f3, whose message already described them: the patch that
    applied them aborted on a text mismatch after the code had been staged, so the commit
    went out with the code alone. Nothing in the tree was wrong, but the documentation still
    described the previous model.
    README: the radio is a choice rather than a pair, Wi-Fi is access-point first with an
    editable identity, and the static master is a ceiling rather than absent. The compositor
    section had said "no master scaling", which is now exactly backwards.
    TEST_PLAN: the coexistence section became a radio-switching section, since there is
    nothing left to coe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
2026-09-23 SmartLadaRevC: UI_TFT bench variant with a 2.4" ST7789 + EC11 encoder
    A build flag (-DUI_TFT=1) swaps the SSD1315 + 4 keys for the TFT/encoder
    module; default builds are unchanged.
    - display: the menu still draws into the 128x64 SSD1306 buffer; display()
    fits it to the portrait panel (240x120, nearest-neighbour) and streams
    only the rectangle that changed, at 40 MHz. The panel needs real CS and
    RES, so they come from the J8 debug UART (IO17/IO16).
    - input: EC11 via PCNT stands in for UP/DOWN, PUSH short = SEL, hold =
    BACK. CW = UP so values rise; menu::update swaps list navigation so CW
    also steps lists forward.
    - sketches/RevCTftEnc and RevCTftDiag: bring-up and diagnostics.
    - do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
    [RevCTftDiag.ino, RevCTftEnc.ino, buttons.cpp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]
2026-09-24 SmartLadaRevC: menu screen capture from the frame buffer, and the site handoff
    - SCREEN_DUMP build flag (default off): every changed 128x64 frame goes out
    on USB serial as "SCR <millis> <hex>", and single-char serial commands
    press keys. Frames are written in chunks sized to the free TX ring:
    HWCDC's connected flag can read false on a live link, and its
    not-connected path kept only the last 256 bytes of a frame.
    - tools/screens.py walks the menu from a fresh boot (the port open resets
    the board), stops if a key gets no reaction, never presses ok where it
    would toggle the radio, and can enable Force Out for the main screen.
    It saves raw frames plus pixel-exact PNG, animated WebP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
    [buttons.cpp, display.cpp]
2026-09-24 SmartLadaRevC fw 1.2.1: min level remaps the master, and local edits skip the easing
    - channels: callers hand over a duty 0..1; remap() applies gamma + the
    min/max window (0 = off, >0 -> [min, max]), shape() gamma only. The
    soft-start slew runs on the output duty, so a fade to 0 drops through
    min level in ~tau instead of parking there.
    - fx::compute: effect = shape(frame) * remap(master), so at master 1% an
    effect peaks at min level and keeps its shape; static = remap(staticBri
    * master) per lamp.
    - .ino: MASTER_SMOOTH_MS easing only for masters that came over Zigbee
    (zb::consumeMasterFromRadio). Buttons, web and any target of 0 apply at
    once; easing toward 0 held the lamps at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
    [SmartLadaRevC.ino, channels.cpp, zigbee.cpp]
2026-09-24 custom_pcb/revC: KiCad reordered the used-designators list
2026-09-24 site: smartlada.saschapo.me project page
    One static page in the cineink style (RU + EN), live on vdsina.
    - public/: index.html, exported images, orp pixel font as woff2, favicons,
    robots/sitemap/llms.txt/manifest, 404, IndexNow key. This directory is
    exactly what the server holds.
    - Headings use orp, the device's menu font, at multiples of its 12 px
    grid. orp Bold has no bold Cyrillic, so RU headings use the regular face.
    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
2026-09-24 site: play menu animations on a canvas instead of animated WebP
    The animations did not play on an iPhone. iOS freezes animated
    GIF/WebP/APNG when "Auto-Play Animated Images" is off, and muted autoplay
    video stops in Low Power Mode, so neither format is reliable. Each
    animation is now a 2-colour PNG strip of its frames plus the board's
    frame delays (anims.json), drawn on a <canvas> at an integer scale. It
    only runs while it is on screen. 3.4 KB for both instead of 26 KB.
    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
